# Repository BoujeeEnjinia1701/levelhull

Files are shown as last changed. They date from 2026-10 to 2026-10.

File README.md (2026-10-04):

# LevelHull

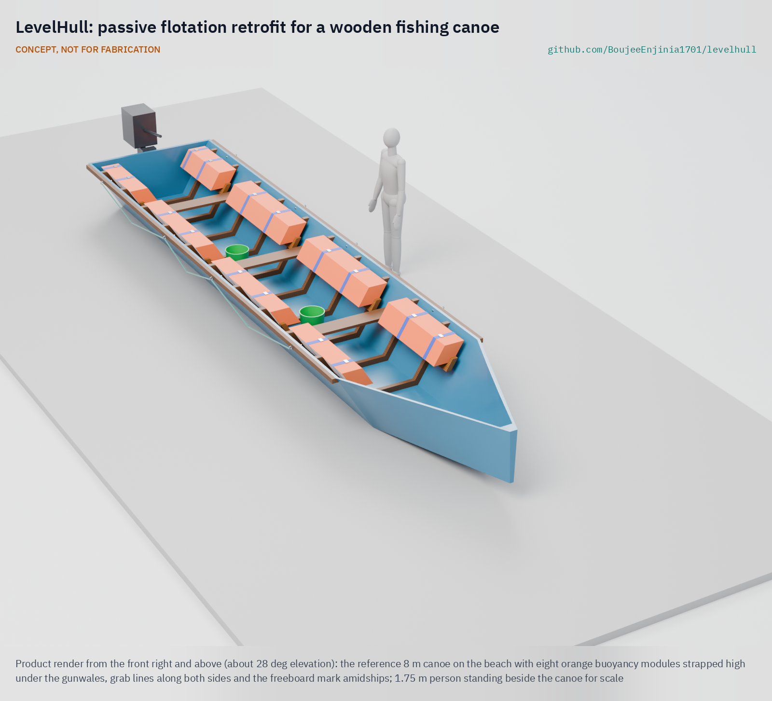
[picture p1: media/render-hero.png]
LevelHull: passive flotation retrofit for a wooden fishing canoe


     

**Area:** Food and water security · **TRL:** 3 of 9 (proof of concept on paper) · **Value-engineering target:** USD 1,000 for two prototype canoes (estimated cost of the constructable design USD 1,360) · **Difficulty:** 3 of 5

Adds passive buoyancy so a swamped wooden fishing canoe floats level and can be bailed.

> CONCEPT, NOT FOR FABRICATION. LevelHull is a TRL 3 design on paper: it has not been built or tested, it is not certified lifesaving equipment, and it is never a substitute for life jackets.

## Concept rationale

A swamped boat that stays afloat and upright is a platform the crew can hold, bail and paddle home. The US Coast Guard publishes a level flotation test that checks exactly this for small boats ([USCG](https://www.uscgboating.org/assets/PDF/downloads/FLOTATION.pdf)). Wooden fishing canoes in lakes and coastal waters elsewhere have no such built-in flotation. LevelHull is a retrofit kit: closed-cell foam modules fitted high along both sides of the hull, just under the gunwale, sized so that when a wave fills the canoe it floats level with freeboard, and the crew bails it out and carries on.

The kit is passive. Nothing moves, nothing inflates and nothing needs power, so it keeps working after years in the sun and in a wet hull. It is designed to be sized with a simple volume sheet and fitted by a local boatbuilder with hand tools. It is never a substitute for life jackets; it is a second layer for when a boat swamps.

## Burning platform

About 1,500 fishers drown on Lake Victoria every year, roughly 1,000 of them in bad weather; 69 % of those who drowned in storms wore no life jacket, and about half of incidents happen at night ([The Conversation](https://theconversation.com/lake-victoria-why-so-many-fishers-are-dying-and-what-can-be-done-about-it-232006)). Worldwide, more than 100,000 people die in fishing each year ([Pew, 2022](https://www.pew.org/en/research-and-analysis/issue-briefs/2022/11/more-than-100000-fishing-related-deaths-occur-each-year-study-finds)).

Progress is slowest where these boats are most common: the WHO African Region has cut its drowning rate by only 3 % since 2000 ([WHO, 2024](https://www.who.int/news/item/13-12-2024-drowning-deaths-decline-globally-but-the-most-vulnerable-remain-at-risk)). Certified lifesaving equipment is often not affordable or available there, which is why the RNLI supports locally built, sustainable lifesaving equipment in its international work ([RNLI](https://rnli.org/what-we-do/international/lifesaving-interventions/sustainable-lifesaving-equipment)).

## Where it could be used

### By industry

| Industry | Use |
| --- | --- |
| Small-scale capture fisheries | Retrofit flotation for wooden canoes on lakes, rivers and coasts |
| Boatbuilding (artisanal yards) | A documented add-on that local builders can size and fit |
| Fisheries management and safety at sea programmes | A low-cost measure alongside life jackets, weather warnings and training |
| Water transport and ferries on inland waters | Flotation for small wooden passenger and cargo canoes |
| Disaster response | Buoyancy modules reused in flood boats (for example the sibling LaneSkiff concept) |

### By country or region

| Country or region | Why it matters there |
| --- | --- |
| Lake Victoria (Kenya, Uganda, Tanzania) | About 1,500 fishers drown on the lake each year, about 1,000 in bad weather ([The Conversation](https://theconversation.com/lake-victoria-why-so-many-fishers-are-dying-and-what-can-be-done-about-it-232006)). |
| WHO African Region | The drowning rate has fallen by only 3 % since 2000 ([WHO, 2024](https://www.who.int/news/item/13-12-2024-drowning-deaths-decline-globally-but-the-most-vulnerable-remain-at-risk)). |
| Worldwide small-scale fisheries | More than 100,000 people die in fishing each year ([Pew, 2022](https://www.pew.org/en/research-and-analysis/issue-briefs/2022/11/more-than-100000-fishing-related-deaths-occur-each-year-study-finds)). |
| United States | The US Coast Guard publishes a level flotation test for small boats, the benchmark this kit will be tested against ([USCG](https://www.uscgboating.org/assets/PDF/downloads/FLOTATION.pdf)). |

## What sparked the idea

The idea started with the numbers from Lake Victoria: about 1,500 fishers drowning each year, most of them in bad weather, and 69 % of storm victims wearing no life jacket ([The Conversation](https://theconversation.com/lake-victoria-why-so-many-fishers-are-dying-and-what-can-be-done-about-it-232006)). Many of those deaths begin with a canoe filling with water. If a swamped canoe stayed afloat and level, the crew would have something to hold and a boat they could bail, even without a life jacket.

## Problem

Wooden fishing canoes swamp in storms and waves, and once full of water they can roll or sink, leaving the crew in the water. Most small-scale fishers in these boats cannot swim to shore and many wear no life jacket.

Full problem statement: [docs/01-problem.md](docs/01-problem.md)

## Concept

A retrofit kit of eight closed-cell polyethylene foam modules, four a side, fitted high under the gunwale on hardwood battens screwed to the canoe's frames and held by webbing straps. When a wave swamps the canoe, the modules cut the waterline along both sides, so it floats upright and level with about 100 mm of freeboard; the crew hold the grab lines, climb back in and bail. On paper, the 8 m reference canoe with a 15 hp motor and four crew holding on keeps 92 mm of freeboard at its lowest point, with 2.45 times the needed lift in reserve; the same foam laid on the floor would barely reach the surface and would lose all roll stiffness with a few kilograms more load. Never a substitute for life jackets.

Full design precis: [docs/02-concept.md](docs/02-concept.md) · Requirements: [docs/03-requirements.md](docs/03-requirements.md) · Calculations and sizing calculator: [docs/04-calcs/01-sizing.md](docs/04-calcs/01-sizing.md) · Prototype build plan: [docs/05-build-plan.md](docs/05-build-plan.md) · Design decisions: [docs/06-design-decisions.md](docs/06-design-decisions.md)

## Key components

- Eight buoyancy modules: four 50 mm layers of closed-cell polyethylene foam, 220 mm wide by 200 mm high, in sewn PVC tarpaulin covers
- Hardwood shelf battens screwed into the frames with M8 coach screws that stop short of the planks, and end chocks
- Two 50 mm webbing hold-down straps per module with stainless D-ring buckles
- Grab lines along both sides on through-bolted eye bolts
- Two bailers on lanyards, painted freeboard marks and a swamp test
- A plywood setting gauge for fitting, and an open sizing calculator for other canoes

## Building the prototype

The [prototype build plan](docs/05-build-plan.md) (LVH-BLD-001, plan, not yet built) is also the fitting guide for a local boatbuilder. It covers the kit component by component, with making sketches for the six made parts, close-ups of six joints and a picture for each of ten fitting steps. The foam is cut with a knife, the covers are sewn by a tailor, the battens are ripped and planed from hardwood, and everything is fitted with hand tools in about a day. No fitted canoe goes fishing before its fixings are pull-tested and it passes a swamp test in sheltered, shallow water with a safety boat and everyone in life jackets, which is TRL 4 work.

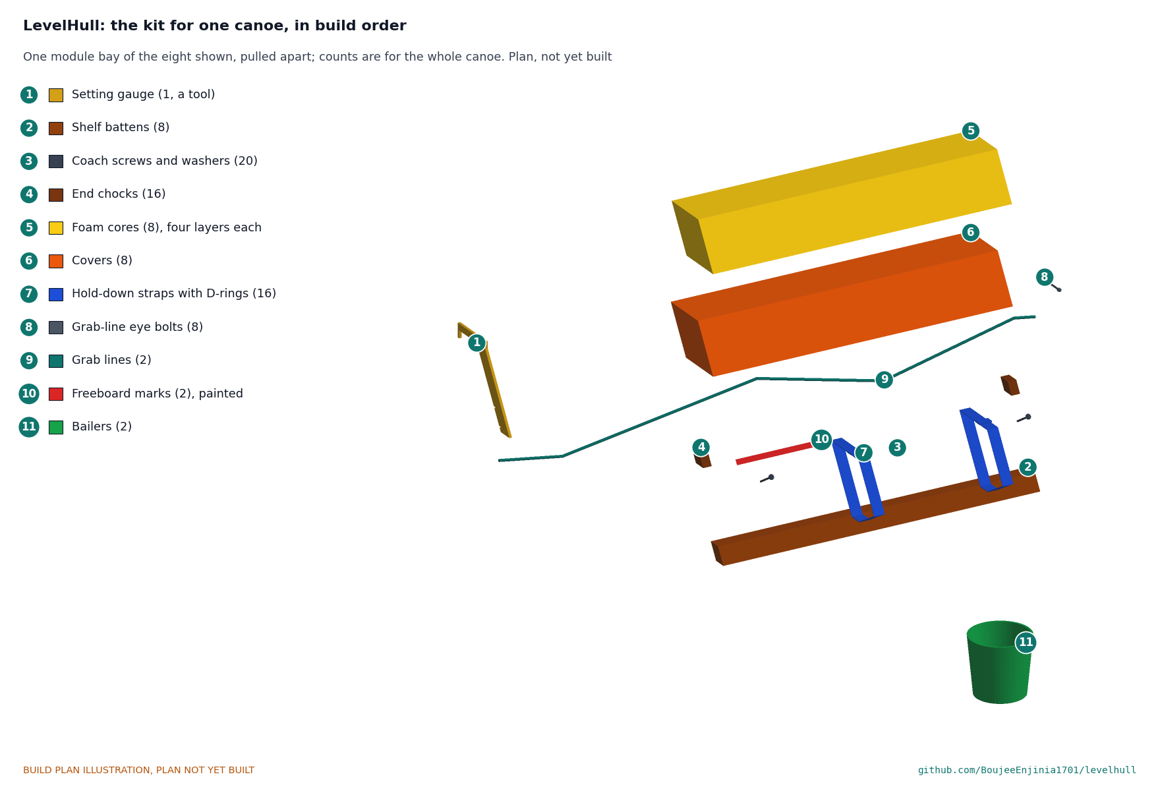
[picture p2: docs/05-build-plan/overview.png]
LevelHull build overview


## Safety

> Published as an open engineering reference, not certified lifesaving equipment.
>
> LevelHull is never a substitute for life jackets. Crews should wear life jackets whenever they are on the water.
>
> A swamped boat with flotation is still at risk in breaking waves and cold water; the kit buys time, it does not make a boat safe.
>
> Each fitted canoe must be swamp-tested in sheltered, shallow water with safety cover before use.
>
> Modules must be fixed so they cannot tear free when the boat is full of water; each fixing carries at least twice its share of the full lift.
>
> With all four crew holding one side, the low gunwale comes within about 30 mm of the water: spread out along both grab lines.
>
> This design is published as an open engineering reference. It is not certified equipment.

## Repository layout

| Folder | Contents |
| --- | --- |
| `docs/` | Problem, concept, requirements, calculations and design decisions |
| `cad/src/` | build123d Python source, the source of truth for all geometry |
| `cad/step/`, `cad/stl/` | Exported models for FreeCAD, other CAD tools and printing |
| `cad/drawings/` | 2D sketches and dimensioned drawings |
| `bom/` | Bill of materials |
| `electronics/` | KiCad schematics and PCB layouts |
| `firmware/` | Microcontroller code |
| `media/` | Renders, perspectives and photos |
| `build-log/` | Dated prototyping notes |

## Documentation

Controlled documents follow the portfolio [documentation standard](.kit/STANDARDS.md). Each carries a document ID (LVH-PRC-001 for the precis), a version and a revision history. Branded PDFs are built with `python .kit/render.py` and attached to GitHub Releases when a document is tagged, for example `LVH-PRC-001/v1.0`.

## Credits

Designed by Amish Chadha at Design Molecule Labs. See [CONTRIBUTORS.md](CONTRIBUTORS.md) for roles. To cite this design, use [CITATION.cff](CITATION.cff) (GitHub shows it as "Cite this repository").

AI assistance (Claude) was used to accelerate prototype documentation and first-pass research. Design direction and all decisions are Amish Chadha's, recorded in this repository's decision records (`docs/decisions/`).

## Licenses

- **Hardware** (CAD, drawings, BOM, electronics): [CERN-OHL-S v2](LICENSE)
- **Software** (firmware, scripts, notebooks): [MIT](LICENSE-SOFTWARE)

A project of the [Design Molecule](https://designmolecule.com) lab.

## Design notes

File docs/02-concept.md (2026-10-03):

---
doc_id: LVH-PRC-001
title: LevelHull design precis
project: LevelHull
doc_type: Precis
version: "0.3"
status: Draft
date: '2026-10-03'
author: Amish Chadha
license: CERN-OHL-S-2.0
revisions:
- version: "0.1"
  date: '2026-09-30'
  author: Amish Chadha
  change: Initial scaffold
- version: "0.2"
  date: '2026-10-03'
  author: Amish Chadha
  change: TRL 2 and 3 update; modules high under the gunwale, constructable kit (LVH-DDR-001, LVH-DDR-002), first-order numbers, safety
- version: "0.3"
  date: '2026-10-03'
  author: Amish Chadha
  change: Modules widened from 200 to 220 mm (LVH-DDR-003); first-order numbers updated
---

# LevelHull design precis

Adds passive buoyancy so a swamped wooden fishing canoe floats level and can be bailed.

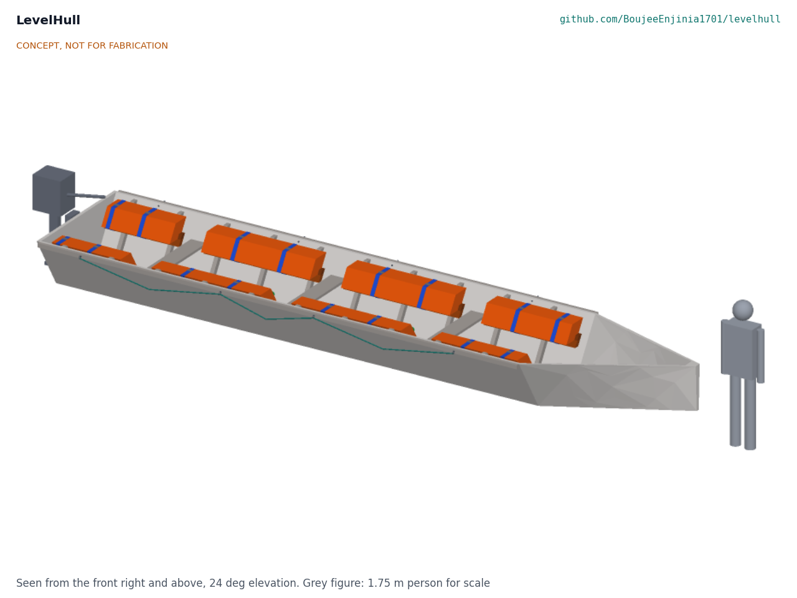
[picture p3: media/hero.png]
LevelHull fitted in the reference canoe


*Figure 1. The kit fitted in the 8 m reference canoe, with a 1.75 m person for scale (concept render).*

## How it works

Eight buoyancy modules of closed-cell polyethylene foam, four on each side, sit high along the inside of the canoe, just under the gunwale, between the thwarts. Each module rests on a hardwood shelf batten screwed to the canoe's frames and is held down by two webbing straps. When a wave fills the canoe, the water inside is simply part of the lake: it carries nothing, and the canoe now floats on its foam and timber alone. Because the modules are high, they cut the waterline along both sides, like the floats of a raft, so the swamped canoe floats upright and level with its gunwale about 100 mm out of the water. The crew hold the grab lines along both sides, then climb in and bail with the two bailers. A painted freeboard mark on each side and a swamp test in sheltered water let the owner check the fit.

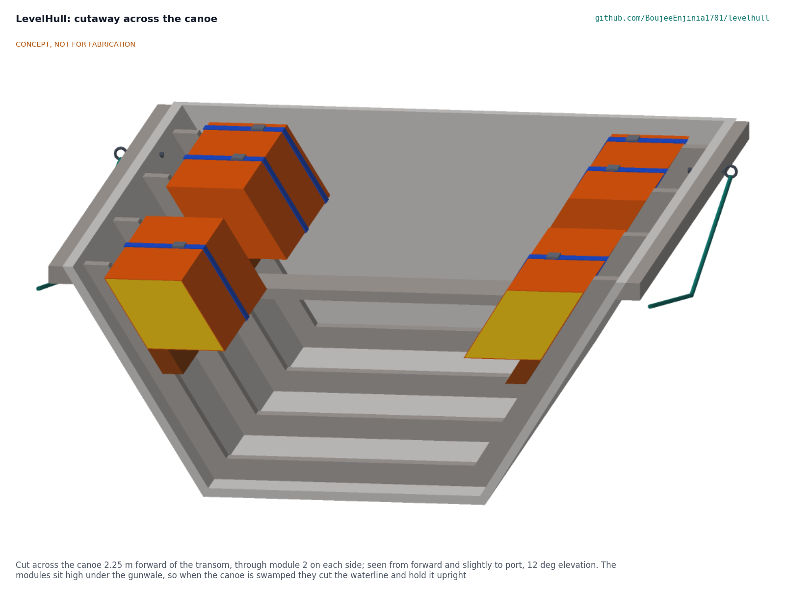
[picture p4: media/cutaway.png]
Cutaway across the canoe


*Figure 2. Cut across the canoe through module 2: the modules lie on the frame faces under the gunwale.*

## Components

*Table 1. Components (numbers are BOM lines in `bom/bom.csv`).*

| # | Component | Role |
| --- | --- | --- |
| 1 | Setting gauge | Plywood fitting tool that marks the batten height on every frame |
| 2 | Shelf battens | Hardwood rails screwed to the frames; each carries one module |
| 3 | Coach screws M8 x 100 | One into every frame a batten crosses; take the module's lift into the frames |
| 4 | End chocks | Stop the module sliding fore and aft |
| 5 | Foam cores | Four 50 mm layers of closed-cell polyethylene foam: the buoyancy |
| 6, 7 | Covers | Sewn PVC tarpaulin sleeves that shield the foam from sun, fuel and abrasion |
| 8, 9 | Hold-down straps and D-ring buckles | Two webbing loops per module round module and batten |
| 10, 11 | Grab-line eye bolts and grab lines | Something to hold for the crew in the water |
| 12 | Bailers | Two 10 L buckets on lanyards |
| 13 | Swamp test kit | Painted freeboard marks and an inclinometer for the swamp test |
| 14 | Sealer | Seals batten ends, chocks and every screw hole |
| (calc) | Sizing calculator | `docs/04-calcs/sizing.py` sizes the modules for any canoe (MIT) |
| (BLD) | Fitting guide | The build plan, LVH-BLD-001 |

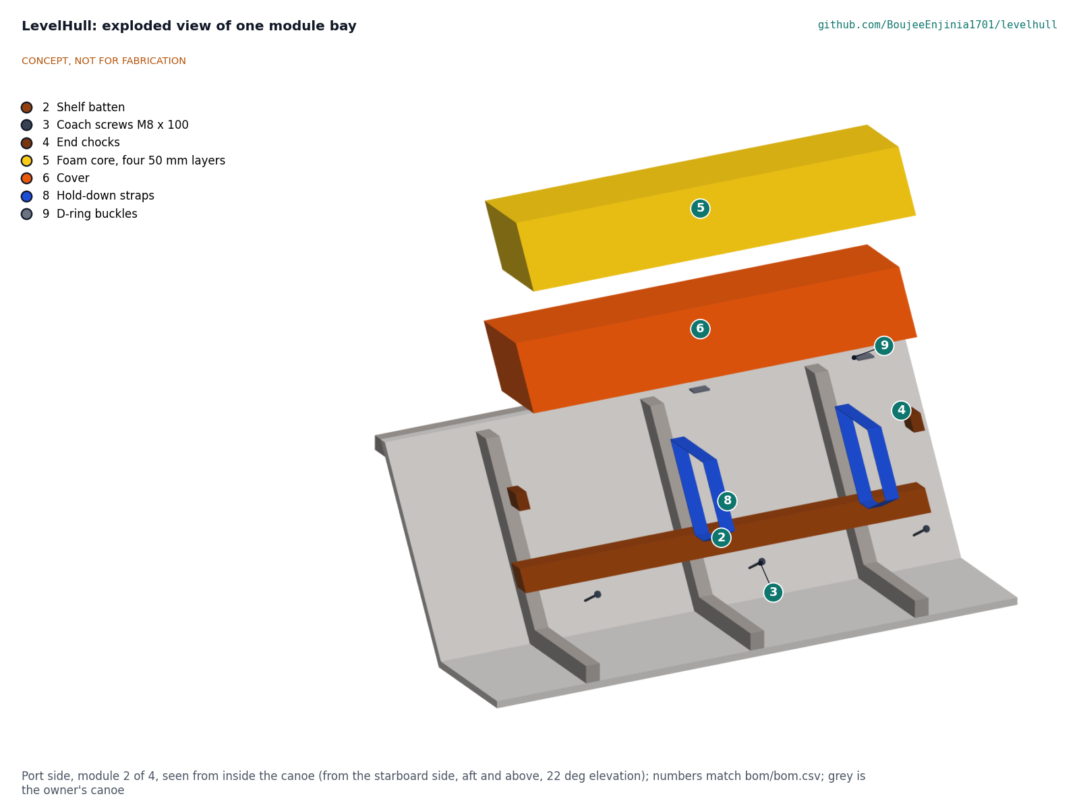
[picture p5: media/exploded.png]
Exploded view of one module bay


*Figure 3. One module bay pulled apart; numbers match the BOM.*

## Key design choices

All decided under Amish's pre-approval of 2026-10-03 (LVH-DDR-001 and LVH-DDR-002).

- **High, not low.** Modules under the gunwale give the swamped canoe roll stiffness; on the floor the same foam leaves it nearly neutral in roll (Table 2).
- **Foam, not chambers.** Closed-cell polyethylene foam keeps its lift when cut or punctured and resists fuel. Polystyrene is excluded (fuel dissolves it), as is open-cell foam (it soaks up water).
- **No credit for the wood.** Wet timber is counted as exactly as dense as water. Lighter timber is a margin, not part of the design.
- **Into the frames, not through the hull.** Battens are screwed into the frames with coach screws that stop 10 mm short of the planking; the only new hull holes are the eight eye bolts in the top plank, above every waterline.
- **Simple parts a beach yard can make.** Ripped hardwood battens, foam strips cut with a knife, sewn tarpaulin sleeves and webbing loops with D-rings; no glue, no moving parts.
- **One reference canoe, a calculator for the rest.** The design is checked on an 8 m, 1.6 m beam canoe with a 15 hp outboard and four crew; the calculator gives the module run for other hulls.

## First-order numbers

From LVH-CAL-001 (`docs/04-calcs/sizing.py`); fresh water, design load unless stated.

*Table 2. First-order numbers.*

| Quantity | Value | Assumption |
| --- | --- | --- |
| Modules | 8, each 220 mm wide x 200 mm high, 4.78 m a side, 0.42 m3 | Reference canoe, thwarts at 1.2, 3.0 and 4.8 m |
| Design net load | 118 kg | Four crew holding on (20 % of 75 kg each), 36 kg motor, anchor, nets, catch |
| Freeboard, swamped | 113 mm amidships, 92 mm lowest (transom) | Timber at 1,000 kg/m3; trim 0.39 deg stern down |
| Reserve | Carries 290 kg at 50 mm freeboard: 2.45 times the design load | |
| Roll stiffness | 761 kg m per radian (metacentric height 3.1 m) | Waterplane of modules and planks |
| Same foam on the floor | Foam top just at the water: heels 10.6 deg with four crew on one side, and no roll stiffness at all with 5 kg more load | For comparison only |
| Four crew on one side | 3.9 deg heel, 44 mm freeboard on the low side | |
| Largest module lost and 5 % water uptake | Still floats, 25 mm freeboard | |
| Bailing to 200 mm freeboard | 1.17 m3, about 6 minutes for two crew (estimate) | 100 L per minute each, calm water |
| Kit mass | 69 kg; dry canoe sits about 11 mm deeper | |
| Share of the inside volume | 8.4 % | |
| Parts cost | USD 682 per canoe; USD 1,360 for two | Value-engineering target USD 1,000 for two |

## Patent design-arounds

From the preliminary patent, trademark and prior-art screen (not legal advice):

- Passive foam only; no inflation and no inflation mechanism (avoids US9139267B2, active to about 2032). Sealed chambers are not used either.
- The hull-volume sizing method is published openly in `docs/04-calcs/sizing.py` under MIT.

## Shared blocks

- Foam module and fixing pattern offered to the sibling LaneSkiff concept (proposed there, not here).
- CalRig proof-load for strap and screw pull-out at TRL 4.

## Safety

> **Safety:** LevelHull is published as an open engineering reference, not certified lifesaving equipment. It is never a substitute for life jackets: crews should wear life jackets whenever they are on the water. A swamped canoe with flotation is still at risk in breaking waves, at night and in cold water; the kit buys time to bail and be seen, it does not make the boat safe. With all four crew holding one side the low gunwale comes within about 30 mm of the water, so crews spread out along both grab lines. Every fitted canoe has its fixings pull-tested and is swamp-tested in sheltered, shallow water with a safety boat and every person in a life jacket before use (LVH-BLD-001, sections 5 and 6). The modules must be fixed so they cannot tear free when the canoe is full of water; each fixing carries at least twice its share of the full lift.

This design is published as an open engineering reference. It is not certified equipment.

## Open questions

None for the design; decisions are in the register (`docs/06-design-decisions.md`), and facts that need real hulls and parts are listed there under "To confirm when parts are bought".

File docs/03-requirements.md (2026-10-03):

---
doc_id: LVH-REQ-001
title: LevelHull requirements
project: LevelHull
doc_type: Requirements
version: "0.3"
status: Draft
date: '2026-10-03'
author: Amish Chadha
license: CERN-OHL-S-2.0
revisions:
- version: "0.1"
  date: '2026-09-30'
  author: Amish Chadha
  change: Initial scaffold
- version: "0.2"
  date: '2026-10-03'
  author: Amish Chadha
  change: Targets fixed on the reference canoe; R11 to R13 added; TRL 3 status from LVH-CAL-001
- version: "0.3"
  date: '2026-10-03'
  author: Amish Chadha
  change: 'Modules widened 10 % for R12 and R13 on Amish''s decision of 2026-10-03 ("10A", LVH-DDR-003); targets unchanged; TRL 3 status updated from LVH-CAL-001 v0.2'
---

# LevelHull requirements

Requirements for the kit fitted to the reference canoe (8.0 m, 1.6 m beam, 0.65 m deep, 15 hp outboard, four crew). Other hulls are sized to the same requirements with the calculator. Status is the paper result at TRL 3 from LVH-CAL-001; every requirement is verified by test at TRL 4.

*Table 1. Requirements.*

| ID | Requirement | Target | Verification (TRL 4) | TRL 3 status |
| --- | --- | --- | --- | --- |
| R1 | Swamped canoe stays afloat with its design load | Design net load 118 kg (crew holding on, motor, gear, catch) carried for at least 1 h | Swamp test in sheltered water, based on the USCG level flotation method | Met on paper: carries 2.45 times the design load at 50 mm freeboard |
| R2 | Freeboard when swamped | At least 50 mm at the lowest point of the gunwale, design load, fresh water | Measured during swamp test | Met on paper: 92 mm (113 mm amidships) |
| R3 | Floats level when swamped | Heel and trim each within 10 deg, crew in the water not holding on, and with crew holding on both sides | Inclinometer reading during swamp test | Met on paper: 0.0 deg heel, 0.14 deg trim; 0.39 deg trim with crew holding on |
| R4 | Crew can bail the swamped canoe | Two crew bail to 200 mm freeboard in 15 min or less, calm water | Timed bail-out trial | Met on paper (estimate): about 6 min |
| R5 | Volume taken from the working space | 10 % or less of the inside volume | Measured on the fitted canoe | Met: 8.4 % |
| R6 | Material water uptake | Foam gains less than 5 % of its lift in mass after 30 days immersed | Immersion and weighing of samples | Met on supplier data (under 1 % by volume); to confirm by test |
| R7 | Fixing strength | Each fixing holds 2 times its share of the full lift without pull-out | CalRig proof-load of a batten, screws and strap in a test panel | Met on paper: screw factor 5.0, D-ring 13.3, webbing 66 |
| R8 | Fitting | A local builder fits the kit in one working day with hand tools, modules made beforehand | Timed fitting with the partner builder | Met on paper (estimate): about 6.3 h |
| R9 | Durability | No cracking or loss of lift after 12 months of normal use | Field inspection of pilot canoes | Cannot be shown on paper |
| R10 | Cost | Parts for kits on two canoes against the value-engineering target of USD 1,000 | Costed bill of materials | USD 1,360: over the value-engineering target by USD 360 |
| R11 | Reserve lift | At least 1.5 times the design net load carried at 50 mm freeboard | Swamp test with added weights | Met on paper: 2.45 |
| R12 | Damage tolerance | Still floats with the largest module lost and 5 % water uptake | Swamp test with one module removed | Met on paper: 25 mm freeboard, 1.5 deg heel (was 9 mm before the modules were widened) |
| R13 | Crew on one side | Heel within 10 deg with all four crew holding one grab line | Swamp test | Met on paper: 3.9 deg (low-side freeboard 44 mm, was 31 mm) |

## Assumptions

- Modules 220 mm wide by 200 mm high (widened from 200 mm on Amish's decision 10A of 2026-10-03: "1A 2A 3A 4A 5A 6A 7A 8A 9A 10A 11A").
- Reference canoe: planked, flat bottom 0.8 m wide, sides flared 31.6 deg, frames 50 x 60 mm at 600 mm, thwarts at 1.2, 3.0 and 4.8 m from the transom.
- Wet hull timber is counted as exactly as dense as water (no net lift from the hull).
- A crew member holding on with head and shoulders out puts 20 % of a 75 kg body on the canoe.
- Closed-cell polyethylene foam of about 30 kg/m3 with under 1 % water uptake by volume is available to the first partner.
- Owners accept 8.4 % of the inside volume, high along the sides, in exchange for flotation.
- The USCG level flotation method is adapted as a design benchmark only; the kit is not certified to it.

> **Safety:** These requirements describe flotation for the boat, not for people. Life jackets remain the first line of defence; the swamp tests behind R1 to R4 and R11 to R13 are run in sheltered, shallow water with a safety boat and every person in a life jacket.

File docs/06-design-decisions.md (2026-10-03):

---
doc_id: LVH-DEC-001
title: LevelHull design decisions register
project: LevelHull
doc_type: Design decisions register
version: "0.2"
status: Draft
date: '2026-10-03'
author: Amish Chadha
license: CERN-OHL-S-2.0
revisions:
- version: "0.1"
  date: '2026-10-03'
  author: Amish Chadha
  change: Register opened; all decisions made under Amish's 2026-10-03 pre-approval
- version: "0.2"
  date: '2026-10-03'
  author: Amish Chadha
  change: Decision 10A recorded (modules widened for R12 and R13, LVH-DDR-003); value engineering updated
---

# LevelHull design decisions register

Every design decision still to be made, and every decision made, in one place. Each decision is argued in full in its decision record under `docs/decisions/`; this register is the index Amish works from. The build plan (`docs/05-build-plan.md`) describes the design as it stands and does not list decisions.

> **Safety:** Several entries below set safety limits (where the modules sit, no credit for the wood, screws kept out of the planking, the pull test and the swamp test rules). Each takes the conservative option and names the evidence that would relax it. LevelHull is never a substitute for life jackets.

## Open decisions

None. All decisions were made under Amish's 2026-10-03 pre-approval and his requirement decisions of 2026-10-03.

## To confirm when parts are bought

These are facts that can only be settled with real parts, a real canoe or the first partner. None changes a decision; each may change a size or a limit.

*Table 1. Items to confirm.*

| # | What to confirm | Why it matters | Source |
| --- | --- | --- | --- |
| 1 | Foam: density about 30 kg/m3, water uptake under 1 % by volume, fuel resistance, on the supplier's data sheet; then 30 days immersion of samples | R6, and every freeboard figure | LVH-CAL-001, A6; LVH-DDR-002, A4 |
| 2 | First canoes: frame spacing (600 mm assumed) and depth (60 mm), side slope, thwart positions, timber, gunwale and strake sizes | Batten height, screw length, module lengths and the gauge | LVH-DDR-002, A1 |
| 3 | Hull mass and timber volume of the first canoes | Size of the unclaimed wood margin (D3) | LVH-DDR-001, D3 |
| 4 | Condition of the frame-to-plank fastenings | Each frame takes up to 0.19 kN of lift | LVH-DDR-002, A3 |
| 5 | Webbing breaking strength (10 kN assumed), D-ring pair (4 kN) and coach screw sideways strength in the canoe's timber (1.5 kN) | R7 factors | LVH-CAL-001, section 7 |
| 6 | Real motor mass and the gear, catch and crew of the partner's fishery | Design net load of 118 kg | LVH-CAL-001, A3 to A5 |
| 7 | Bailing rate with the local bailer (100 L per minute per person assumed) | R4 | LVH-CAL-001, A8 |
| 8 | Price of polyethylene foam sheet near the first fishery (USD 55 a sheet assumed) | Foam is 48 % of the kit cost | `bom/bom.csv`, line 5 |

## Value engineering

Value-engineering target: USD 1,000 (a hypothetical control target, not a limit) for the kits for two prototype canoes. Estimated cost of the constructable design: USD 1,360 (USD 360 over the target); one kit is USD 682. Main cost drivers and savings worth trying:

- The largest lines are the foam (USD 330 a kit, six sheets), the tarpaulin covers and their sewing parts (USD 100), the battens (USD 56) and the coach screws (USD 43).
- Savings worth trying: buy foam by the block from a fishing-float or packaging maker and cut it locally (perhaps USD 100 a kit); hot-galvanised screws and D-rings in place of stainless where the canoe is used in fresh water (about USD 30); covers from used truck tarpaulin in good condition (about USD 50); a three-layer module on hulls whose weighed timber gives a proven wood margin (D3), cutting foam by a quarter.
- The gauge is made once per hull shape and the calculator is free, so a builder fitting a fleet of the same canoe spreads those costs.

## Decisions made

*Table 2. Decisions made.*

| Date | Decision | Decided by | Record |
| --- | --- | --- | --- |
| 2026-10-03 | TRL 2 review items D1 to D10: modules high under the gunwale, not low; closed-cell polyethylene foam in covers, not chambers or polystyrene; no lift counted from the hull timber; one reference canoe (8.0 m, 15 hp, four crew) with an open calculator for others; crew in the water at 20 % of body weight; re-entry step stays parked; grab lines along both sides; life jacket message in every document and test; first co-design candidates (a beach management unit on the Kenyan shore of Lake Victoria with its canoe builders, a regional fisheries research institute, a sea-safety programme; none approached yet); R11 to R13 added; pitch, problem, design-arounds and budget unchanged | Amish, pre-approval of 2026-10-03: "start with the first 14 repos from the list of 29 projects. I pre-approve the batch runs along with any recommendations you come up with. I also accept any cost overruns or variations from the assumed scope cost." | LVH-DDR-001 |
| 2026-10-03 | Design for construction, changes C1 to C12: modules high on the frame faces; four modules a side between thwarts; parallelogram stacks of equal strips; shelf battens; coach screws into frames only, 10 mm short of the planks; end chocks; webbing loops with D-ring buckles in the bays; no glue; sewn tarpaulin covers; setting gauge; grab-line eye bolts above the waterline; freeboard marks and bailers | Amish, same pre-approval | LVH-DDR-002 |
| 2026-10-03 | Assumptions A1 to A5: frames at most 600 mm apart and 60 mm deep, else shorter screws and a third frame, never through the planks; timber as dense as water; sound frame fastenings checked before fitting; foam data to confirm; fixing strengths to confirm | Amish, same pre-approval | LVH-DDR-002 |
| 2026-10-03 | No fishing use before the batten pull test, a one-bay proof load to twice the full lift, and a swamp test in sheltered shallow water with a safety boat and every person in a life jacket (conservative; a gate, not relaxed) | Amish, same pre-approval | LVH-BLD-001, sections 5 and 6 |
| 2026-10-03 | Crews spread along both grab lines: with all four on one side the low gunwale comes within 31 mm of the water (44 mm with the wider modules of LVH-DDR-003) (conservative; relaxed only if a swamp test shows more) | Amish, same pre-approval | LVH-CAL-001, section 4 |
| 2026-10-03 | Appearance model departures: a sand beach slab and a 1.75 m mannequin beside the canoe, and a repeated cut-back module bay for the detail view, drawn for the renders only; canoe topsides shown painted | Amish, same pre-approval | docs/REVIEW.md, TRL 3 section |
| 2026-10-03 | Decision 10A for R12 and R13: foam modules enlarged about 10 % by widening them from 200 to 220 mm (height, lengths, positions and fixings unchanged). R12: 25 mm lowest freeboard with the largest module lost (was 9 mm); R13: 3.9 deg heel, 44 mm on the low side (was 4.0 deg, 31 mm); kit 68.9 kg; USD 1,360 for two canoes | Amish, 2026-10-03: "1A 2A 3A 4A 5A 6A 7A 8A 9A 10A 11A" | LVH-DDR-003 |

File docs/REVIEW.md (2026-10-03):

# Review note: LevelHull

## Session 2026-09-30: scaffolded

### What was done

- Repository created from kit 1.6.0 at TRL 1, target TRL 2.
- `docs/01-problem.md` (LVH-PRB-001 v0.1): problem with cited evidence, users, environment, constraints, prior work, open questions.
- `docs/02-concept.md` (LVH-PRC-001 v0.1): how it works, components, patent design-arounds, shared blocks, safety.
- `docs/03-requirements.md` (LVH-REQ-001 v0.1): 10 proposed requirements.
- `README.md` with concept rationale, burning platform, where it could be used, and what sparked the idea.

### Next

- Run `/populate` to bring the repo to a strong TRL 2 with concept media.

## Session 2026-10-03: TRL 2 (populate)

Run as the first half of `/to-trl3` under Amish's pre-approval of 2026-10-03: "start with the first 14 repos from the list of 29 projects. I pre-approve the batch runs along with any recommendations you come up with. I also accept any cost overruns or variations from the assumed scope cost." Kit 1.7.0 installed.

### What was done

- `docs/01-problem.md` (LVH-PRB-001 v0.2): constraints restated (value-engineering target, no new holes below the waterline), open questions settled, first co-design candidates, safety section.
- `docs/02-concept.md` (LVH-PRC-001 v0.2): how it works, components with BOM numbers, key design choices, first-order numbers, design-arounds kept, safety.
- `docs/03-requirements.md` (LVH-REQ-001 v0.2): 13 measurable requirements (R11 to R13 added) with TRL 3 status.
- Concept media from `cad/src/concept_media.py`: `media/hero.png` (1.75 m person for scale), `media/cutaway.png` (a cut across the canoe), `media/exploded.png` (one module bay with BOM callouts), `media/concept-blueprint.png`, `.pdf` and `.svg` (LVH-DWG-010), `media/model.glb` (3.4 MB, coarse tessellation) and `media/viewer.html`. No flow diagram: the kit moves no energy or material.
- `bom/bom.csv`: 14 priced lines.

### Results

- The TRL 1 arrangement (foam low along the sides) does not work: with the same foam on the floor the swamped canoe has almost no roll stiffness and rolls over with the crew on one side. Modules high under the gunwale fix this.

### Requirements not met

- R10: over the value-engineering target (see TRL 3).
- R9 cannot be shown on paper.

### Decisions made under the pre-approval

LVH-DDR-001, items D1 to D10: modules high under the gunwale; closed-cell polyethylene foam in covers; no lift counted from the hull timber; one reference canoe with an open calculator; crew in the water at 20 % of body weight; re-entry step stays parked; grab lines; life jacket message everywhere; first co-design candidates (not approached); R11 to R13 added.

### Safety concerns

- A swamped canoe that floats is still dangerous in breaking waves, at night and in cold water; the kit is never a substitute for life jackets, and it must not be promoted as one.

## Session 2026-10-03: TRL 3 (advance and build plan)

Run as the second half of `/to-trl3` under the same pre-approval, which counts as the TRL 2 approval. Not committed or pushed (batch run).

### What was done

- `cad/src/model.py`: parametric build123d model of the kit in the reference canoe (8.0 m, 1.6 m beam, 0.65 m deep, flared 31.6 deg, 15 hp outboard); 126 of 126 constructability checks pass (overlaps with planks, frames and thwarts; module, batten and chock contact; screw depth in the frames and clear of the planks; straps in the bays; eye bolts through the strake; gauge fit; clear width). Exports `cad/step/levelhull-assembly.step`, `levelhull-kit.step`, `reference-canoe-context.step`, the four foam cores, chock and gauge, and STL of the battens, chock and gauge.
- `docs/04-calcs/01-sizing.md` (LVH-CAL-001 v0.1) with `docs/04-calcs/sizing.py` (also the MIT sizing calculator) and `results.csv`: swamped equilibrium, heel and trim, off-design cases, high against low placement, space and bailing, fixings, fitting time, cost and a sizing sheet for other hulls.
- `cad/src/sheets.py`: general arrangement `cad/drawings/LVH-DWG-001` (SVG, PDF, PNG) at Rev P2, with section A-A at 1:20.
- `cad/src/build_plan_media.py`: `docs/05-build-plan/overview.png`, 6 making sketches `cad/drawings/LVH-DWG-101` to `106`, 6 joint close-ups and 10 step pictures.
- `docs/05-build-plan.md` (LVH-BLD-001 v0.1), `docs/06-design-decisions.md` (LVH-DEC-001 v0.1), `docs/decisions/0001-trl2-review-decisions.md` (LVH-DDR-001) and `docs/decisions/0002-design-for-construction.md` (LVH-DDR-002).
- `cad/src/product_model.py` (appearance model) and render scenes exported with `.kit/export_views.py` to `/home/claude/renders/levelhull` for hero, exploded and detail views; photoreal renders and cards are made on Amish's Mac.
- `project.yaml`: trl 3, trl_target 3, `design_state: constructable`, evidence listed; `budget_usd` unchanged. README leads with `media/render-hero.png` and has a "Building the prototype" section.

### Results

- Eight modules, 200 x 200 mm, 4.78 m a side, 0.38 m3 of foam; kit 67 kg; 7.6 % of the inside volume.
- Swamped at the design load (118 kg net: four crew holding on, 36 kg motor, gear, catch), fresh water, no lift counted from the timber: 105 mm freeboard amidships, 80 mm at the lowest point, trim 0.45 deg; roll stiffness 742 kg m per radian; 2.2 times the design load carried at 50 mm freeboard.
- Same foam on the floor: 17 kg m per radian; rolls over with four crew on one side.
- Four crew on one side: 4.0 deg heel, 31 mm low-side freeboard. Largest module lost and 5 % uptake: still afloat with 9 mm. Typical 750 kg/m3 timber would add about 58 mm.
- Bailing to 200 mm freeboard: about 6 minutes for two crew (estimate). Fixing factors: coach screw 5.5, D-ring 14.6, webbing 73. Fitting about 6.3 hours.
- Value-engineering target: USD 1,000. Estimated cost of the constructable design: USD 1,350 for two canoes (USD 350 over the target); USD 677 for one kit.

### Requirements not met

- R10: over the value-engineering target by USD 350. Foam is 49 % of a kit; the overrun is accepted under the pre-approval and `budget_usd` is unchanged.
- R9 (12 months without loss of lift) and the test half of R6 cannot be shown on paper.
- R12 is met with a small margin (9 mm), and R13 leaves only 31 mm on the low side; both are recorded as operating rules, not redesigned.

### Decisions made under the pre-approval

- LVH-DDR-002: design for construction, changes C1 to C12 and assumptions A1 to A5.
- No fishing use before the pull test, a one-bay proof load and a swamp test with a safety boat and life jackets.
- Crews spread along both grab lines.
- Appearance model departures (renders only): a sand beach slab under the canoe, a 1.75 m mannequin standing beside it, a repeated cut-back module bay for the detail view, and the canoe topsides shown painted blue.

### Build plan findings

- Design changes for construction (2026-10-03), all in LVH-DDR-002: modules high on the frame faces; four modules a side between the thwarts; parallelogram stacks of equal foam strips, no glue; shelf battens; coach screws into the frames only, tips 10 mm short of the planks; end chocks; webbing loops with D-ring buckles in the bays between frames; sewn tarpaulin covers with laced ends; a plywood setting gauge; grab-line eye bolts above the waterline; freeboard marks and bailers on lanyards.
- The only new holes in the hull are the eight eye bolt holes in the top plank, above every waterline.
- Items to confirm with real parts and hulls (foam data, frame sizes, hull mass, frame fastenings, fixing strengths, real loads, bailing rate, foam price) are in LVH-DEC-001.

### Safety concerns

- Flotation for the boat, not for people: never a substitute for life jackets, not certified. Safety stops S1 to S5 in LVH-BLD-001 gate drilling, the first swamp test, entering the water, filling the canoe and fishing use.
- A floating swamped canoe can still roll in breaking waves; the kit buys time to bail and be seen.
- With all crew on one side the low gunwale is 31 mm from the water; crews must spread out.
- The fixings must not tear free: each carries at least twice its share of the full lift on paper, and the pull test and proof load confirm it before any swamp test.

### Recommended next step

The design looks ready for TRL 4 once Amish chooses to start it: fit one kit to a partner's canoe, pull-test and proof-load the fixings with CalRig, and run the first checks in LVH-BLD-001 section 5 in sheltered water with the first co-design candidate.

## 2026-10-03: photoreal renders

Rendered with Blender Cycles on Amish's Mac from `cad/src/product_model.py`; captioned with `.kit/photo_caption.py`; `media/card.png` and `media/social-preview.png` made with `.kit/cards.py`. Views: hero, exploded, detail. image_qc passes and `render.py --check` has no FAIL.

2026-10-03: hero render reframed so the product fills the frame (levelhull).

## 2026-10-03: Amish's requirement decisions carried out

Amish chose option A on every requirement decision put to him: "1A 2A 3A 4A 5A 6A 7A 8A 9A 10A 11A". For LevelHull this is decision 10A (R12 and R13): enlarge the foam modules about 10 %. Not committed or pushed (batch run).

### Changes

- Modules widened from 200 to 220 mm (level width), 200 mm high as before; lengths, positions, battens, chocks, screws and eye bolts unchanged (`cad/src/model.py`). 0.42 m3 of module in all (was 0.38 m3). New model check: four strips of the module width come from a 1,000 mm foam sheet. 127 of 127 constructability checks pass. STEP and STL regenerated.
- `docs/04-calcs/sizing.py` takes the module width from the model everywhere (fixing loads, sizing sheet) and now computes the strap webbing (K3) and the floor comparison with 5 kg more load (F20). `docs/04-calcs/01-sizing.md` v0.2 and `results.csv` re-run.
- `bom/bom.csv`: foam strips 216 mm wide, four to a sheet, still six sheets (no spare strip); tarpaulin 14 to 15 m2 at the same USD 5.00 per m2; straps cut 1.25 m (20 m of the 25 m bought).
- `docs/03-requirements.md` v0.3 (targets unchanged, status updated), `docs/02-concept.md` v0.3, `docs/01-problem.md` v0.3, `docs/05-build-plan.md` v0.2 (foam strips, cover panel 1,040 mm wide, straps 1.25 m), README figures, `docs/decisions/0002-design-for-construction.md` v0.2 (cross-reference), new `docs/decisions/0003-wider-modules-r12-r13.md` (LVH-DDR-003), `docs/06-design-decisions.md` v0.2.
- Pictures: general arrangement `cad/drawings/LVH-DWG-001` at Rev P3; making sketches LVH-DWG-101 to 106, overview, joints and steps regenerated (foam core, cover and strap sketches carry the new sizes); concept media (hero, cutaway, exploded, blueprint, `model.glb`). Appearance model scenes re-exported to `/home/claude/renders/levelhull` (hero, exploded, detail).

### New results

- R12 (still floats with the largest module lost and 5 % uptake): 25 mm lowest freeboard, 1.5 deg heel (was 9 mm). Met on paper with a usable margin.
- R13 (heel within 10 deg with all four crew on one grab line): 3.9 deg, low-side freeboard 44 mm (was 4.0 deg and 31 mm). Met on paper; the low side is still under 50 mm, so the rule that crews spread along both grab lines stays.
- Also changed: R2 92 mm lowest freeboard (was 80); R1 and R11 reserve 2.45 (was 2.17); R3 trim 0.39 deg; R5 8.4 % of the inside volume (was 7.6 %); R7 lowest factor 5.0 (coach screw, was 5.5); R4 about 6 minutes; clear width between module tops 923 mm (check 900 mm).
- Kit mass 68.9 kg (was 67.4 kg).
- Value-engineering target: USD 1,000. Estimated cost of the constructable design: USD 1,360 (USD 360 over the target); USD 682 for one kit. `budget_usd` unchanged.
- Floor comparison: with 0.42 m3 the same foam on the floor just reaches the surface (283 kg m per radian, 10.6 deg with the crew on one side, over the 10 deg limit) and has no roll stiffness with 5 kg more load. The case for the high modules (LVH-DDR-001, D1) stands; the "rolls over" wording is replaced in the documents.

### For Amish

- No new decisions. The photoreal renders (`media/render-*.png`), card and social preview still show the 200 mm modules (a 20 mm change, hardly visible at this scale); re-render on the Mac from the re-exported scenes when convenient.

### Safety

- Unchanged: LevelHull is never a substitute for life jackets; swamp tests only in sheltered, shallow water with a safety boat and everyone in life jackets.

## 2026-10-03: photoreal renders redone after Amish's requirement decisions

Rendered with Blender Cycles on Amish's Mac from `cad/src/product_model.py`; captioned with `.kit/photo_caption.py`; `media/card.png` and `media/social-preview.png` made with `.kit/cards.py`. Views: hero, exploded, detail. image_qc passes and `render.py --check` has no FAIL.

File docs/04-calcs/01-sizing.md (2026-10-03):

---
doc_id: LVH-CAL-001
title: LevelHull sizing calculations
project: LevelHull
doc_type: Calculation note
version: "0.2"
status: Draft
date: '2026-10-03'
author: Amish Chadha
license: CERN-OHL-S-2.0
revisions:
- version: "0.1"
  date: '2026-10-03'
  author: Amish Chadha
  change: First issue at TRL 3, on the constructable design of LVH-DDR-002
- version: "0.2"
  date: '2026-10-03'
  author: Amish Chadha
  change: Modules widened from 200 to 220 mm (LVH-DDR-003, Amish's decision 10A); every result re-run; F20 and K3 added
---

# LevelHull sizing calculations

On paper, eight foam modules of 0.42 m3 in all, fitted high under the gunwales of the 8 m reference canoe, keep the swamped canoe afloat with its motor, gear, catch and four crew holding on, with 92 mm of freeboard at the lowest point of the gunwale, level within half a degree and with 2.45 times the needed lift in reserve at 50 mm freeboard. The same foam laid low on the floor would only just reach the water surface, would heel past the 10 degree limit with the crew on one side, and would lose all roll stiffness with 5 kg more load: that comparison is why the modules sit under the gunwale. The modules were widened from 200 to 220 mm on Amish's decision of 2026-10-03 (LVH-DDR-003) to give more margin in the two weakest cases: the low-side freeboard with all four crew on one side is now 44 mm (was 31 mm) and the damaged case with the largest module lost is now 25 mm (was 9 mm). The cost is USD 360 over the value-engineering target for two canoes.

Every figure comes from `docs/04-calcs/sizing.py`, which imports the parametric model (`cad/src/model.py`), so the sizes here are those of the STEP files, the drawings and the build plan. Tags in square brackets match the script output and `docs/04-calcs/results.csv`. The script is also the open sizing calculator for other hulls (section 8). These are screening estimates for a paper proof of concept; they do not replace the swamp test, which is TRL 4 work.

> **Safety:** LevelHull is flotation for a boat, not lifesaving equipment, and is never a substitute for life jackets. These numbers are for a design review. No fitted canoe is used for fishing before its fixings are pull-tested and it has passed a swamp test in sheltered, shallow water with a safety boat and every person in a life jacket.

## 1. Method and assumptions

The swamped canoe is treated as a set of solid bodies floating in the lake. The water inside the hull is part of the lake and carries nothing. Each body gives lift equal to the water its submerged part displaces and weighs its own mass; the canoe floats where total lift equals total weight. Small heel and trim follow from the second moments of the waterplane (the strips where the modules and planks cut the water surface) and the heights of the lift and the weights: roll stiffness = water density x waterplane moment + lift x height of the centre of lift - weight x height of the centre of weight.

*Table 1. Assumptions.*

| # | Assumption | Value | Basis |
| --- | --- | --- | --- |
| A1 | Water density | 1,000 kg/m3 (lakes); 1,025 kg/m3 checked | Design case is fresh water |
| A2 | Wet hull timber density | 1,000 kg/m3: no net lift from the hull | Conservative (LVH-DDR-001, D3); 750 kg/m3 reported as a margin |
| A3 | Crew holding on | 20 % of 75 kg each (15 kg), at the gunwale | Head and shoulders out of the water; four crew |
| A4 | Outboard motor | 36 kg at full weight, 0.25 m aft of the transom | 15 hp two-stroke; mostly above water when swamped |
| A5 | Gear and catch | 12 kg steel anchor, 40 kg nylon nets, 150 kg fish, full fuel tank | Net in water 10.5, 4.9, 7.1 and 0 kg (a full tank floats) |
| A6 | Foam | Closed-cell polyethylene, 30 kg/m3, under 1 % water uptake by volume | Supplier data to confirm |
| A7 | Kit hardware in water | Covers 9.3 kg PVC, steel 2.8 kg, straps 3.4 kg; battens neutral | Densities 1,300, 7,850 and 1,380 kg/m3 |
| A8 | Bailing | 100 L per minute per person with a 10 L bucket, two bailers, calm water | Estimate |
| A9 | Fixing strengths | Webbing 10 kN, D-ring pair 4 kN, M8 coach screw 1.5 kN sideways in hardwood | To confirm with real parts |

## 2. Geometry of the kit

*Table 2. Kit geometry (reference canoe).*

| Tag | Quantity | Value |
| --- | --- | --- |
| [G1] | Side flare of the canoe | 31.6 deg |
| [G2], [G3] | Modules | 8; 4.78 m a side (880, 1,400, 1,400 and 1,100 mm) |
| [G4] | Module section | 220 mm wide (level) x 200 mm high, a parallelogram matching the flare (was 200 x 200 mm; LVH-DDR-003) |
| [G5], [G6] | Module volume; foam inside the covers | 0.421 m3; 0.402 m3 (was 0.382 and 0.365 m3) |
| [G7] | Module bottom and top above the outside of the bottom | 420 and 620 mm (top 30 mm below the gunwale) |
| [G8], [G9] | Hull timber; dry hull mass at 750 kg/m3 | 0.586 m3; 439 kg |
| [K1] | Kit mass | 68.9 kg (battens and chocks 39.4 kg, foam 12.1 kg, covers 9.3 kg); was 67.4 kg |
| [K2], [K3] | Cover tarpaulin; strap webbing | 14.3 m2; 19.5 m |

## 3. Swamped, design load

*Table 3. Swamped canoe at the design load, fresh water.*

| Tag | Result | Value |
| --- | --- | --- |
| [L1] | Design net load | 118 kg |
| [F4] | Timber above the water, counted as load | 109 kg |
| [F1] | Freeboard amidships, level | 113 mm |
| [F3] | Trim | 0.39 deg stern down |
| [F2] | Lowest freeboard on the gunwale (transom) | 92 mm |
| [F5], [F6] | Metacentric height; roll stiffness | 3.1 m; 761 kg m per radian |
| [F7], [F8] | Net load carried at 50 mm freeboard; reserve | 290 kg; 2.45 times the design load |
| [F9] | No crew holding on | 128 mm lowest freeboard, 0 deg heel, 0.14 deg trim |

## 4. Off-design cases

*Table 4. Off-design cases.*

| Tag | Case | Result |
| --- | --- | --- |
| [F10], [F11] | All four crew holding the port grab line | 3.9 deg heel; low-side freeboard 44 mm (was 4.0 deg and 31 mm) |
| [F12] | Salt water | 98 mm lowest freeboard |
| [F13] | Foam lift down 5 % (the R6 limit) | 86 mm lowest freeboard |
| [F14], [F15] | Largest module (port 2) lost, and 5 % uptake | 25 mm lowest freeboard; 1.5 deg heel (was 9 mm) |
| [F16] | Typical 750 kg/m3 timber (lift not counted in the design) | 167 mm freeboard amidships |

With all four crew on one grab line the low-side gunwale is still under the 50 mm of R2, so the operating rule stays: crews spread along both grab lines. R13 itself asks only for heel within 10 deg and is met with a wide margin.

## 5. Why the modules are high: low placement compared

The TRL 1 concept placed the modules low along the sides. With the same 0.42 m3 of foam on the floor (85 to 285 mm up), the canoe floats with the top of the foam 1 mm under the water. The foam then cuts the waterline only by that knife edge: with four crew on one side it heels past the 10 degree limit, and 5 kg more load (one wet net, one more person's hand) puts the foam fully under water, where only the thin planks give any waterplane and the canoe has no roll stiffness left. (With the earlier 0.38 m3 of foam the floor arrangement was already in that state at the design load.)

*Table 5. Same foam, high or low.*

| Tag | Quantity | High under the gunwale | Low on the floor |
| --- | --- | --- | --- |
| [F6], [F17] | Roll stiffness, kg m per radian | 761 | 283, only while the foam top is at the water |
| [F5], [F18] | Metacentric height | 3.1 m | 0.68 m |
| [F10], [F19] | Four crew on one side | 3.9 deg heel | 10.6 deg heel, over the 10 deg limit |
| [F20] | Roll stiffness with 5 kg more load | 761 or more | None (foam fully under water) |

This is the result behind decision D1 in LVH-DDR-001. It matches the practice in the USCG level flotation method, where flotation that keeps a swamped boat upright sits high in the hull.

## 6. Space, bailing and the dry canoe

*Table 6. Space and bailing.*

| Tag | Quantity | Value |
| --- | --- | --- |
| [V1], [V2] | Inside volume below the gunwale; share taken by the modules | 5.01 m3; 8.4 % (was 7.6 %) |
| [B1] | Water inside the swamped canoe | 3.48 m3 |
| [B2] | Water that can stay aboard at 200 mm freeboard, all crew and gear aboard | 2.31 m3 |
| [B3], [B4] | Water to bail; time for two crew | 1.17 m3; about 5.9 minutes (estimate) |
| | Time to bail the canoe dry at the same rate | about 17 minutes (estimate) |
| [B5] | Dry canoe: added draft from the 69 kg kit | about 11 mm |

The clear width between the module tops is 923 mm (was 963 mm; the model checks at least 900 mm), and the modules take the upper side of the canoe, where little catch is stowed.

## 7. Fixings

The worst case for a fixing is a module pushed fully under water (a breaking wave or a canoe on its side), in salt water.

*Table 7. Fixing loads.*

| Tag | Quantity | Value | Factor (R7 needs 2) |
| --- | --- | --- | --- |
| [S1] | Largest module (1,400 mm), full lift | 0.601 kN | |
| [S2], [S3] | Per strap (two straps); each leg half of that | 0.301 kN | Webbing 66 |
| [S4] | D-ring pair, 4 kN to confirm | 0.301 kN | 13.3 |
| [S5], [S6] | Per coach screw, sideways (largest share, two screws) | 0.301 kN | 5.0 |
| [S7], [S8] | All modules fully under water; per frame | 4.11 kN; 0.205 kN | |

The frames take 0.205 kN each into their existing fastenings to the planks. The condition of those fastenings is checked on every hull before fitting (build plan, first checks).

## 8. Fitting time, cost and the sizing sheet

- [T1] Fitting on the canoe takes about 6.3 hours for a builder and a helper, with the foam cores and covers made beforehand (estimate): marking 40 minutes, battens 120, screws 60, chocks 40, straps and modules 50, eye bolts and grab lines 50, marks and bailers 20.
- [C1], [C2] Parts cost USD 682 for one kit and USD 1,360 for two canoes (one gauge). Value-engineering target: USD 1,000. Estimated cost of the constructable design: USD 1,360 (USD 360 over the target). [C3] Foam is 48 % of a kit. The wider modules still come four strips to a 1,000 mm sheet, so the six foam sheets are unchanged; the only added cost is 1 m2 more tarpaulin (USD 5 a kit).

The sizing sheet uses a simple prismatic estimate: modules 220 x 200 mm, top 30 mm below the gunwale, and enough run per side to carry 1.5 times the design net load plus the timber above the water at 50 mm freeboard.

*Table 8. Sizing sheet for other hulls (estimates; measure each hull).*

| Hull | Module run needed per side | Run free of thwarts |
| --- | --- | --- |
| 6.5 m paddle canoe, no motor, 3 crew | 2.5 m | 3.8 m |
| 8.0 m canoe, 15 hp, 4 crew (reference) | 3.8 m | 4.8 m fitted |
| 10 m canoe, 25 hp, 6 crew | 5.1 m | 6.4 m |

## 9. Results against the requirements

*Table 9. Results against LVH-REQ-001.*

| ID | Target | Result | Status |
| --- | --- | --- | --- |
| R1 | Afloat with design load | 2.45 times the design load carried at 50 mm freeboard | Met on paper |
| R2 | At least 50 mm freeboard | 92 mm lowest | Met on paper |
| R3 | Heel and trim within 10 deg | 0 deg heel, 0.39 deg trim | Met on paper |
| R4 | Bail in 15 min or less | About 6 minutes to 200 mm freeboard | Met on paper (estimate) |
| R5 | 10 % or less of inside volume | 8.4 % | Met |
| R6 | Under 5 % uptake | Under 1 % on supplier data | To confirm by test |
| R7 | Fixings 2 times their share | Lowest factor 5.0 (coach screw) | Met on paper |
| R8 | Fitted in a day | About 6.3 hours | Met on paper (estimate) |
| R9 | 12 months without loss | Not shown on paper | Needs field trial (TRL 4 and later) |
| R10 | Value-engineering target USD 1,000 for two canoes | USD 1,360 | Over the value-engineering target by USD 360 |
| R11 | Reserve 1.5 | 2.45 | Met on paper |
| R12 | Afloat with largest module lost | 25 mm freeboard (was 9 mm) | Met on paper |
| R13 | Heel within 10 deg, crew on one side | 3.9 deg; low side 44 mm (was 4.0 deg, 31 mm) | Met on paper |

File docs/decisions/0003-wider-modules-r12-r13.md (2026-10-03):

---
doc_id: LVH-DDR-003
title: LevelHull wider foam modules for R12 and R13
project: LevelHull
doc_type: Design decision record
version: "0.1"
status: Draft
date: '2026-10-03'
author: Amish Chadha
license: CERN-OHL-S-2.0
revisions:
- version: "0.1"
  date: '2026-10-03'
  author: Amish Chadha
  change: Decision 10A recorded and carried into the model, calculations, bill of materials, drawings and build plan
---

# 0003: Wider foam modules for R12 and R13

- **Date:** 2026-10-03
- **Status:** decided. Decided by Amish on 2026-10-03, choosing option A on every requirement decision put to him: "1A 2A 3A 4A 5A 6A 7A 8A 9A 10A 11A". This record carries decision 10A.

## Context

At TRL 3 (LVH-CAL-001 v0.1) R12 and R13 were met on paper, but with little margin. With the largest module lost and 5 % water uptake the lowest point of the gunwale was only 9 mm above the water (R12). With all four crew holding one grab line the heel was 4.0 deg, inside the 10 deg of R13, but the low-side gunwale was only 31 mm above the water. Both had been handled as operating rules rather than by the design.

## Options considered

- **A. Enlarge the foam modules about 10 % (chosen).** More lift and more waterplane along both sides for a small rise in foam, cover and mass.
- **B.** Keep the modules and keep the operating rules (crews spread out, no fishing with a module missing).

## Decision

Option A. The modules are widened from 200 to 220 mm (level width), keeping the 200 mm height of four 50 mm layers, the lengths, the positions high under the gunwale and every fixing. That is 10 % more foam: 0.42 m3 of module in all, against 0.38 m3.

Width rather than height or length was chosen because:

- A fifth layer would add 25 %, not 10 %, and would bring the module bottom down towards the floor, where it adds less roll stiffness.
- The lengths are already set by the thwarts and frames.
- Four 220 mm strips still come from the 1,000 mm width of one foam sheet, so the six sheets per kit stay the same. A new model check confirms it.
- The battens, chocks and screws are unchanged. Each strap goes 40 mm further round the module, so straps are cut 1.25 m long instead of 1.2 m (20 m of the 25 m bought), and each cover panel is cut 1,040 mm wide instead of 1,000 mm.

## Results (LVH-CAL-001 v0.2)

| Requirement | Target | Before | After |
| --- | --- | --- | --- |
| R12 | Still floats with the largest module lost and 5 % uptake | 9 mm lowest freeboard, 1.5 deg heel | 25 mm lowest freeboard, 1.5 deg heel |
| R13 | Heel within 10 deg, all four crew on one grab line | 4.0 deg; low side 31 mm | 3.9 deg; low side 44 mm |
| R1, R11 | Afloat with design load; reserve at least 1.5 | 2.17 | 2.45 |
| R2 | At least 50 mm freeboard | 80 mm | 92 mm |
| R5 | 10 % or less of the inside volume | 7.6 % | 8.4 % |
| R7 | Fixings at least 2 times their share | Lowest 5.5 | Lowest 5.0 |
| R10 | Value-engineering target USD 1,000 for two canoes | USD 1,350 | USD 1,360 |

Kit mass rises from 67.4 to 68.9 kg (foam 12.1 kg, covers 9.3 kg). The clear width between the module tops falls from 963 to 923 mm, still above the 900 mm the model checks. The model passes 127 of 127 constructability checks.

## Consequences

- Value-engineering target: USD 1,000. Estimated cost of the constructable design: USD 1,360 (USD 360 over the target). The only added cost is 1 m2 more tarpaulin a kit (USD 5); the foam strips come from the same six sheets, so no spare strip is left.
- With all four crew on one side the low gunwale is still under 50 mm from the water, so the operating rule that crews spread along both grab lines stays.
- The comparison with the same foam on the floor changes: the larger volume now just reaches the surface on the floor, but it heels 10.6 deg with the crew on one side and has no roll stiffness left with 5 kg more load. The case for fitting the modules high (LVH-DDR-001, D1) stands.
- The cores, covers, general arrangement (Rev P3), making sketches of the cores and covers, the module joint pictures, the step pictures and the concept media are redrawn from the model.

> **Safety:** Wider modules give more margin when the canoe is swamped; they do not make it safe. LevelHull is never a substitute for life jackets, and the swamp test rules in the build plan are unchanged.

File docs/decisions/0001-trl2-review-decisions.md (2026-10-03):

---
doc_id: LVH-DDR-001
title: LevelHull TRL 2 review decisions
project: LevelHull
doc_type: Design decision record
version: "0.1"
status: Draft
date: '2026-10-03'
author: Amish Chadha
license: CERN-OHL-S-2.0
revisions:
- version: "0.1"
  date: '2026-10-03'
  author: Amish Chadha
  change: TRL 2 review items decided under Amish's 2026-10-03 pre-approval
---

# 0001: TRL 2 review decisions

- **Date:** 2026-10-03
- **Status:** decided. Decided by Amish under his pre-approval of 2026-10-03: "start with the first 14 repos from the list of 29 projects. I pre-approve the batch runs along with any recommendations you come up with. I also accept any cost overruns or variations from the assumed scope cost."

## Context

The scaffold (LVH-PRB-001, LVH-PRC-001 and LVH-REQ-001, all v0.1) described foam blocks or sealed chambers "strapped and fixed low along both inside faces" of a wooden canoe, sized by a sheet from the hull and motor. It left five open questions: whether low placement gives enough roll stability when swamped, foam or chambers, how much lift the wood gives and what the motor changes, a re-entry step, and promotion without implying that life jackets are optional. Populating the concept to TRL 2 meant settling these. Amish pre-approved every recommendation in this batch, so each item below is decided, not proposed. Items that touch safety take the conservative option and say what evidence would relax it. Partners are the first candidates to approach, not agreements.

## Options considered

*Table 1. Options.*

| # | Item | Options |
| --- | --- | --- |
| D1 | Where the modules go | (a) low along the sides or on the floor; (b) high under the gunwale, cutting the swamped waterline; (c) split between the two |
| D2 | Buoyancy material | (a) closed-cell polyethylene foam in covers; (b) sealed rigid chambers (drums, jerrycans, welded HDPE); (c) polystyrene or polyurethane foam |
| D3 | Lift from the wooden hull | (a) count a typical timber density; (b) count none (wet timber as dense as water) |
| D4 | Design case | (a) a generic sheet only; (b) one reference canoe checked in full, with a calculator for other hulls |
| D5 | Crew load | (a) crew aboard the swamped canoe; (b) crew in the water holding on, 20 % of body weight each |
| D6 | Re-entry step | (a) add one; (b) keep it parked |
| D7 | Something for the crew to hold | (a) the gunwale only; (b) grab lines along both sides |
| D8 | Life jacket message | (a) in the documents only; (b) in every document, the fitting guide and the swamp test rules |
| D9 | Co-design partner | Beach management units, fisheries research institutes, sea-safety programmes, canoe builders' groups |
| D10 | Requirements | Keep R1 to R10 and add reserve, damage tolerance and crew-on-one-side requirements |

## Decision

- **D1 (b).** Modules high under the gunwale. In LVH-CAL-001 the same foam on the floor gives 17 kg m per radian of roll stiffness against 742, and the canoe rolls over with the crew on one side. This is the conservative choice; it would be reconsidered only if a swamp test showed a low arrangement stable with the motor and crew on one side.
- **D2 (a).** Closed-cell polyethylene foam, about 30 kg/m3, in sewn PVC tarpaulin covers. A puncture loses no lift and nothing needs sealing. Polystyrene is excluded because fuel dissolves it, and open-cell or poured polyurethane because it soaks up water. Sealed chambers would be reconsidered only after pressure, drop and 12-month ageing tests show they hold air when knocked and sun-baked; they stay with the sibling LaneSkiff concept.
- **D3 (b).** No lift counted from the hull: wet timber is taken as exactly as dense as water. Conservative; it would be relaxed for a given canoe only by weighing the hull and measuring its timber volume, or by a float test of the bare hull.
- **D4 (b).** The reference canoe is 8.0 m long, 1.6 m in beam and 0.65 m deep, flared 31.6 deg, with a 15 hp outboard and four crew. `docs/04-calcs/sizing.py` is the open calculator for other hulls.
- **D5 (b).** Crew in the water holding on, 15 kg each at the gunwale. Bailing is checked with all crew back aboard.
- **D6 (b).** The re-entry step stays parked (scope unchanged since 2026-09-30).
- **D7 (b).** Grab lines of 12 mm polyester rope along both sides, on four through-bolted eye bolts a side above every waterline.
- **D8 (b).** "Never a substitute for life jackets" in every document and the fitting guide; the swamp test is run with every person in a life jacket and a safety boat standing by.
- **D9.** First candidates to approach, in order (none approached yet): a beach management unit on the Kenyan shore of Lake Victoria with the canoe builders at its landing site; a national fisheries research institute in the region for hull and load surveys; a sea-safety programme that trains fishers in life jacket use.
- **D10.** R1 to R10 kept with fixed targets on the reference canoe; R11 (reserve 1.5 times at 50 mm freeboard), R12 (afloat with the largest module lost and 5 % uptake) and R13 (heel within 10 deg with all crew on one side) added.
- **Unchanged:** the pitch, the problem, the passive no-inflation design-around, the open sizing method, and `budget_usd` (USD 1,000), now read as a value-engineering target.

## Consequences

- The modules take the upper sides of the canoe rather than the floor; they cover 7.6 % of the inside volume and leave 963 mm clear between their tops.
- The modules need a fixing that carries their lift into the frames: shelf battens, coach screws and straps (LVH-DDR-002).
- Kits for two canoes are estimated at USD 1,350, USD 350 over the value-engineering target; Amish's pre-approval accepts the overrun.
- The hull's own lift is an unclaimed margin (about 58 mm more freeboard with typical 750 kg/m3 timber).

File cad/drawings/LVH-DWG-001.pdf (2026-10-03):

CONCEPT, NOT FOR FABRICATION | LevelHull · github.com/BoujeeEnjinia1701/levelhull

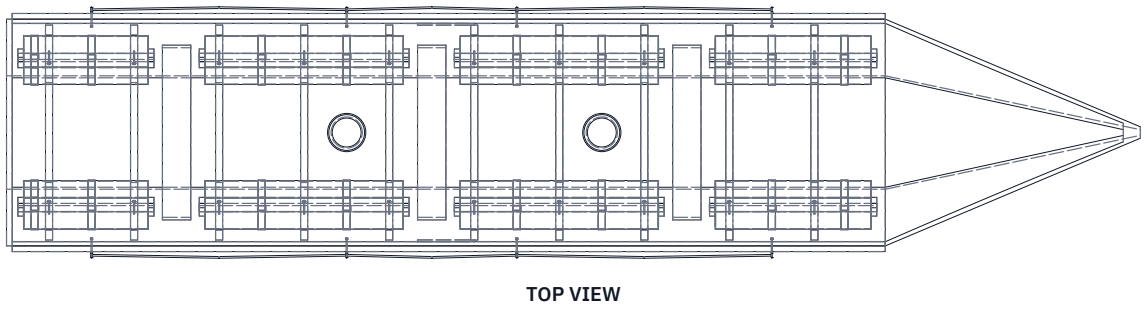
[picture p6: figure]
TOP VIEW

FRONT VIEW
Scale 1:50; looking at the front (along +Y)

Scale 1:50; looking down (along -Z)

RIGHT VIEW
Scale 1:50; looking at the right side (along -X)

8000

1774 760

200

SECTION A-A
Scale 1:20; looking aft (along -X), 2.4 m from the transom (frame at 2.1 m behind)

FOAM CORE (5) IN COVER (6)

SHELF BATTEN (2), M8 SCREW (3)

STRAP (8), D-RINGS (9)

EYE BOLT (10), GRAB LINE (11)

FRAME (OWNER'S CANOE)

MAIN SIZES AND FIGURES (MM UNLESS STATED)
Reference canoe 8,000 long, beam 1,600, depth 650, flare 31.6 deg 8 modules, 4 a side: 880, 1,400, 1,400, 1,100 long
Module 220 wide x 200 high, top 30 below gunwale
Module = four 50 PE foam layers in a tarpaulin sleeve (5, 6)
Battens 50 thick, 70 high, 40 past each module end
20 coach screws M8 x 100, one into every frame crossed 16 straps, 50 webbing, in the bays between frames
Chocks 40 long, 50 high, at both ends of every module
Eye bolts at 600, 2,400, 3,600, 5,400 from transom Freeboard mark: top edge 50 below the gunwale, amidships Swamped, design load: 113 freeboard amidships, 92 lowest Third-angle; X from transom, Y to port; (n) = BOM line
REV | DESCRIPTION | DATE | BY
P1 | Preliminary GA for TRL 3 (from cad/src/model.py) | 2026-10-03 | AC
P2 | LVH-DDR-002: design for construction | 2026-10-03 | AC
P3 | LVH-DDR-003: modules widened to 220 | 2026-10-03 | AC
LEVELHULL | github.com/BoujeeEnjinia1701/levelhull

## Flotation retrofit in the reference canoe: general arrangement

DRAWING NO.
LVH-DWG-001

REV
P3

SHEET
1 of 1

SIZE

## ANSI B

SCALE
1:50

UNITS
mm
PROJECTION | DATE
2026-10-03

DRAWN
Amish Chadha

MATERIAL / NOTES
Kit per bom/bom.csv; canoe is the owner's boat (reference shown). PRELIMINARY, NOT FOR FABRICATION
Licensed CERN-OHL-S-2.0 · Design Molecule Lab · designmolecule.com | Generated from cad/src; do not edit by hand

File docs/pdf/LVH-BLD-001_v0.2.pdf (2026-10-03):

L E V E L H U L L · B U I L D P L A N

# LevelHull prototype build plan

Design Molecule Lab · designmolecule.com

D O C U M E N T CO N T RO L

Document ID | LVH-BLD-001 | Version | 0.2
Status | Draft | Date | 2026-10-03
Author | Amish Chadha | License | CERN-OHL-S-2.0
Project TRL | TRL 3 | Proof of concept
Repository | github.com/BoujeeEnjinia1701/levelhull
Source | docs/05-build-plan.md @ uncommitted

R EV I S I O N H I STO RY

Version | Date | Author | Change
0.2 | 2026-10-03 | Amish Chadha | Modules widened from 200 to 220 mm (LVH-DDR-003); foam strips, covers, straps and pictures updated
0.1 | 2026-10-03 | Amish Chadha | First build plan; design made constructable (LVH-DDR-002)

D R A F T · N O T F O R F A B R I C A T I O N

## LevelHull prototype build plan

Plan, not yet built. How to make the flotation kit and fit it to the first canoe, component by component. Building and testing to it is TRL 4 work. Decisions are kept in the design decisions register ( docs/06-design-decisions.md ), not here.

Safety: LevelHull is flotation for the boat. It is never a substitute for life jackets, and it is not certified lifesaving equipment. The fitted canoe is not used for fishing until it has passed the fixing pull test and a swamp test in sheltered, shallow water with a safety boat and every person in a life jacket (sections 5 and 6). Work with power tools and solvents needs eye protection and air.

### 1. What you are building

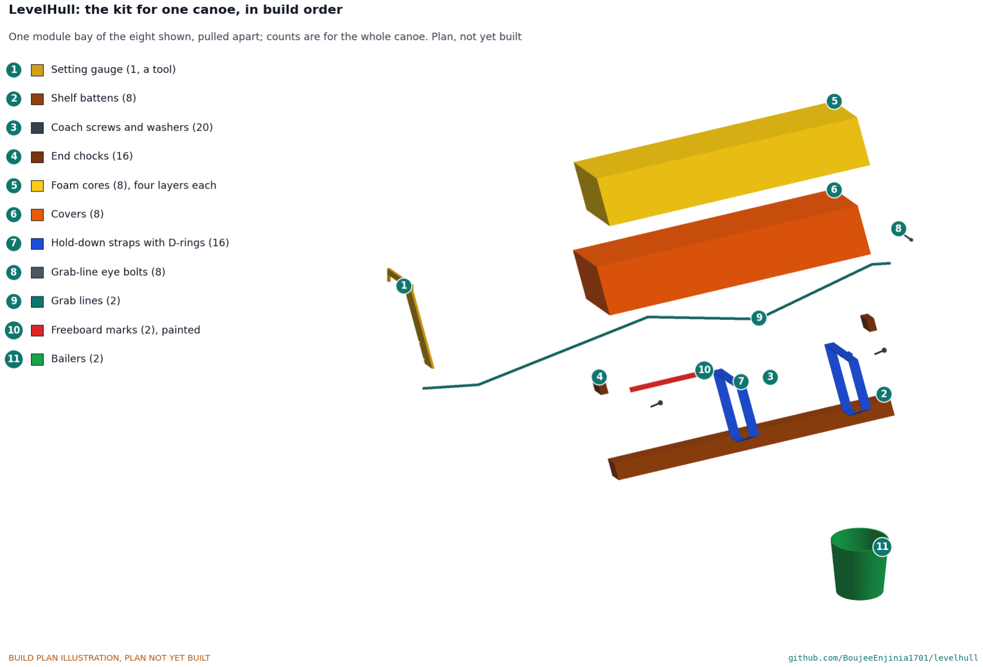
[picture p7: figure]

Figure 1. The kit for one canoe, in build order. One of the eight module bays is shown; the counts are for the whole canoe.
The kit turns an ordinary planked fishing canoe into one that floats upright when it fills with water. It has eight buoyancy modules, four along each side, high under the gunwale between the thwarts. Each module is four layers of closed-cell foam in a sewn tarpaulin sleeve, sitting on a hardwood shelf batten that is screwed into the canoe's frames, held down by two webbing straps and kept from sliding by a wooden chock at each end. Grab lines along both sides, two bailers and a painted freeboard mark on each side complete it. Five parts are made (a plywood setting gauge, the battens, the chocks, the foam cores and the covers); the rest are bought. Parts cost about USD 682 per canoe. The sizes are for the reference canoe, 8.0 m long, 1.6 m in beam and 0.65 m deep with a 15 hp outboard; measure each canoe and size it with the calculator first.

### 2. What changed to make it buildable

Table 1. Changes from the concept.

Component | The concept had | The buildable design has | Why
Modules | Blocks low along the sides | High under the gunwale, top 30 mm below it, lying on the frame faces | Upright when swamped
Module shape | Rectangular blocks, one per side | Four per side between the thwarts, each a stack of four equal foam strips cut to the side slope, 220 mm wide and 200 mm high | Sits flat on the sloping frames; light to handle
Seat | "Cleats" | A hardwood shelf batten under each module | Gives the straps an anchor and spreads the lift over the frames
Fixings | Not specified | One coach screw into every frame a batten crosses, stopping short of the planks | No new holes in the planks below the waterline
End stops | None | A chock at each end of each module | Stops the module creeping fore and aft
Straps | "Fixing straps" | Closed webbing loops round module and batten, in the bays between frames, with D-ring buckles | No separate anchor; nothing to corrode or jam
Covers | "Protective covers" | Sewn tarpaulin sleeves with laced ends | Made and replaced by a tailor; foam can be checked
Fitting | Measured by hand | A plywood setting gauge for the batten height | Same height on every frame
Hand holds | None | Grab lines on four eye bolts a side | Something for the crew to hold in the water


Figure 2. Cut across the canoe through module 2: the modules lie high on the frame faces.

### 3. Making the components

Make the foam cores and covers in the workshop before the canoe comes in, so the fitting takes one day.

### 3.1 Setting gauge

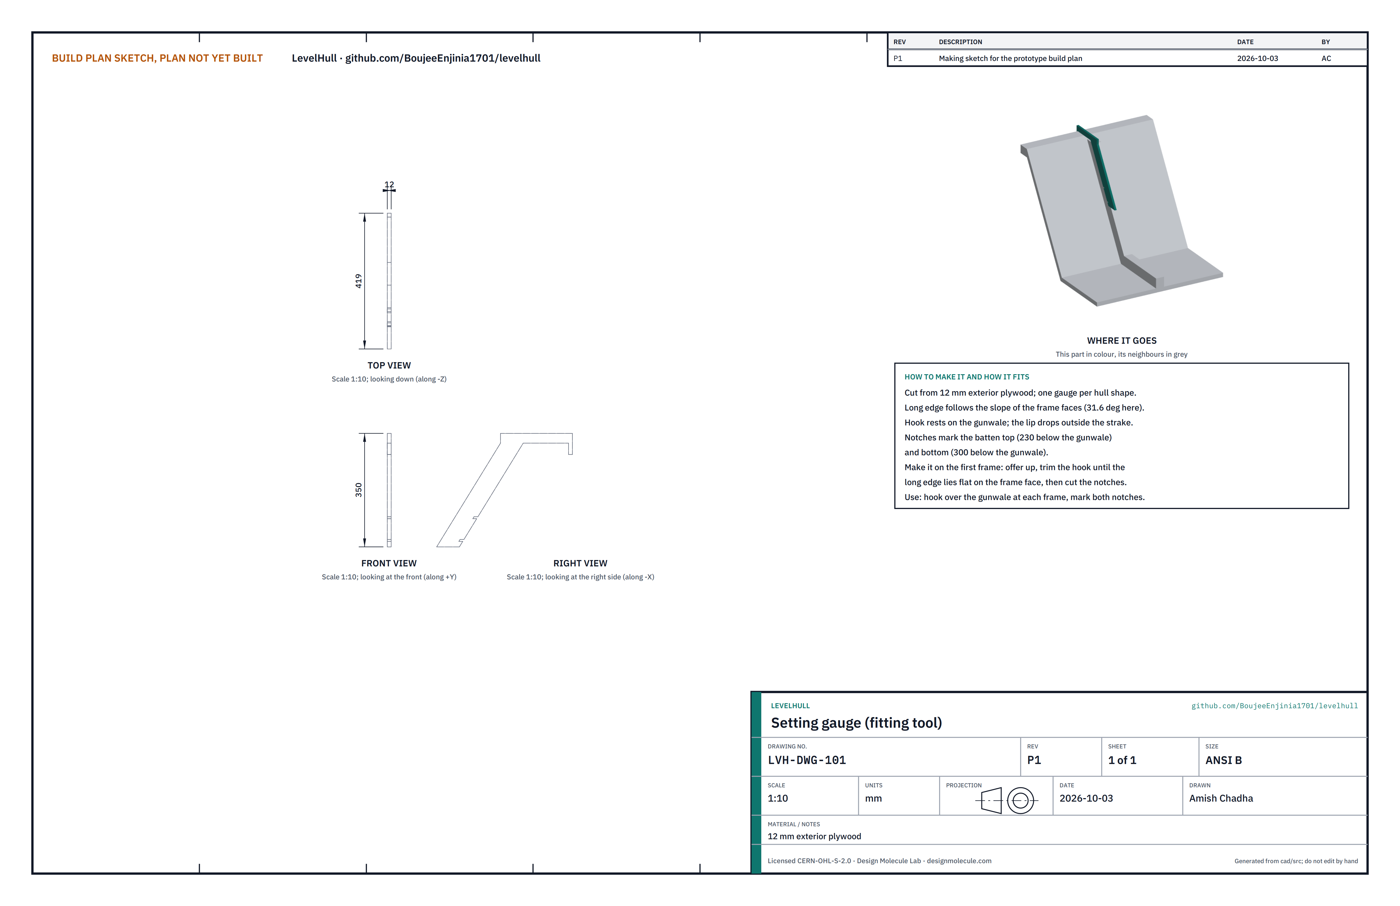
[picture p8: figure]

What it is and what it is made from. A fitting tool: a strip of 12 mm exterior plywood about 450 mm long and 70 mm wide with a hook at the top. Hooked over the gunwale at a frame, it lies flat on the frame's inner face and its two notches show where the top and bottom of the shelf batten go. One gauge serves every canoe of the same shape. How to make it.
Cut a plywood blank about 360 x 450 mm.
Mark the long edge at the slope of the canoe's side, measured on the first frame with a bevel gauge (31.6 deg from upright on the reference canoe).
Cut the strip 70 mm wide along that edge, with the hook at the top: a 30 mm thick bar across the gunwale and a 35 mm lip that drops outside the rubbing strake.
Offer it up at the first frame. Trim the underside of the hook until the long edge lies flat on the frame face from the gunwale down.
Cut two saw notches, 12 mm deep, on the long edge: the top of the batten 230 mm below the top of the gunwale, and the bottom 300 mm below it, measured straight down.

How it fits the parts next to it.

1.
2.

3.

4.

5.

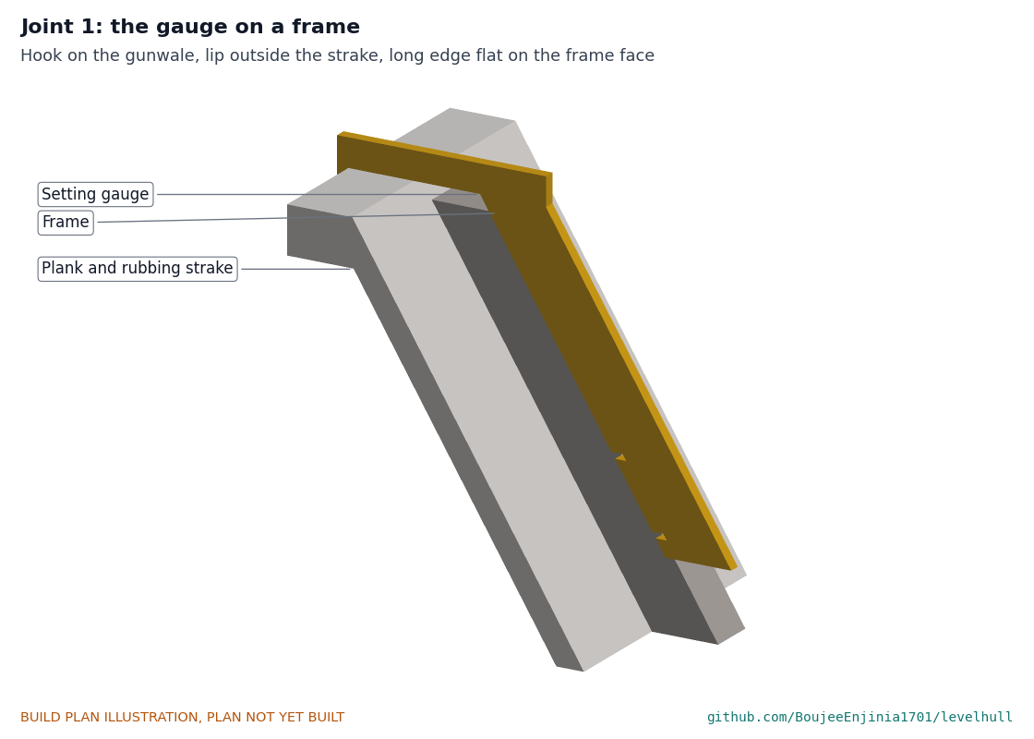
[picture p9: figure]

Figure 3. The gauge hooked over the gunwale, its long edge on the frame face.
The hook rests on the top of the planking and rubbing strake; the lip touches the outside of the strake; the long edge lies on the frame face.
Check before moving on. On three frames along the canoe, the gauge sits flat with no rocking and the hook seats fully.

### 3.2 Shelf battens

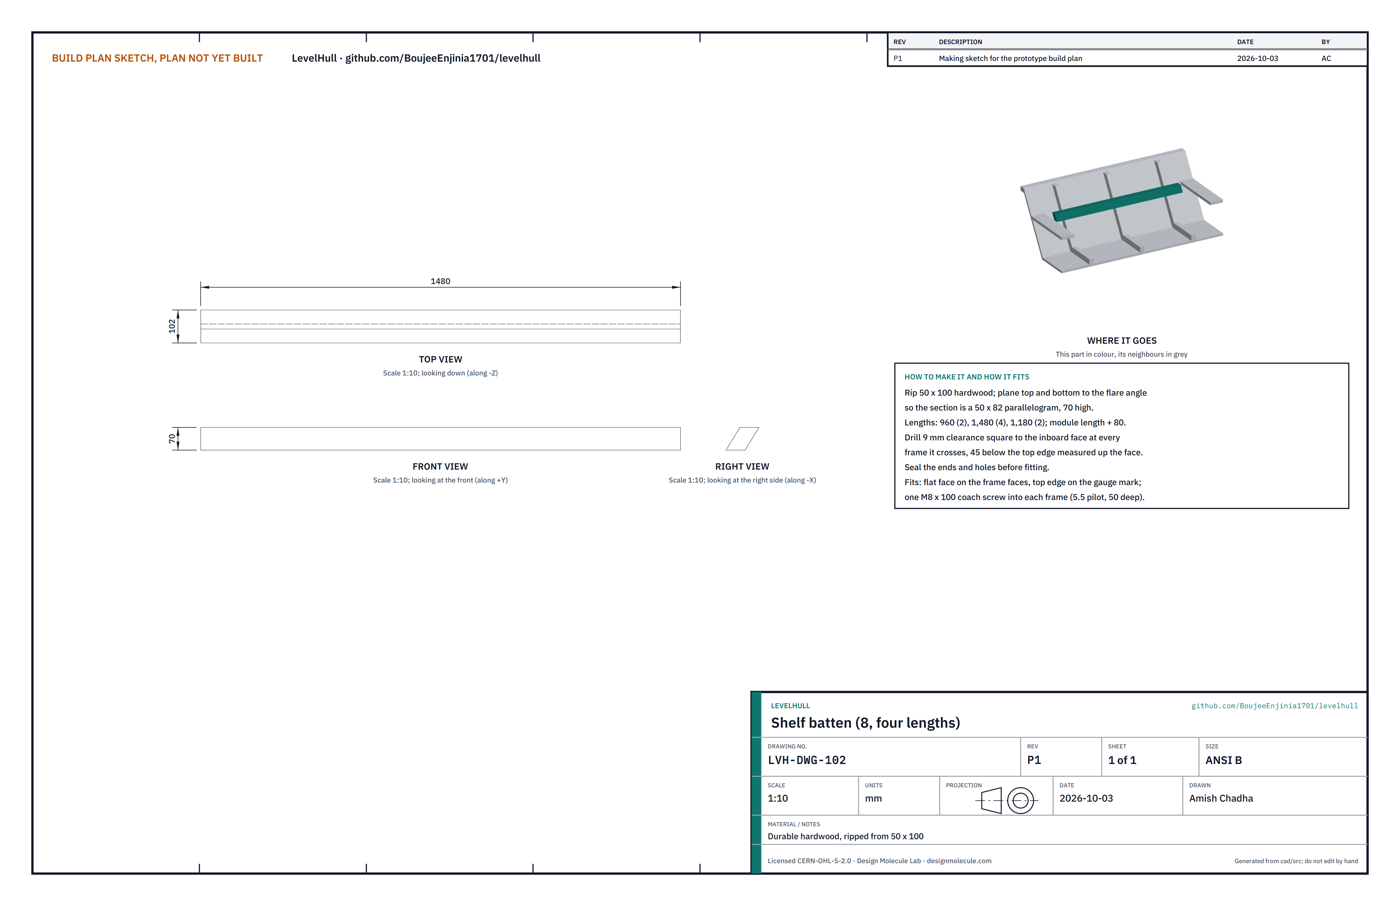
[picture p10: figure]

What it is and what it is made from. Eight hardwood rails, one under each module, from 50 x 100 mm durable hardwood. Each is 50 mm thick square to the frame faces and 70 mm high, with the top and bottom cut level, so its section is a 50 x 82 mm parallelogram. Lengths: two of 960 mm, four of 1,480 mm and two of 1,180 mm (each module length plus 80 mm).
How to make it.
Rip the stock to about 85 mm.
Plane the top and bottom edges to the side slope (31.6 deg from square on the reference canoe) so both are level when the wide face lies on the frames; finished height 70 mm.
Cut to length.
Lay the batten against the canoe at its marks and mark the centre of every frame it crosses on its inboard face, 45 mm below the top edge measured up the face.
Drill 9 mm clearance holes there, square to the face.
Seal the ends and holes; cut the chocks for the same module from the offcut (section 3.3).

How it fits the parts next to it.

1.
2.

3.
4.

5.
6.

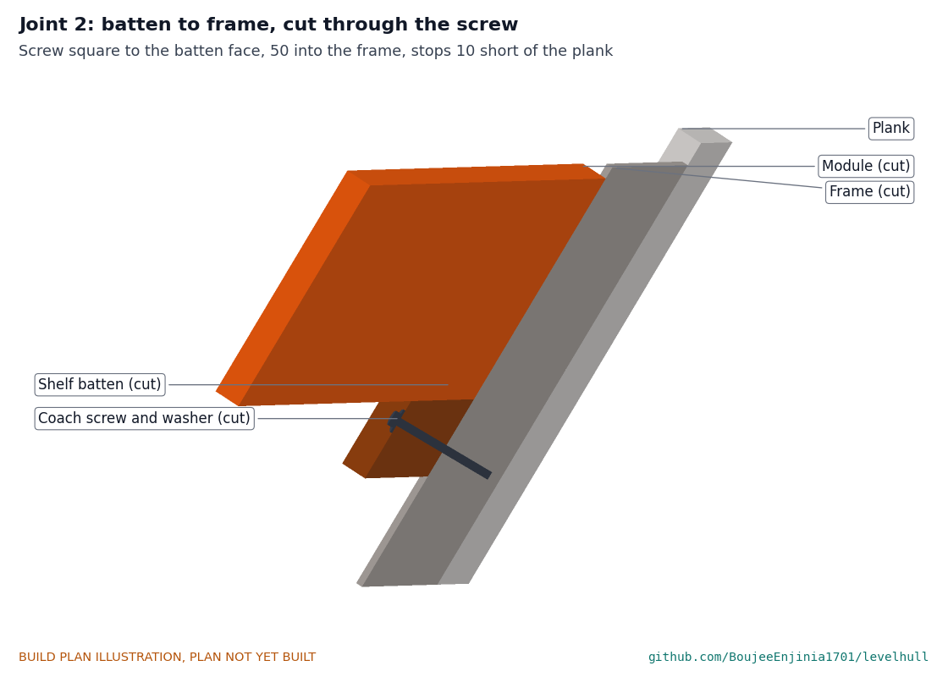
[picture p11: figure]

Figure 4. Batten on a frame, cut through the coach screw. The screw goes 50 mm into the frame and stops 10 mm short of the plank.
The wide face lies on the frame faces; the top edge is on the upper gauge mark. One M8 x 100 coach screw with a 24 mm washer goes through each hole into the frame, in a 5.5 mm pilot hole 50 mm deep. The module sits on the top edge.
Check before moving on. Each batten touches every frame it crosses; a straightedge laid on the tops of the two battens of one module bay shows them level with each other across the canoe.

### 3.3 End chocks

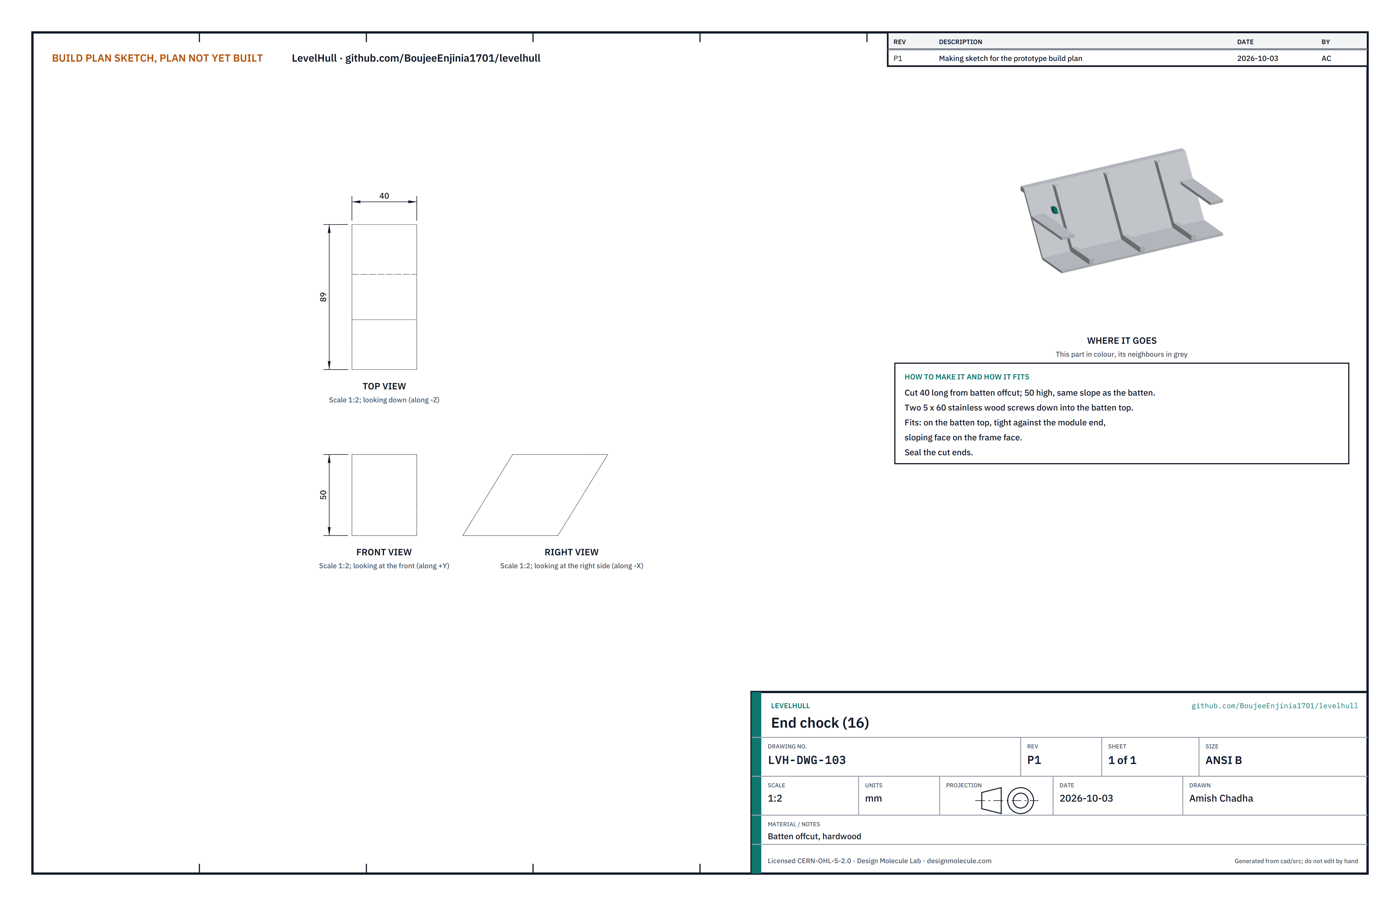
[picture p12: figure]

What it is and what it is made from. Sixteen hardwood blocks from batten offcut, 40 mm long, 50 mm high and the batten's width, with the same sloping outboard face.
How to make it.
Cut the offcut to 40 mm lengths.
Trim each to 50 mm high, keeping the sloping face.
Drill two 4 mm pilot holes down through each and seal the cut ends.

How it fits the parts next to it.

1.
2.
3.

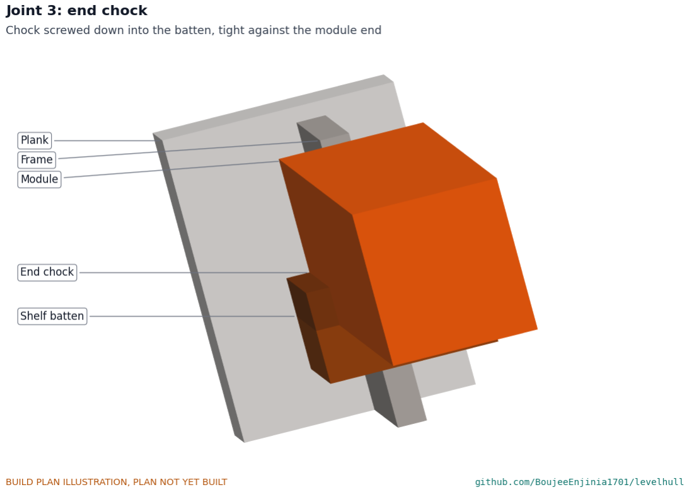
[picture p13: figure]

Figure 5. An end chock on the batten, against the end of the module.
The chock sits on the batten top at the end of the module, sloping face against the frame line, screwed down with two 5 x 60 mm stainless screws. The gap between the two chocks of a batten is the module length plus 5 mm. Check before moving on. The chock does not move when pushed by hand.

### 3.4 Foam cores

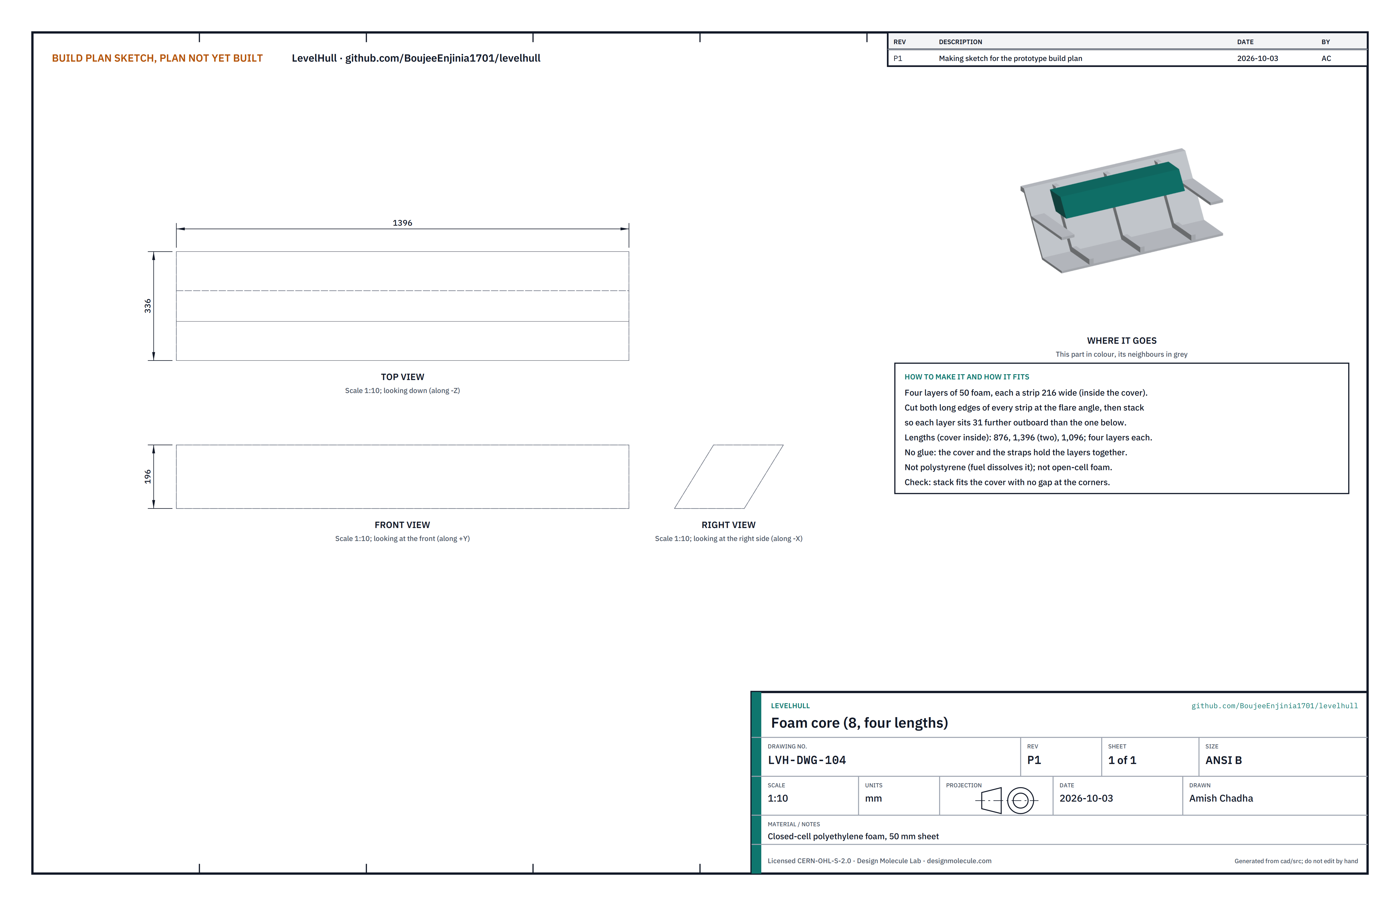
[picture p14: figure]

What it is and what it is made from. Eight stacks of four layers of 50 mm closed-cell polyethylene foam (about 30 kg/m3), cut from 2,000 x 1,000 mm sheets. Not polystyrene, which fuel dissolves, and not open-cell foam, which soaks up water.
How to make it.
Cut the sheets into strips 216 mm wide (measured level), with both long edges cut at the side slope, using a long knife or hot wire against a straightedge; four strips come from each sheet, which uses all 24 strips from the six sheets. Keep the narrow strip left at the edge of each sheet for the water uptake samples.
Cut the strips to length: 876 mm (8 strips), 1,396 mm (16) and 1,096 mm (8).
Stack four strips of the same length, each set 31 mm further outboard than the one below, so the stack's faces are flat parallelograms. No glue.

How it fits the parts next to it. The stack slides into its cover (section 3.5), sloping side to the frames.
Check before moving on. A stack fits its cover with no gap at the corners, and each strip has no cracks or tears.

1.

2.
3.

### 3.5 Covers

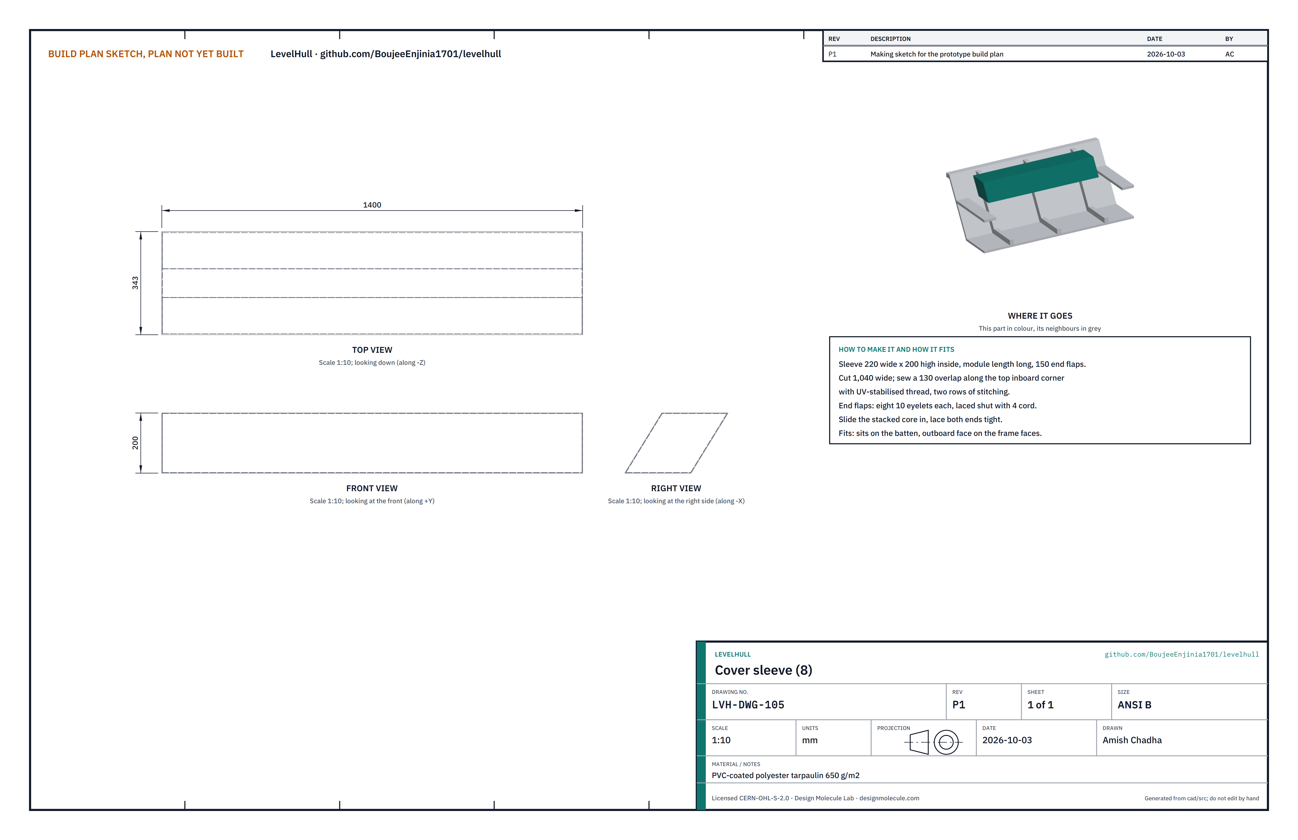
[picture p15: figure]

What it is and what it is made from. Eight sleeves of PVC-coated polyester tarpaulin, 650 g/m2, UV stabilised, sewn with UV-stabilised polyester thread. Inside size 220 mm wide by 200 mm high by the module length (880, 1,400 or 1,100 mm), with 150 mm flaps at each end.
How to make it.
Cut a panel 1,040 mm wide by the module length plus 300 mm.
Fold it round a stacked core and sew a 130 mm overlap along the top inboard corner with two rows of stitching. Set eight 10 mm eyelets in each end flap.
Slide the core in, fold the flaps and lace them shut with 4 mm cord.

How it fits the parts next to it. The covered module sits on its batten between the chocks, its sloping face on the frame faces; the straps go round it (section 3.6).
Check before moving on. The laced ends are tight and the stitching has no gaps.

1.
2.
3.
4.

### 3.6 Hold-down straps with D-rings

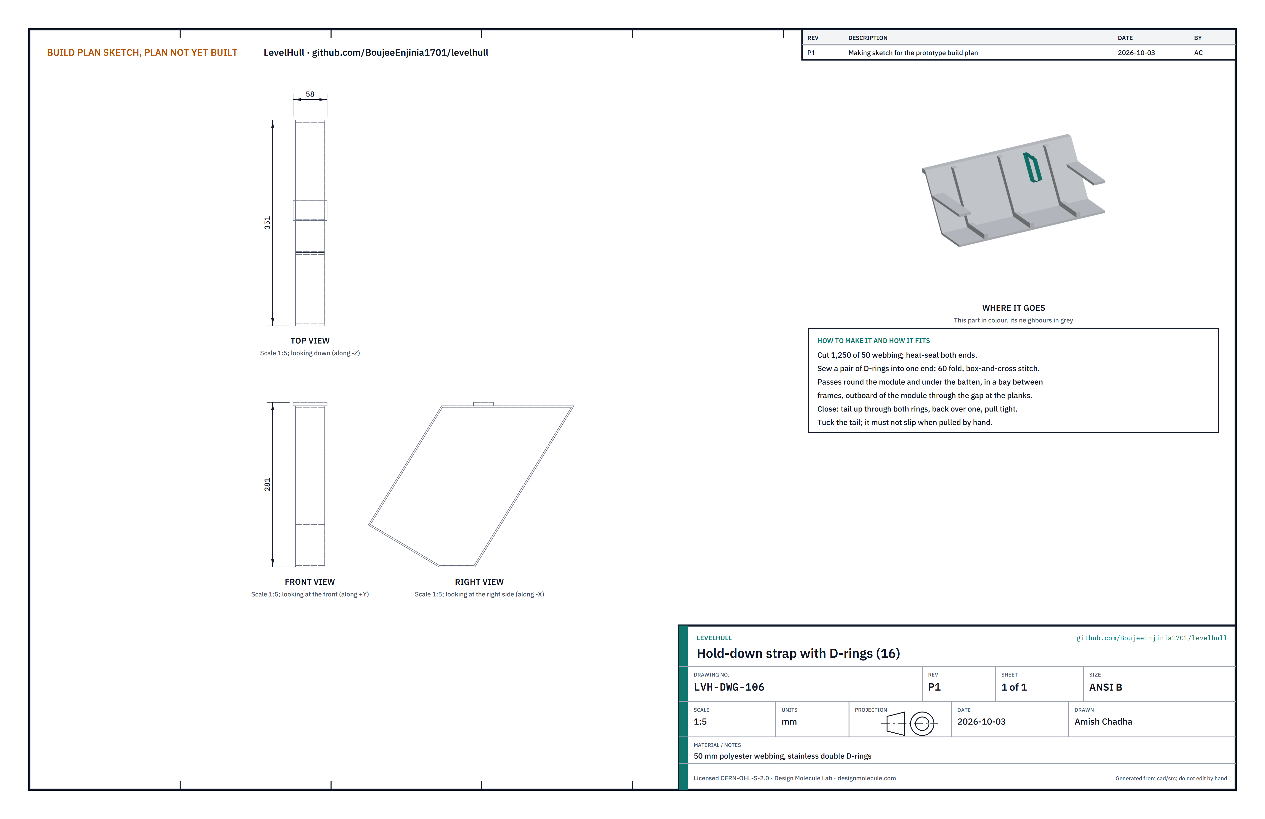
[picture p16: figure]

What it is and what it is made from. Sixteen loops of 50 mm UV-stabilised polyester webbing, about 1.25 m long, each with a pair of stainless double D-rings sewn into one end.
How to make it.
Cut 1.25 m of webbing; heat-seal both ends.
Fold 60 mm of one end round both D-rings and sew it with a box-and-cross stitch.

How it fits the parts next to it.

1.
2.

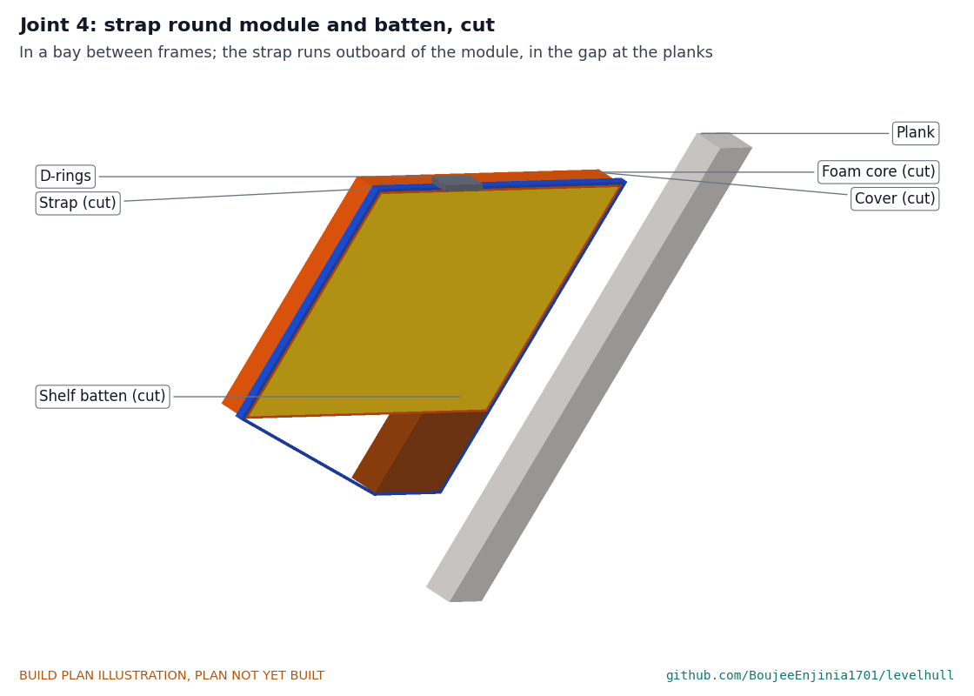
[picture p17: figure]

Figure 6. A strap round module and batten, cut through the strap. It runs outboard of the module in the gap between the frames.

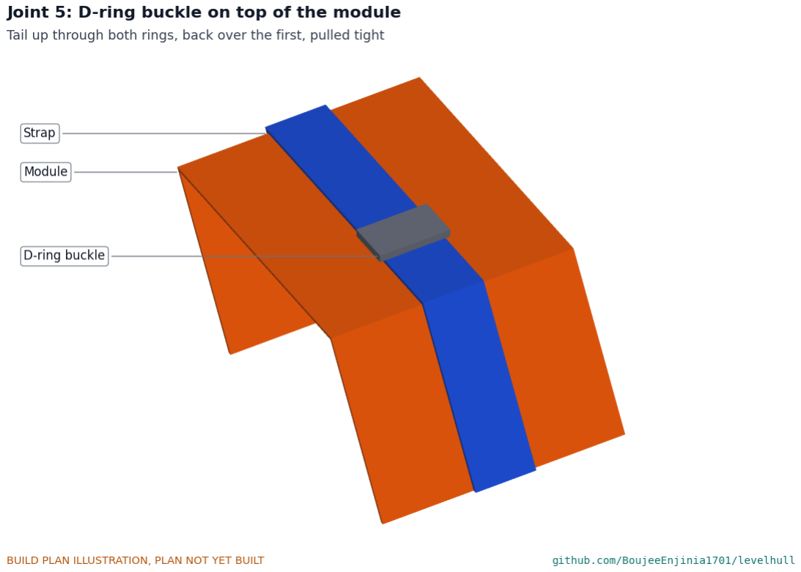
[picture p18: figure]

Figure 7. The D-ring buckle on top of the module.
Each strap goes in a bay between two frames, under the batten, up between the module and the planks, over the top of the module and down its inboard face. The tail goes up through both rings, back over the first and is pulled tight.
Check before moving on. Pulled hard by hand, the buckle does not slip.

### 3.7 Coach screws (bought)

Twenty-four M8 x 100 mm hex coach screws with 24 mm washers, stainless A4 or hot-dip galvanised (20 fitted, 4 spare). Bed each in sealer.

### 3.8 Grab-line eye bolts and grab lines (bought)

Eight M8 x 100 mm stainless eye bolts with 30 mm eyes, washers and nyloc nuts; 14 m of 12 mm polyester three-strand rope.

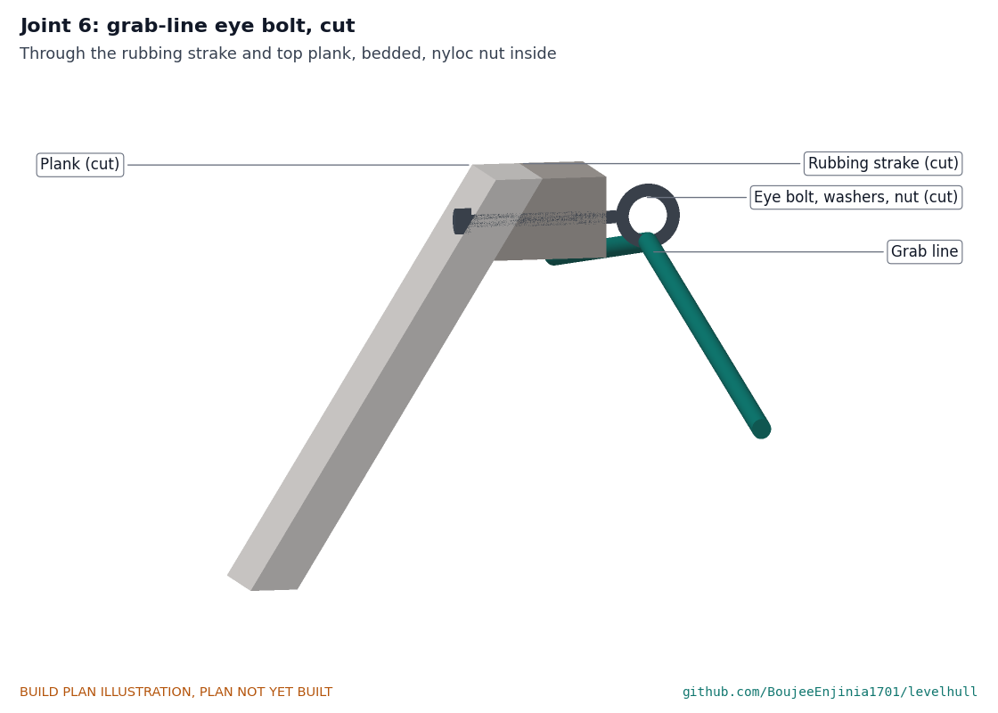
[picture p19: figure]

Figure 8. An eye bolt through the rubbing strake and top plank, nut inside.
Drill 8 mm through the rubbing strake and top plank, 25 mm below the gunwale top, between frames, at 0.6, 2.4, 3.6 and 5.4 m from the transom on each side. Bed the bolt in sealer and tighten the nut inside against a washer.

### 3.9 Bailers and swamp test kit (bought)

Two 10 L plastic buckets with 1.5 m lanyards of 6 mm rope; orange marine enamel, masking tape and a bubble inclinometer reading to 1 deg; sealer for the battens, chocks and holes.

### 4. Putting it together

Steps 1 to 7 show module 2 on the port side; repeat them for all eight bays. Start with the canoe dry, empty and level on the beach, supported under the keel line.

Step 1: mark the batten heights with the gauge

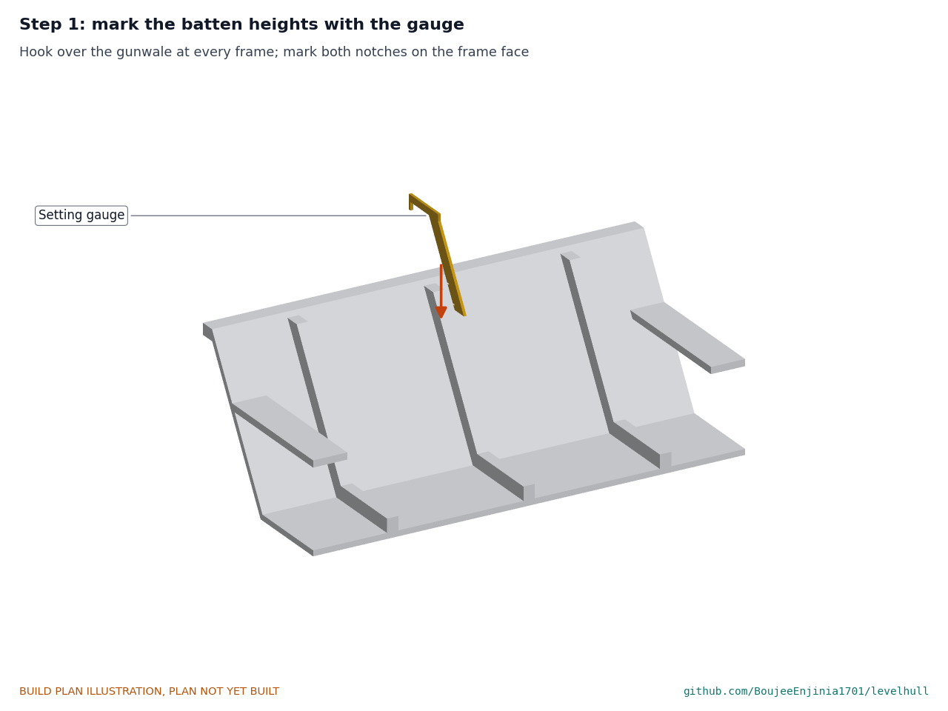
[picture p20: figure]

Hook the gauge over the gunwale at every frame the battens will cross and mark both notches on the frame face. Check that the thwarts and frames are sound before going on.

Step 2: hold each batten to its marks

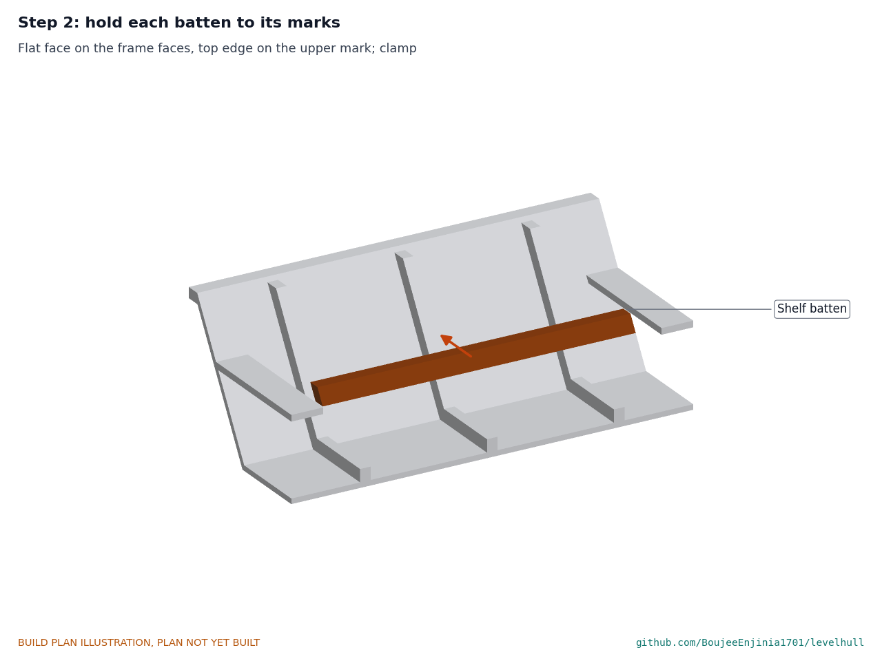
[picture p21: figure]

Lay the batten's wide face on the frame faces with its top edge on the upper marks, and clamp it.

Step 3: drill and drive the coach screws

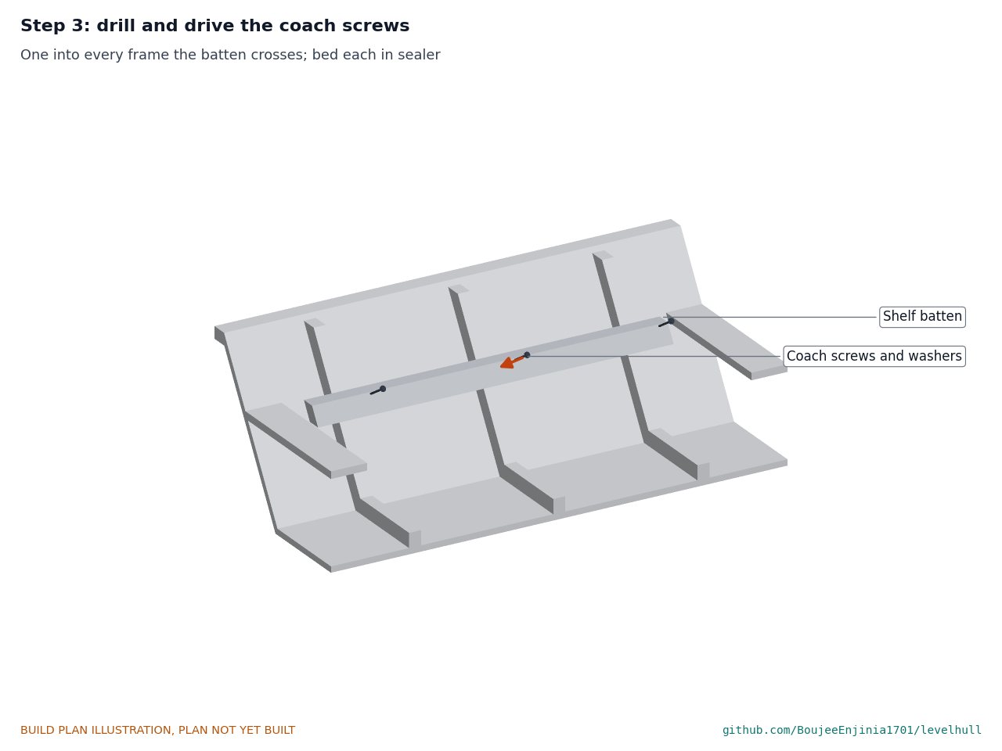
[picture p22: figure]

Through each clearance hole, drill a 5.5 mm pilot 50 mm deep into the frame, square to the batten face. Put a tape flag on the drill bit at the depth so it cannot reach the plank. Drive the screws with their washers, bedded in sealer, until snug.

Step 4: screw the end chocks to the batten

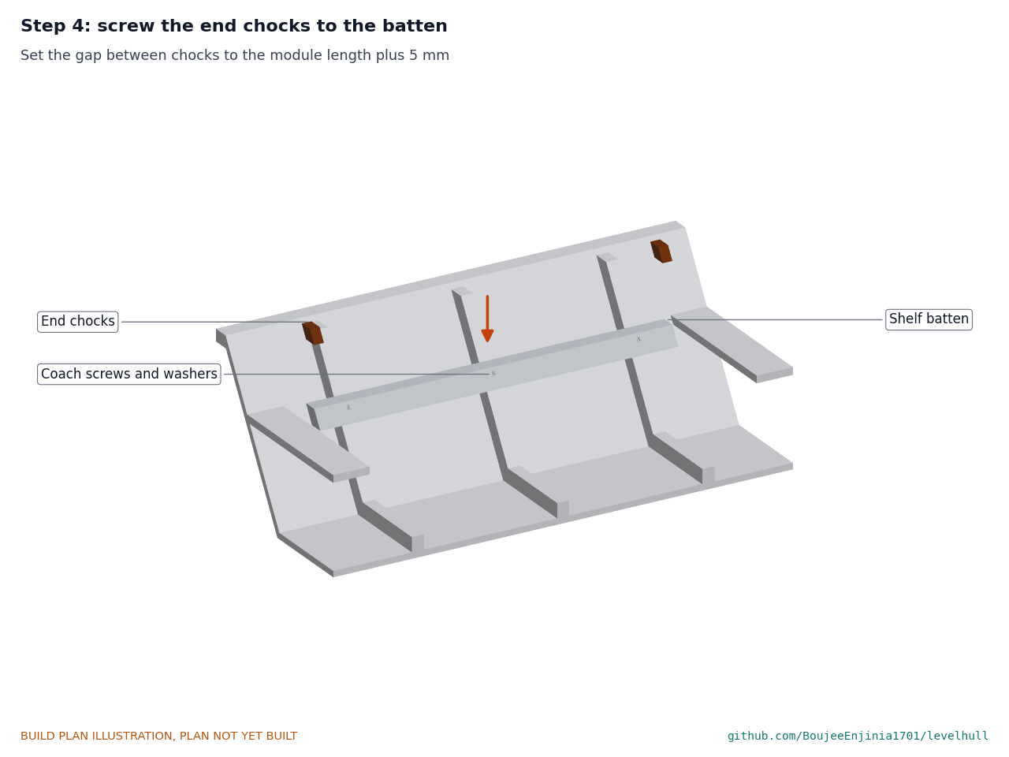
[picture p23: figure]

Set the aft chock at the batten's aft end mark, then the forward chock so the gap is the module length plus 5 mm. Two screws each.

Step 5: lay the straps

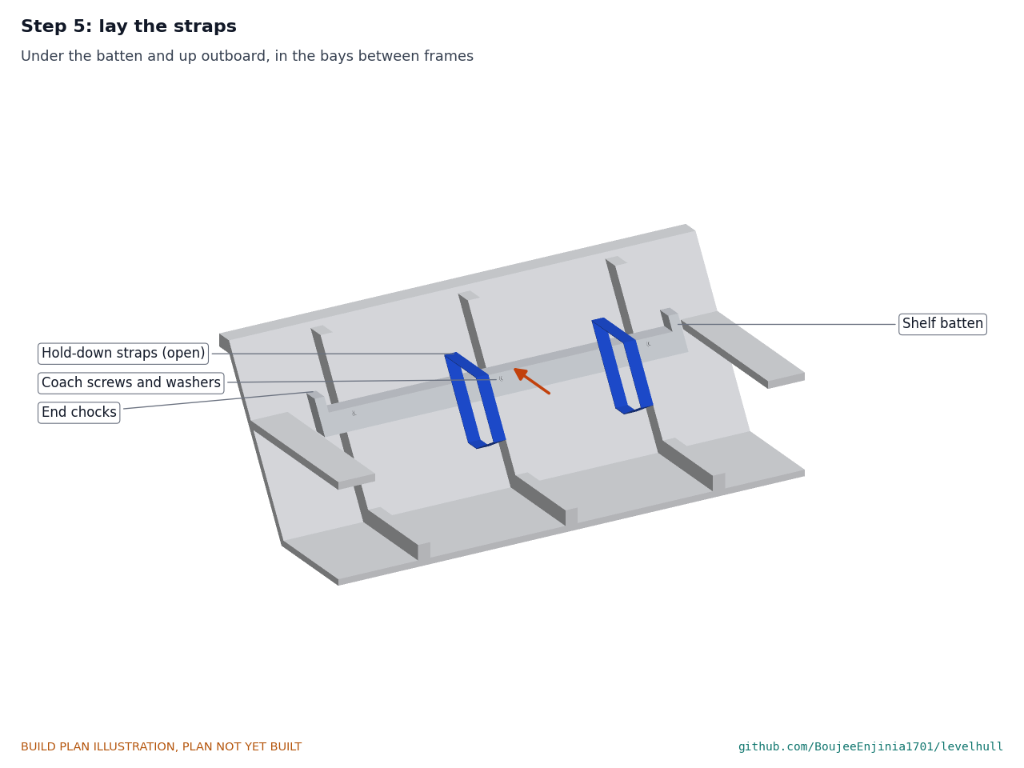
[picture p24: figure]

Pass two straps, open, under the batten and up the outboard side in the bays between frames, with the D-ring ends hanging inboard.

Step 6: set the module on the batten

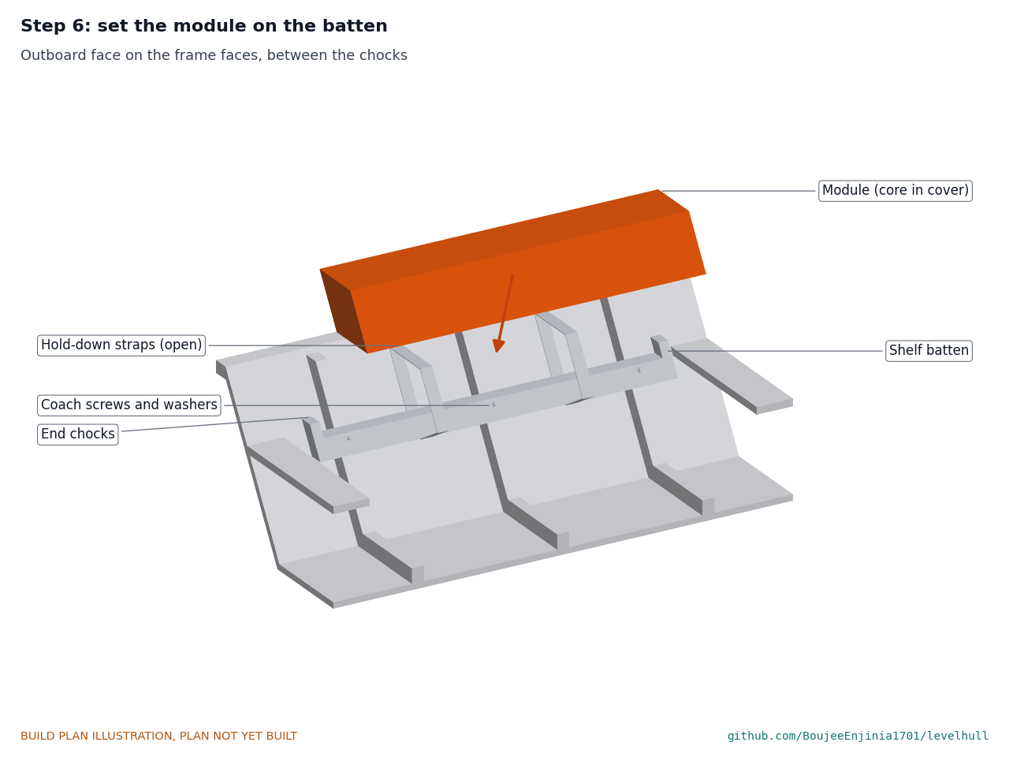
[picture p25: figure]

Lower the covered module onto the batten between the chocks, sloping face on the frames, laced ends at the chocks.

Step 7: close the straps

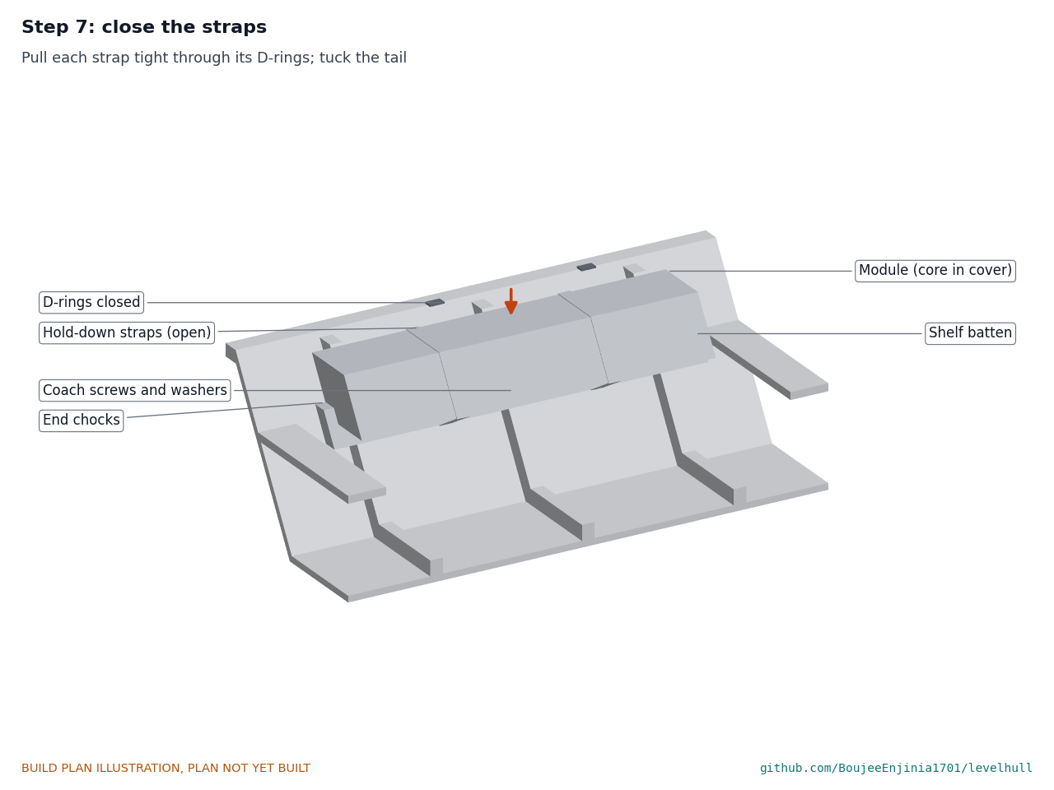
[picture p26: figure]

Bring each strap over the top and close it through its D-rings. Pull tight and tuck the tail under the strap.

Step 8: fit the grab-line eye bolts


Fit four eye bolts a side (section 3.8), between frames.

Step 9: reeve the grab lines


Tie one end to the aft eye, pass the line through each eye, leaving a bight about 150 mm deep between eyes, and tie off at the forward eye.

Step 10: paint the freeboard marks, stow the bailers


Mask and paint a 20 mm orange band on the outside of each side amidships (2.9 to 3.3 m from the transom), its top edge 50 mm below the top of the gunwale. Tie the bailers to a thwart and stow them on the floor between frames.

### 5. First checks

Table 2. First checks (the plan lists them; a TRL 4 test report records them).

Check | Requirement | How | Pass when
Fit | R5 | Measure the space between the module tops; walk the canoe | 900 mm or more clear; thwarts, nets and motor controls usable
Batten pull | R7 | Hand pull on every batten; one bay loaded upward through its straps to 1.1 kN (twice the full lift of a 1,400 mm module) | No movement, no cracking at the frames
Strap hold | R7 | Pull each strap tail hard by hand | No slip at the D-rings
Swamp test, design load | R1, R2, R3, R11 | In sheltered water under 1.2 m deep, fill the canoe with motor and gear aboard and four crew holding on in life jackets; read freeboard and inclinometer after 1 hour | Afloat; water below both freeboard marks; heel and trim within 10 deg
Crew on one side | R13 | All four crew hold one grab line | Heel within 10 deg
One module out | R12 | Remove the largest module and repeat | Still afloat
Bail-out | R4 | Two crew bail with the two bailers, timed | 200 mm freeboard within 15 minutes
Fitting time | R8 | Time the fitting on the second canoe | One working day

### 6. Safety stops

Work stops at each point below until what is listed is true.
S1, before drilling the frames: frames and their fastenings to the planks are sound; the drill depth flag is set at 50 mm.
S2, before the first swamp test: every batten passed the pull check, every strap passed the hold check, and the canoe's owner has agreed to the test.
S3, before anyone enters the water: a powered safety boat with a crew is standing by, the water is sheltered and under 1.2 m deep, there is no wind over force 3 and no rain or lightning, it is daylight, and every person wears a life jacket.
S4, before filling the canoe: the motor is off, its fuel tank closed and tied in, and nobody is near the propeller. S5, before fishing use: the swamp test at design load has passed and the owner has been shown the freeboard marks and told that the kit never replaces life jackets.

### 7. Tools, skills and workspace

Workshop: a table saw or ripping saw and a hand plane for the battens; a long knife or hot wire and a straightedge for the foam; a sewing machine for heavy canvas, or a tailor or sail maker; an eyelet punch. At the canoe: a bevel gauge, clamps, a drill with 4, 5.5, 8 and 9 mm bits and a depth flag, a 13 mm socket wrench, screwdrivers, masking tape and a brush.
Skills: a canoe builder or carpenter for the battens and screws; a tailor or sail maker for the covers.
Workspace: shade and a level place on the beach for the canoe; a sheltered shallow place with a safety boat for the swamp test.

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
### 8. Where the numbers come from

Model and checks: | cad/src/model.py | (126 constructability checks pass), STEP files in | cad/step/ .
General arrangement: | cad/drawings/LVH-DWG-001 | (Rev P2); making sketches | cad/drawings/LVH-DWG-101 | to
106 ; pictures from | cad/src/build_plan_media.py .
Calculations: | docs/04-calcs/01-sizing.md | (LVH-CAL-001) and | docs/04-calcs/sizing.py , with | docs/04-
calcs/results.csv .
Parts: | bom/bom.csv .
Changes for construction: | docs/decisions/0002-design-for-construction.md | (LVH-DDR-002).

•
•

•

•
•

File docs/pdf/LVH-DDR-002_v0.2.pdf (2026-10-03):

L E V E L H U L L · D E S I G N D E C I S I O N R E C O R D

# LevelHull design for construction

### Design Molecule Lab · designmolecule.com

D O C U M E N T CO N T RO L

Document ID | LVH-DDR-002 | Version | 0.2
Status | Draft | Date | 2026-10-03
Author | Amish Chadha | License | CERN-OHL-S-2.0
Project TRL | TRL 3 | Proof of concept
Repository | github.com/BoujeeEnjinia1701/levelhull
Source | docs/decisions/0002-design-for-construction.md @ uncommitted

R EV I S I O N H I STO RY

Version | Date | Author | Change
0.2 | 2026-10-03 | Amish Chadha | C3 cross-referenced to LVH-DDR-003 (modules widened to 220 mm)
0.1 | 2026-10-03 | Amish Chadha

Design made constructable; changes C1 to C12 and assumptions A1 to A5 decided under Amish's 2026-10-03 pre-approval

D R A F T · N O T F O R F A B R I C A T I O N

# 0002: Design for construction

Date: 2026-10-03
Status: decided. Decided by Amish under his pre-approval of 2026-10-03: "start with the first 14 repos from the list of 29 projects. I pre-approve the batch runs along with any recommendations you come up with. I also accept any cost overruns or variations from the assumed scope cost."

## Context

STANDARDS section 18 asks that every part can be made by a stated process and fits and fastens to its neighbours. The TRL 1 concept named "foam blocks in protective covers, strapped and fixed" with "fixing straps and cleats", but said nothing about what the straps pull against, how a block sits on a flared side, or where the lift goes into the hull. The constructability review of the model ( cad/src/model.py , 126 checks: overlaps with planks, frames and thwarts; contact between module, batten and frames; screw depth in the frames; straps clear of the frames; eye bolts through the strake; gauge fit) led to the changes below. None changes what the product does or its pitch. C1 follows D1 of LVH-DDR-001.

## Changes

Table 1. Changes made for construction.

•
•

# | The concept had | The constructable design has | Why

C1 | Blocks low along the inside faces | Modules high under the gunwale, top 30 mm below it, outboard face on the frames' inner faces | Roll stability when swamped (D1); the frame faces form a flat, regular bearing surface
C2 | One block per side, size open | Four modules a side between the thwarts: 880, 1,400, 1,400 and 1,100 mm | Thwarts stay in place; each module is light (under 4 kg) and handled by one person
C3 | Rectangular blocks | Parallelogram section 200 x 200 mm (widened to 220 mm by LVH-DDR-003): four equal 50 mm strips with both long edges cut at the flare angle, each layer set 31 mm further out | Sits flat on the sloping frame faces; every strip is the same cut
C4 | "Cleats" | A hardwood shelf batten under each module, 50 mm thick square to the frame faces, 70 mm high, 40 mm past each module end | Gives the module a seat and the straps an anchor, and spreads the lift over two or three frames
C5 | Fixings unspecified | One M8 x 100 coach screw into every frame a batten crosses, square to the batten face, 50 mm into the frame, tip 10 mm short of the planks | No new holes in the planking below the waterline; screw factor 5.5 on the full lift
C6 | Nothing stopping fore and aft movement | End chocks 40 mm long and 50 mm high screwed to the batten at both ends of each module | The straps alone could let a module creep along the batten
C7 | "Fixing straps" | Closed loops of 50 mm polyester webbing round module and batten, two per module, in the bays between frames, running outboard of the module in the 60 mm gap at the planks; stainless double D-ring friction buckles | A loop needs no anchor of its own; D-rings have no spring or cam to corrode
C8 | Foam blocks | Layers held by the cover and straps, no glue | Polyethylene foam does not glue reliably with common adhesives
C9 | Protective covers | Sewn PVC-coated polyester tarpaulin sleeves, 150 mm end flaps laced through eyelets | A tailor or sail maker can make and replace them; foam can be inspected

C10 Hull sizes taken by

| hand | A plywood setting gauge hooked over the gunwale marks the batten top and bottom on every frame | Every batten at the same height on a hull without drawings
C11 Nothing to hold | Four M8 eye bolts a side through the rubbing strake and top
| | plank, between frames, and a 12 mm grab line in bights | D7; above every waterline

C12 "Freeboard mark",

| "bailer" | A painted band whose top edge is 50 mm below the gunwale amidships, both sides; two 10 L buckets on lanyards stowed between frames | The R2 check is visible in the swamp test; bailers cannot float away

## Assumptions decided with the changes

A1. The canoe's frames are at most 600 mm apart and at least 60 mm deep from the planks, so each batten crosses two frames and each screw has 50 mm of wood. Conservative: on a hull with shallower frames the screw is shortened to keep 10 mm clear of the planks and a third frame is added to the batten; never through the planking.

•

A2. Wet hull timber is as dense as water (D3). Relaxed only by weighing and measuring the hull.
A3. Frame-to-plank fastenings are sound. Each frame takes at most 0.19 kN of lift; fastenings are inspected before fitting and any loose or rotten frame is repaired first.
A4. Foam density 30 kg/m3 and water uptake under 1 % by volume, to confirm from the supplier's data sheet and by immersion at TRL 4.
A5. Strengths of the webbing (10 kN), D-ring pair (4 kN) and coach screw (1.5 kN sideways) to confirm with the parts bought.

## Consequences

The kit has 13 kinds of part, five of them made (gauge, battens, chocks, cores, covers) with saws, a plane, a drill, a knife and a sewing machine.
Kit mass 67 kg; the battens are the heaviest part (39 kg with the chocks).
The general arrangement LVH-DWG-001 is at Rev P2; making sketches LVH-DWG-101 to 106; build plan LVH-BLD-001.
design_state: constructable | in | project.yaml .

Safety: The fixings carry the full lift of a module pushed under water. Every batten is pull-tested by hand and one bay per canoe is proof-loaded to twice its share before the swamp test (LVH-BLD-001, sections 5 and 6).

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
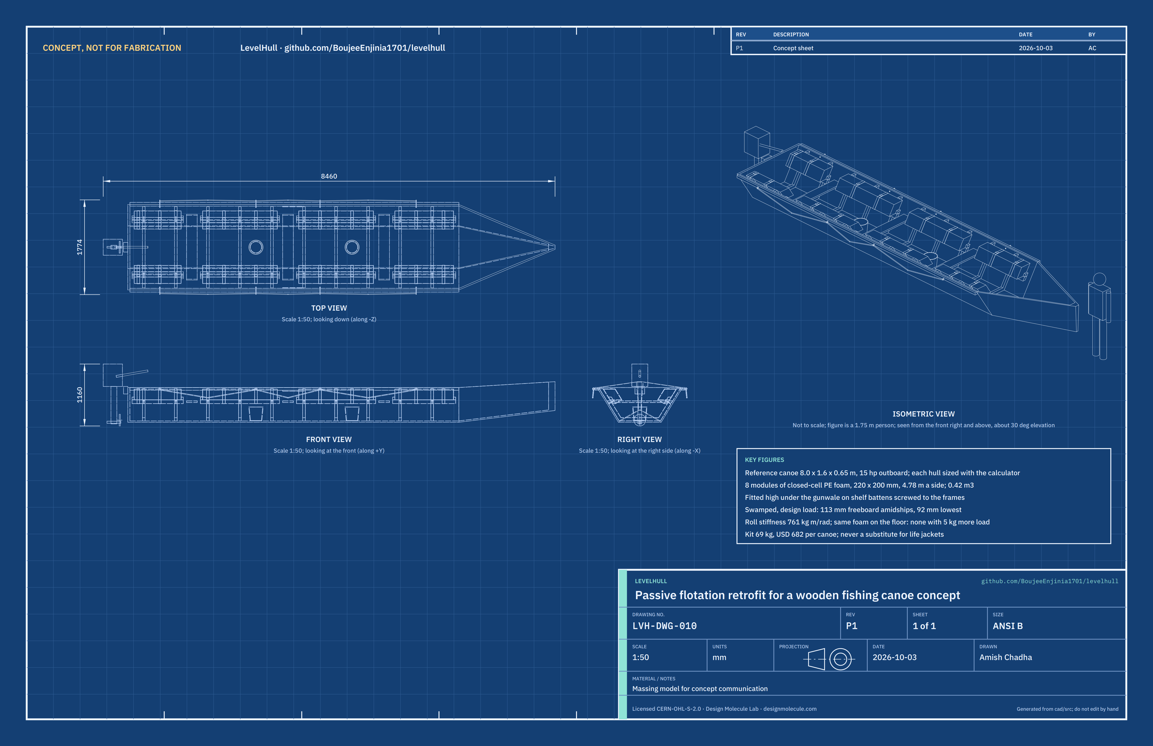
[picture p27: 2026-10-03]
media/concept-blueprint.png

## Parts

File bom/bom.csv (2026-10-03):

line | item | qty | spec | supplier | unit_cost_usd | make_buy | notes
1 | Setting gauge | 1 | 12 mm exterior plywood, about 360 x 450 mm offcut, cut to the gauge outline with two saw notches; one gauge per hull shape | Local timber yard | 4.00 | Make | A fitting tool; kept by the builder and reused on every canoe of the same section
2 | Shelf batten | 8 | Durable hardwood rail ripped from 50 x 100 mm stock, top and bottom planed to the side flare (31.6 deg on the reference canoe) to a 50 x 82 mm parallelogram; lengths 960 (2), 1480 (4) and 1180 (2) mm; ends and holes sealed | Local timber yard or boatyard | 7.00 | Make | 12 m bought at about USD 4.70 per metre; 10.2 m used. Mass about 3.7 kg per metre at 900 kg/m3
3 | Coach screw M8 x 100 with washer | 24 | M8 x 100 mm hex-head coach (lag) screw and 8.4 x 24 mm washer, stainless A4 or hot-dip galvanised; 20 fitted, 4 spare | Fastener or marine hardware supplier | 1.80 | Buy | One into every frame each batten crosses; pilot hole 5.5 mm in the frame
4 | End chock | 16 | Hardwood block 40 mm long, cut from batten offcuts to the batten section and 50 mm high; two 5 x 60 mm stainless wood screws each | Batten offcuts | 0.40 | Make | Unit cost is the two screws; the wood is batten offcut
5 | Foam sheet for the cores | 6 | Closed-cell polyethylene foam sheet 2,000 x 1,000 x 50 mm, about 30 kg/m3, water absorption under 1 % by volume (supplier data to confirm), not polystyrene and not open-cell polyurethane | Packaging foam or fishing float supplier | 55.00 | Buy | Cut into 24 strips 216 mm wide (220 mm modules less the cover; four across each sheet, LVH-DDR-003) with both long edges bevelled to the flare; 8 cores of four layers; 0.40 m3 net in the cores; no spare strip; the narrow edge offcuts give the immersion samples
6 | Cover tarpaulin | 15 | PVC-coated polyester tarpaulin, 650 g/m2, UV stabilised, per square metre | Truck cover or sail maker | 5.00 | Buy | Eight sleeves 220 x 200 mm inside with laced end flaps; 14.3 m2 used (LVH-CAL-001 | K2); quantity raised from 14 to 15 m2 for the wider modules at the same USD 5.00 per m2
7 | Cover thread eyelets and lacing | 1 | UV-stabilised polyester sewing thread, 64 brass or stainless 10 mm eyelets, 20 m of 4 mm polyester lacing cord | Sail maker or market | 25.00 | Buy | Sewn by a local tailor or sail maker
8 | Strap webbing | 25 | Polyester webbing 50 mm wide, UV stabilised, breaking strength at least 10 kN (to confirm), per metre | Rigging or cargo strap supplier | 1.20 | Buy | 16 straps cut 1.25 m long (was 1.2 m; LVH-DDR-003) | 20 m in all; ends heat-sealed
9 | Double D-ring pair | 16 | Stainless steel double D-ring pair for 50 mm webbing, 5 mm wire, sewn into one end of each strap | Marine hardware supplier | 2.00 | Buy | Friction buckle with no moving parts
10 | Grab-line eye bolt | 8 | M8 x 100 mm stainless eye bolt with 30 mm eye, two washers and a nyloc nut | Marine hardware supplier | 3.00 | Buy | Four per side through the rubbing strake and top plank
11 | Grab line | 14 | 12 mm polyester three-strand rope, per metre | Fishing supply or market | 0.80 | Buy | One line per side hanging in bights about 150 mm deep between the eyes
12 | Bailer | 2 | 10 L plastic bucket with a 1.5 m lanyard of 6 mm rope tied to a thwart | Market | 6.00 | Buy | Stowed on the floor between frames
13 | Swamp test kit | 1 | 250 ml orange marine enamel for the freeboard marks, masking tape, and a bubble inclinometer reading to 1 deg | Hardware store | 23.00 | Buy | Freeboard marks painted 50 mm below the gunwale amidships on both sides
14 | Sealer and bedding | 1 | Wood preservative or epoxy sealer for the batten ends, chocks and every screw hole; 250 ml | Hardware store | 10.00 | Buy | Keeps the frames from rotting at the new holes

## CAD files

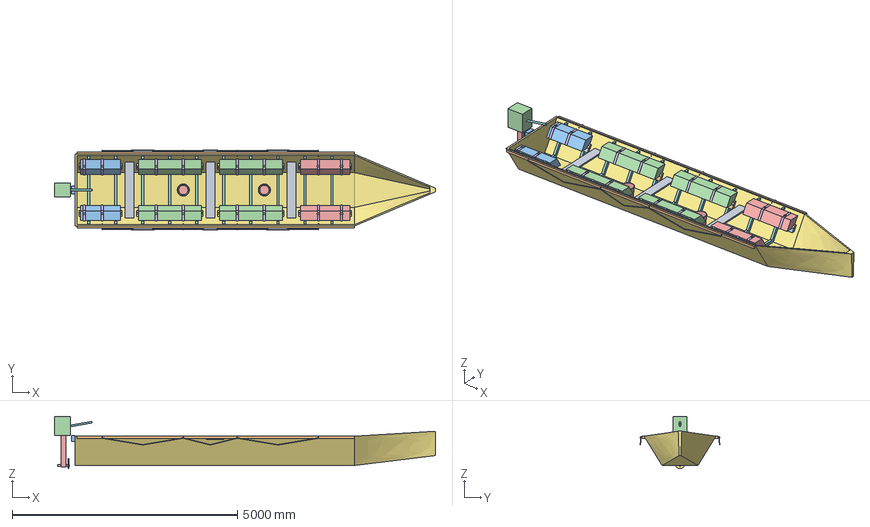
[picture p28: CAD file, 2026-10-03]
cad/step/levelhull-assembly.step
8460.0 x 1774.0 x 1160.0 mm

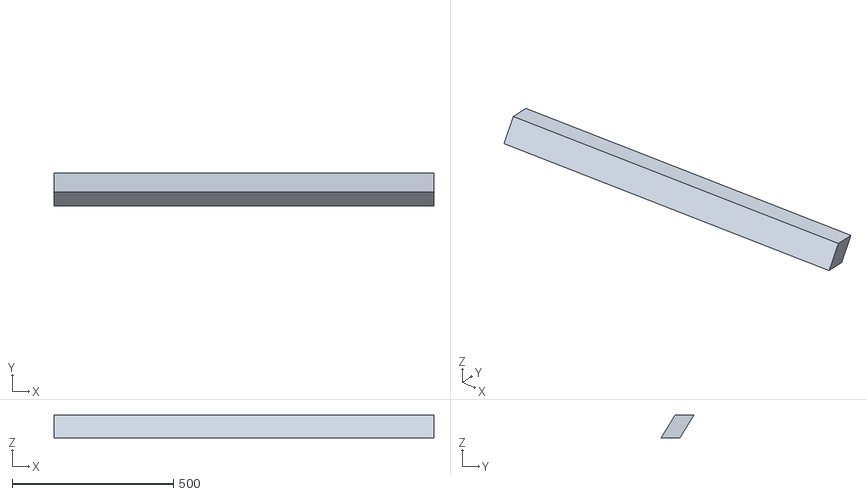
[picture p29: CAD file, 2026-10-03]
cad/stl/shelf-batten-4.stl
1180.0 x 101.8 x 70.0

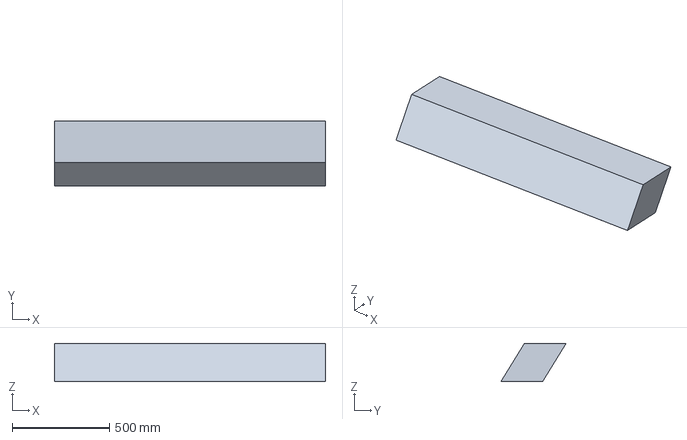
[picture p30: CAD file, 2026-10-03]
cad/step/foam-core-3-1400mm.step
1396.0 x 335.9 x 196.0 mm

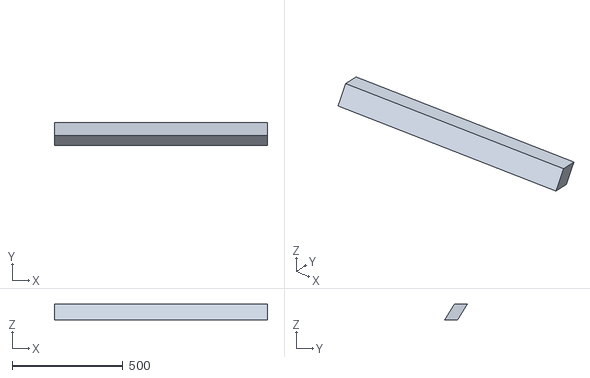
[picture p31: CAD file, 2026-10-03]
cad/stl/shelf-batten-1.stl
960.0 x 101.8 x 70.0

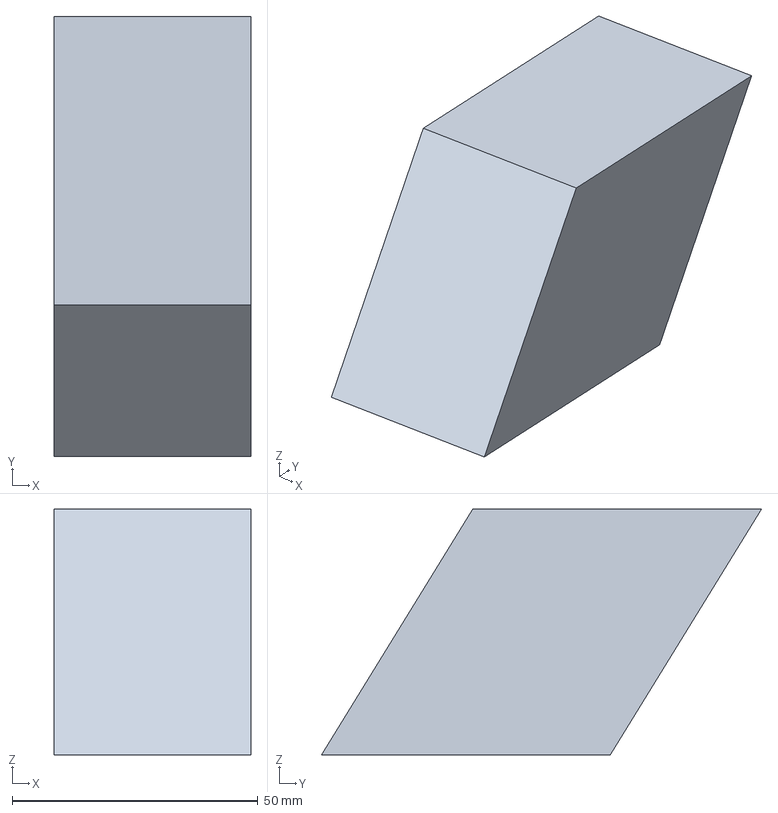
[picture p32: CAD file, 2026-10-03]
cad/step/end-chock.step
40.0 x 89.5 x 50.0 mm

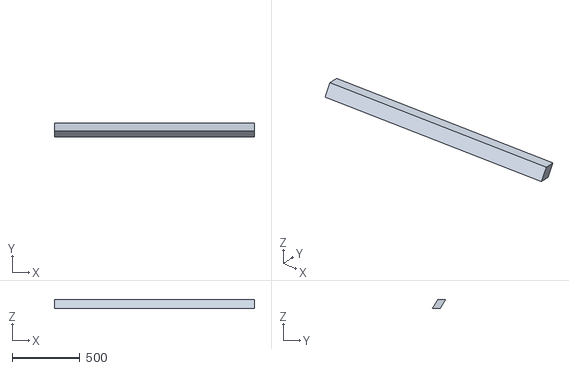
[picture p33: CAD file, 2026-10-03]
cad/stl/shelf-batten-2.stl
1480.0 x 101.8 x 70.0

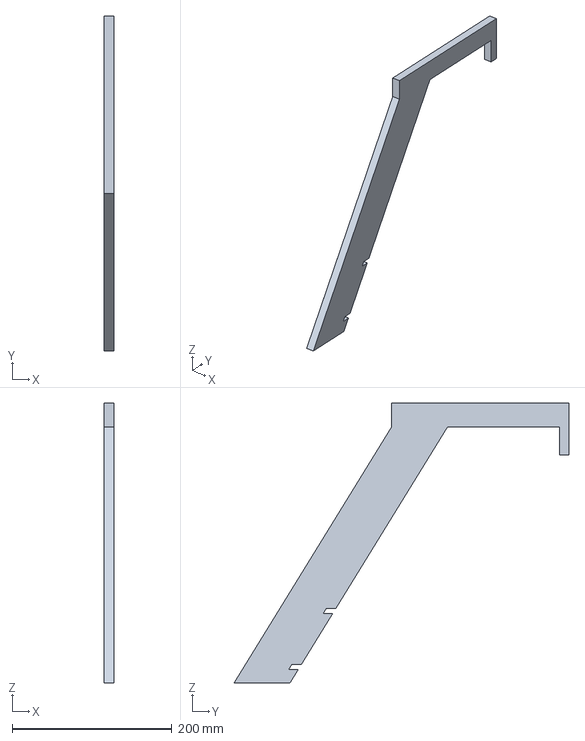
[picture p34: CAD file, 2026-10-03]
cad/step/setting-gauge.step
12.0 x 418.7 x 350.0 mm

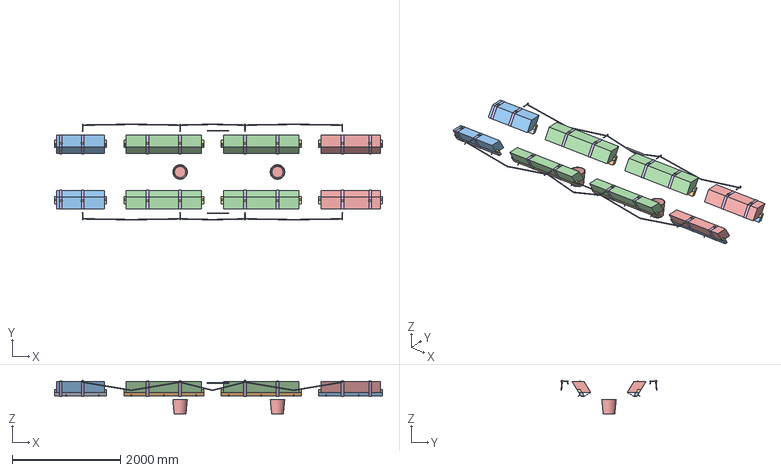
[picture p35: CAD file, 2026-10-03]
cad/step/levelhull-kit.step
6060.0 x 1774.0 x 620.0 mm

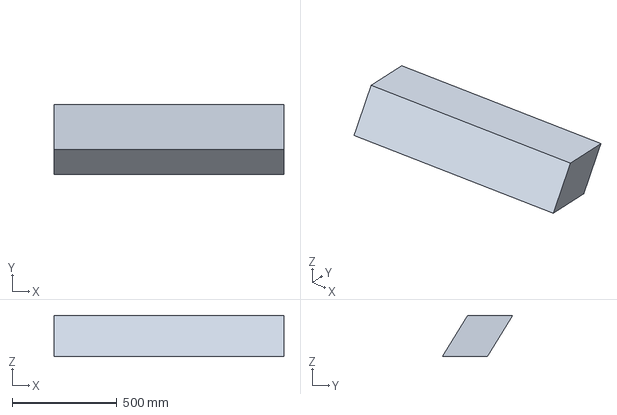
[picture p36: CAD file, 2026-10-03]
cad/step/foam-core-4-1100mm.step
1096.0 x 335.9 x 196.0 mm

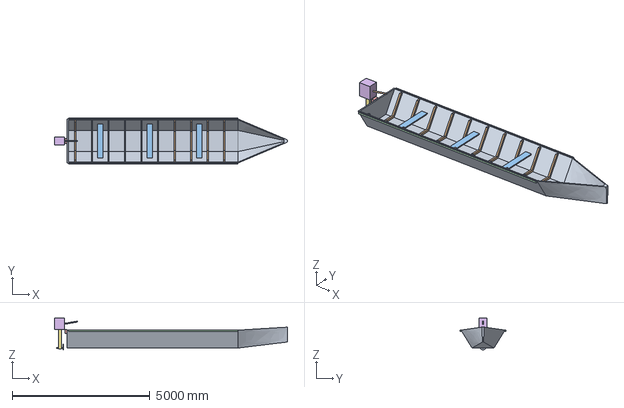
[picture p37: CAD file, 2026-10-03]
cad/step/reference-canoe-context.step
8460.0 x 1680.0 x 1160.0 mm

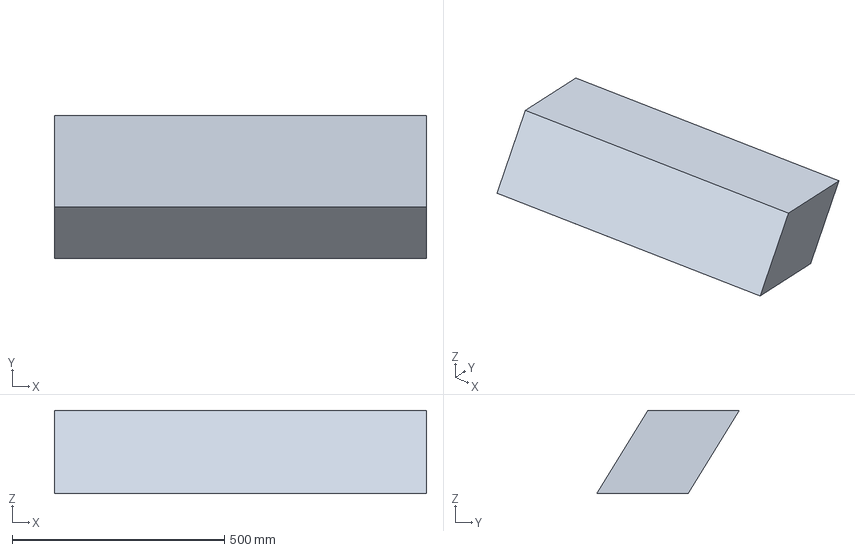
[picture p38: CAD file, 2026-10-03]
cad/step/foam-core-1-880mm.step
876.0 x 335.9 x 196.0 mm

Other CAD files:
cad/stl/shelf-batten-3.stl
cad/step/foam-core-2-1400mm.step
cad/stl/end-chock.stl
cad/stl/setting-gauge.stl

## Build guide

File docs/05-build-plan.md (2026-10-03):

---
doc_id: LVH-BLD-001
title: LevelHull prototype build plan
project: LevelHull
doc_type: Build plan
version: "0.2"
status: Draft
date: '2026-10-03'
author: Amish Chadha
license: CERN-OHL-S-2.0
revisions:
- version: "0.1"
  date: '2026-10-03'
  author: Amish Chadha
  change: First build plan; design made constructable (LVH-DDR-002)
- version: "0.2"
  date: '2026-10-03'
  author: Amish Chadha
  change: Modules widened from 200 to 220 mm (LVH-DDR-003); foam strips, covers, straps and pictures updated
---

# LevelHull prototype build plan

**Plan, not yet built.** How to make the flotation kit and fit it to the first canoe, component by component. Building and testing to it is TRL 4 work. Decisions are kept in the design decisions register (`docs/06-design-decisions.md`), not here.

> **Safety:** LevelHull is flotation for the boat. It is never a substitute for life jackets, and it is not certified lifesaving equipment. The fitted canoe is not used for fishing until it has passed the fixing pull test and a swamp test in sheltered, shallow water with a safety boat and every person in a life jacket (sections 5 and 6). Work with power tools and solvents needs eye protection and air.

## 1. What you are building

Every component, pulled apart and numbered in build order

*Figure 1. The kit for one canoe, in build order. One of the eight module bays is shown; the counts are for the whole canoe.*

The kit turns an ordinary planked fishing canoe into one that floats upright when it fills with water. It has eight buoyancy modules, four along each side, high under the gunwale between the thwarts. Each module is four layers of closed-cell foam in a sewn tarpaulin sleeve, sitting on a hardwood shelf batten that is screwed into the canoe's frames, held down by two webbing straps and kept from sliding by a wooden chock at each end. Grab lines along both sides, two bailers and a painted freeboard mark on each side complete it. Five parts are made (a plywood setting gauge, the battens, the chocks, the foam cores and the covers); the rest are bought. Parts cost about USD 682 per canoe. The sizes are for the reference canoe, 8.0 m long, 1.6 m in beam and 0.65 m deep with a 15 hp outboard; measure each canoe and size it with the calculator first.

## 2. What changed to make it buildable

*Table 1. Changes from the concept.*

| Component | The concept had | The buildable design has | Why |
| --- | --- | --- | --- |
| Modules | Blocks low along the sides | High under the gunwale, top 30 mm below it, lying on the frame faces | Upright when swamped |
| Module shape | Rectangular blocks, one per side | Four per side between the thwarts, each a stack of four equal foam strips cut to the side slope, 220 mm wide and 200 mm high | Sits flat on the sloping frames; light to handle |
| Seat | "Cleats" | A hardwood shelf batten under each module | Gives the straps an anchor and spreads the lift over the frames |
| Fixings | Not specified | One coach screw into every frame a batten crosses, stopping short of the planks | No new holes in the planks below the waterline |
| End stops | None | A chock at each end of each module | Stops the module creeping fore and aft |
| Straps | "Fixing straps" | Closed webbing loops round module and batten, in the bays between frames, with D-ring buckles | No separate anchor; nothing to corrode or jam |
| Covers | "Protective covers" | Sewn tarpaulin sleeves with laced ends | Made and replaced by a tailor; foam can be checked |
| Fitting | Measured by hand | A plywood setting gauge for the batten height | Same height on every frame |
| Hand holds | None | Grab lines on four eye bolts a side | Something for the crew to hold in the water |

Cut across the canoe

*Figure 2. Cut across the canoe through module 2: the modules lie high on the frame faces.*

## 3. Making the components

Make the foam cores and covers in the workshop before the canoe comes in, so the fitting takes one day.

### 3.1 Setting gauge

Making sketch: setting gauge

**What it is and what it is made from.** A fitting tool: a strip of 12 mm exterior plywood about 450 mm long and 70 mm wide with a hook at the top. Hooked over the gunwale at a frame, it lies flat on the frame's inner face and its two notches show where the top and bottom of the shelf batten go. One gauge serves every canoe of the same shape.

**How to make it.**

1. Cut a plywood blank about 360 x 450 mm.
2. Mark the long edge at the slope of the canoe's side, measured on the first frame with a bevel gauge (31.6 deg from upright on the reference canoe).
3. Cut the strip 70 mm wide along that edge, with the hook at the top: a 30 mm thick bar across the gunwale and a 35 mm lip that drops outside the rubbing strake.
4. Offer it up at the first frame. Trim the underside of the hook until the long edge lies flat on the frame face from the gunwale down.
5. Cut two saw notches, 12 mm deep, on the long edge: the top of the batten 230 mm below the top of the gunwale, and the bottom 300 mm below it, measured straight down.

**How it fits the parts next to it.**

Close-up: the gauge on a frame

*Figure 3. The gauge hooked over the gunwale, its long edge on the frame face.*

The hook rests on the top of the planking and rubbing strake; the lip touches the outside of the strake; the long edge lies on the frame face.

**Check before moving on.** On three frames along the canoe, the gauge sits flat with no rocking and the hook seats fully.

### 3.2 Shelf battens

Making sketch: shelf batten

**What it is and what it is made from.** Eight hardwood rails, one under each module, from 50 x 100 mm durable hardwood. Each is 50 mm thick square to the frame faces and 70 mm high, with the top and bottom cut level, so its section is a 50 x 82 mm parallelogram. Lengths: two of 960 mm, four of 1,480 mm and two of 1,180 mm (each module length plus 80 mm).

**How to make it.**

1. Rip the stock to about 85 mm.
2. Plane the top and bottom edges to the side slope (31.6 deg from square on the reference canoe) so both are level when the wide face lies on the frames; finished height 70 mm.
3. Cut to length.
4. Lay the batten against the canoe at its marks and mark the centre of every frame it crosses on its inboard face, 45 mm below the top edge measured up the face.
5. Drill 9 mm clearance holes there, square to the face.
6. Seal the ends and holes; cut the chocks for the same module from the offcut (section 3.3).

**How it fits the parts next to it.**

Close-up: batten to frame, cut through the screw

*Figure 4. Batten on a frame, cut through the coach screw. The screw goes 50 mm into the frame and stops 10 mm short of the plank.*

The wide face lies on the frame faces; the top edge is on the upper gauge mark. One M8 x 100 coach screw with a 24 mm washer goes through each hole into the frame, in a 5.5 mm pilot hole 50 mm deep. The module sits on the top edge.

**Check before moving on.** Each batten touches every frame it crosses; a straightedge laid on the tops of the two battens of one module bay shows them level with each other across the canoe.

### 3.3 End chocks

Making sketch: end chock

**What it is and what it is made from.** Sixteen hardwood blocks from batten offcut, 40 mm long, 50 mm high and the batten's width, with the same sloping outboard face.

**How to make it.**

1. Cut the offcut to 40 mm lengths.
2. Trim each to 50 mm high, keeping the sloping face.
3. Drill two 4 mm pilot holes down through each and seal the cut ends.

**How it fits the parts next to it.**

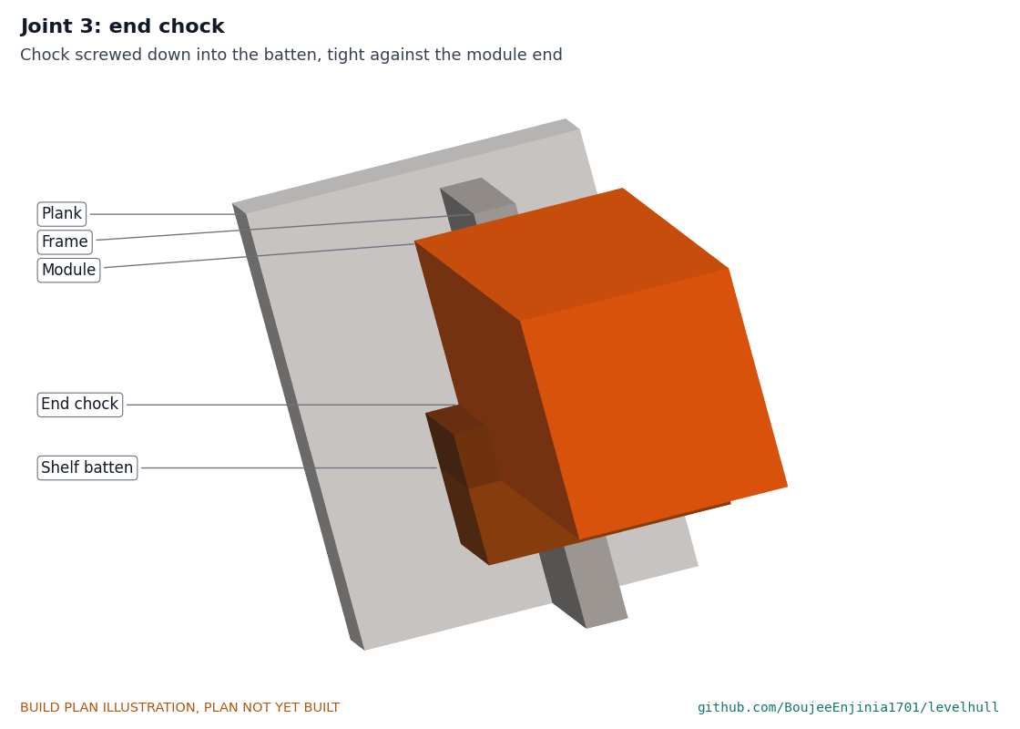
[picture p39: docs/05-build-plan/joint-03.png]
Close-up: end chock


*Figure 5. An end chock on the batten, against the end of the module.*

The chock sits on the batten top at the end of the module, sloping face against the frame line, screwed down with two 5 x 60 mm stainless screws. The gap between the two chocks of a batten is the module length plus 5 mm.

**Check before moving on.** The chock does not move when pushed by hand.

### 3.4 Foam cores

Making sketch: foam core

**What it is and what it is made from.** Eight stacks of four layers of 50 mm closed-cell polyethylene foam (about 30 kg/m3), cut from 2,000 x 1,000 mm sheets. Not polystyrene, which fuel dissolves, and not open-cell foam, which soaks up water.

**How to make it.**

1. Cut the sheets into strips 216 mm wide (measured level), with both long edges cut at the side slope, using a long knife or hot wire against a straightedge; four strips come from each sheet, which uses all 24 strips from the six sheets. Keep the narrow strip left at the edge of each sheet for the water uptake samples.
2. Cut the strips to length: 876 mm (8 strips), 1,396 mm (16) and 1,096 mm (8).
3. Stack four strips of the same length, each set 31 mm further outboard than the one below, so the stack's faces are flat parallelograms. No glue.

**How it fits the parts next to it.** The stack slides into its cover (section 3.5), sloping side to the frames.

**Check before moving on.** A stack fits its cover with no gap at the corners, and each strip has no cracks or tears.

### 3.5 Covers

Making sketch: cover

**What it is and what it is made from.** Eight sleeves of PVC-coated polyester tarpaulin, 650 g/m2, UV stabilised, sewn with UV-stabilised polyester thread. Inside size 220 mm wide by 200 mm high by the module length (880, 1,400 or 1,100 mm), with 150 mm flaps at each end.

**How to make it.**

1. Cut a panel 1,040 mm wide by the module length plus 300 mm.
2. Fold it round a stacked core and sew a 130 mm overlap along the top inboard corner with two rows of stitching.
3. Set eight 10 mm eyelets in each end flap.
4. Slide the core in, fold the flaps and lace them shut with 4 mm cord.

**How it fits the parts next to it.** The covered module sits on its batten between the chocks, its sloping face on the frame faces; the straps go round it (section 3.6).

**Check before moving on.** The laced ends are tight and the stitching has no gaps.

### 3.6 Hold-down straps with D-rings

Making sketch: strap with D-rings

**What it is and what it is made from.** Sixteen loops of 50 mm UV-stabilised polyester webbing, about 1.25 m long, each with a pair of stainless double D-rings sewn into one end.

**How to make it.**

1. Cut 1.25 m of webbing; heat-seal both ends.
2. Fold 60 mm of one end round both D-rings and sew it with a box-and-cross stitch.

**How it fits the parts next to it.**

Close-up: strap round module and batten, cut

*Figure 6. A strap round module and batten, cut through the strap. It runs outboard of the module in the gap between the frames.*

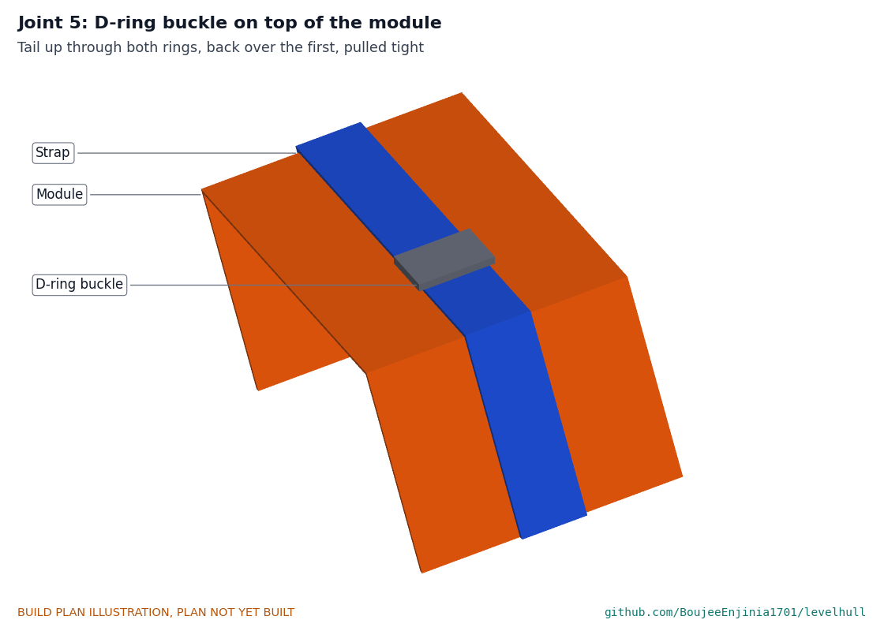
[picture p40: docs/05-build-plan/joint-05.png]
Close-up: D-ring buckle


*Figure 7. The D-ring buckle on top of the module.*

Each strap goes in a bay between two frames, under the batten, up between the module and the planks, over the top of the module and down its inboard face. The tail goes up through both rings, back over the first and is pulled tight.

**Check before moving on.** Pulled hard by hand, the buckle does not slip.

### 3.7 Coach screws (bought)

Twenty-four M8 x 100 mm hex coach screws with 24 mm washers, stainless A4 or hot-dip galvanised (20 fitted, 4 spare). Bed each in sealer.

### 3.8 Grab-line eye bolts and grab lines (bought)

Eight M8 x 100 mm stainless eye bolts with 30 mm eyes, washers and nyloc nuts; 14 m of 12 mm polyester three-strand rope.

Close-up: eye bolt through strake and plank, cut

*Figure 8. An eye bolt through the rubbing strake and top plank, nut inside.*

Drill 8 mm through the rubbing strake and top plank, 25 mm below the gunwale top, between frames, at 0.6, 2.4, 3.6 and 5.4 m from the transom on each side. Bed the bolt in sealer and tighten the nut inside against a washer.

### 3.9 Bailers and swamp test kit (bought)

Two 10 L plastic buckets with 1.5 m lanyards of 6 mm rope; orange marine enamel, masking tape and a bubble inclinometer reading to 1 deg; sealer for the battens, chocks and holes.

## 4. Putting it together

Steps 1 to 7 show module 2 on the port side; repeat them for all eight bays. Start with the canoe dry, empty and level on the beach, supported under the keel line.

### Step 1: mark the batten heights with the gauge

Step 1

Hook the gauge over the gunwale at every frame the battens will cross and mark both notches on the frame face. Check that the thwarts and frames are sound before going on.

### Step 2: hold each batten to its marks

Step 2

Lay the batten's wide face on the frame faces with its top edge on the upper marks, and clamp it.

### Step 3: drill and drive the coach screws

Step 3

Through each clearance hole, drill a 5.5 mm pilot 50 mm deep into the frame, square to the batten face. Put a tape flag on the drill bit at the depth so it cannot reach the plank. Drive the screws with their washers, bedded in sealer, until snug.

### Step 4: screw the end chocks to the batten

Step 4

Set the aft chock at the batten's aft end mark, then the forward chock so the gap is the module length plus 5 mm. Two screws each.

### Step 5: lay the straps

Step 5

Pass two straps, open, under the batten and up the outboard side in the bays between frames, with the D-ring ends hanging inboard.

### Step 6: set the module on the batten

Step 6

Lower the covered module onto the batten between the chocks, sloping face on the frames, laced ends at the chocks.

### Step 7: close the straps

Step 7

Bring each strap over the top and close it through its D-rings. Pull tight and tuck the tail under the strap.

### Step 8: fit the grab-line eye bolts

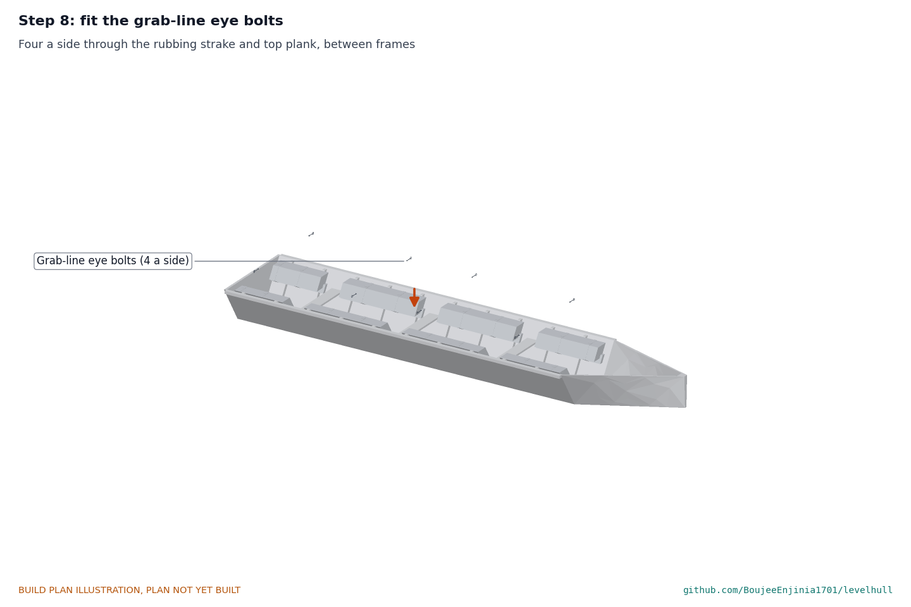
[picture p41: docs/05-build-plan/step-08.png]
Step 8


Fit four eye bolts a side (section 3.8), between frames.

### Step 9: reeve the grab lines

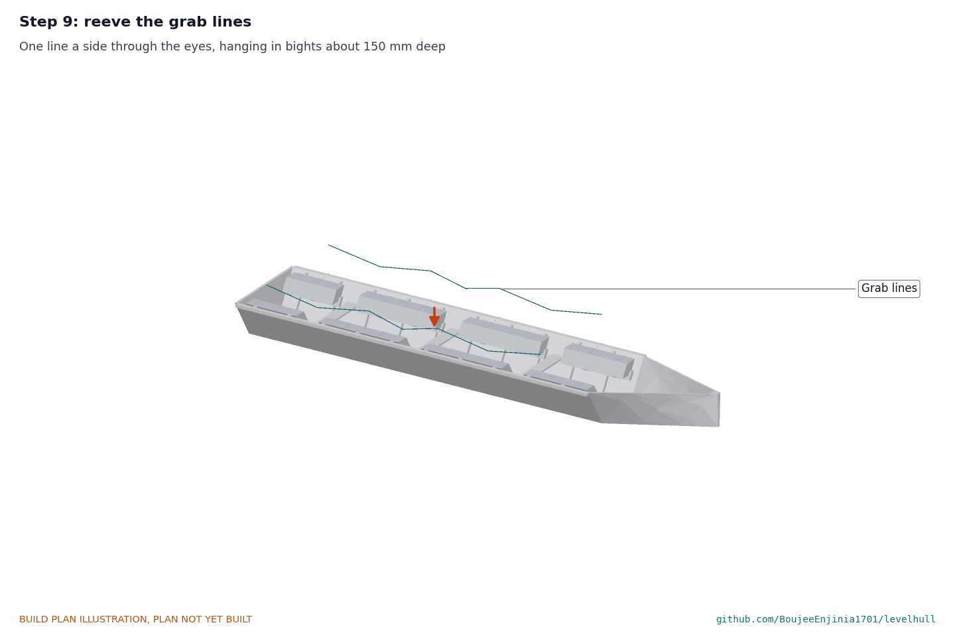
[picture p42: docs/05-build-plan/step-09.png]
Step 9


Tie one end to the aft eye, pass the line through each eye, leaving a bight about 150 mm deep between eyes, and tie off at the forward eye.

### Step 10: paint the freeboard marks, stow the bailers

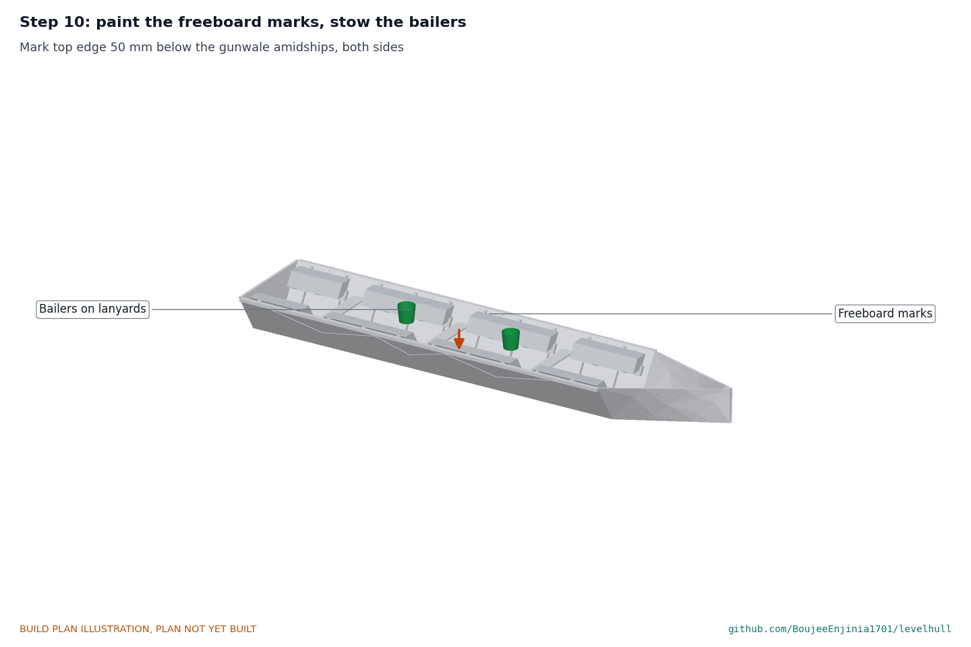
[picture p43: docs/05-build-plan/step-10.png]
Step 10


Mask and paint a 20 mm orange band on the outside of each side amidships (2.9 to 3.3 m from the transom), its top edge 50 mm below the top of the gunwale. Tie the bailers to a thwart and stow them on the floor between frames.

## 5. First checks

*Table 2. First checks (the plan lists them; a TRL 4 test report records them).*

| Check | Requirement | How | Pass when |
| --- | --- | --- | --- |
| Fit | R5 | Measure the space between the module tops; walk the canoe | 900 mm or more clear; thwarts, nets and motor controls usable |
| Batten pull | R7 | Hand pull on every batten; one bay loaded upward through its straps to 1.1 kN (twice the full lift of a 1,400 mm module) | No movement, no cracking at the frames |
| Strap hold | R7 | Pull each strap tail hard by hand | No slip at the D-rings |
| Swamp test, design load | R1, R2, R3, R11 | In sheltered water under 1.2 m deep, fill the canoe with motor and gear aboard and four crew holding on in life jackets; read freeboard and inclinometer after 1 hour | Afloat; water below both freeboard marks; heel and trim within 10 deg |
| Crew on one side | R13 | All four crew hold one grab line | Heel within 10 deg |
| One module out | R12 | Remove the largest module and repeat | Still afloat |
| Bail-out | R4 | Two crew bail with the two bailers, timed | 200 mm freeboard within 15 minutes |
| Fitting time | R8 | Time the fitting on the second canoe | One working day |

## 6. Safety stops

Work stops at each point below until what is listed is true.

- **S1, before drilling the frames:** frames and their fastenings to the planks are sound; the drill depth flag is set at 50 mm.
- **S2, before the first swamp test:** every batten passed the pull check, every strap passed the hold check, and the canoe's owner has agreed to the test.
- **S3, before anyone enters the water:** a powered safety boat with a crew is standing by, the water is sheltered and under 1.2 m deep, there is no wind over force 3 and no rain or lightning, it is daylight, and every person wears a life jacket.
- **S4, before filling the canoe:** the motor is off, its fuel tank closed and tied in, and nobody is near the propeller.
- **S5, before fishing use:** the swamp test at design load has passed and the owner has been shown the freeboard marks and told that the kit never replaces life jackets.

## 7. Tools, skills and workspace

- Workshop: a table saw or ripping saw and a hand plane for the battens; a long knife or hot wire and a straightedge for the foam; a sewing machine for heavy canvas, or a tailor or sail maker; an eyelet punch.
- At the canoe: a bevel gauge, clamps, a drill with 4, 5.5, 8 and 9 mm bits and a depth flag, a 13 mm socket wrench, screwdrivers, masking tape and a brush.
- Skills: a canoe builder or carpenter for the battens and screws; a tailor or sail maker for the covers.
- Workspace: shade and a level place on the beach for the canoe; a sheltered shallow place with a safety boat for the swamp test.

## 8. Where the numbers come from

- Model and checks: `cad/src/model.py` (126 constructability checks pass), STEP files in `cad/step/`.
- General arrangement: `cad/drawings/LVH-DWG-001` (Rev P2); making sketches `cad/drawings/LVH-DWG-101` to `106`; pictures from `cad/src/build_plan_media.py`.
- Calculations: `docs/04-calcs/01-sizing.md` (LVH-CAL-001) and `docs/04-calcs/sizing.py`, with `docs/04-calcs/results.csv`.
- Parts: `bom/bom.csv`.
- Changes for construction: `docs/decisions/0002-design-for-construction.md` (LVH-DDR-002).

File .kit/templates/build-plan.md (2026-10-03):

---
doc_id: PRJ-BLD-001
title: Project prototype build plan
project: Project name
doc_type: Build plan
version: "0.1"
status: Draft
date: YYYY-MM-DD
author: Amish Chadha
license: CERN-OHL-S-2.0
revisions:
  - version: "0.1"
    date: YYYY-MM-DD
    author: Amish Chadha
    change: First build plan; design made constructable
---

# Project prototype build plan

**Plan, not yet built.** How to build the first proof-of-concept prototype, component by component. Building and testing to it is TRL 4 work. Decisions still to be made are kept in the design decisions register (`docs/06-design-decisions.md`), not here.

## 1. What you are building

Every component, pulled apart and numbered in build order

One short paragraph: what the prototype is, how many components, which are made and which are bought, and the main ways they are made.

## 2. What changed to make it buildable

| Component | The concept had | The buildable design has | Why |
| --- | --- | --- | --- |

## 3. Making the components

### 3.1 Component name

Making sketch

**What it is and what it is made from.**

**How to make it.**

1. Mark out ...
2. Cut ...

**How it fits the parts next to it.**

Close-up of the joint

**Check before moving on.**

## 4. Putting it together

### Step 1: ...

Step 1

## 5. First checks

| Check | Requirement | How | Pass when |
| --- | --- | --- | --- |

## 6. Safety stops

## 7. Tools, skills and workspace

## 8. Where the numbers come from

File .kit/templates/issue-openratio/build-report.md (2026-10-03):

---
name: Build report
about: Tell us what happened when you built, printed or tested part of this design
title: "Build report: "
labels: build-report
---

This is a research and educational prototype, not a medical device. It is a TRL 3 concept and is not released for fabrication. If you build any part of it, you do so at your own risk. Reports help everyone.

**What you built** (part, sub-assembly or test)

**Materials, tools and settings**

**What worked**

**What did not work, with photos or measurements if you have them**

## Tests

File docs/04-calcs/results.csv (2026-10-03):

tag | item | value | unit | requirement | status
G1 | Side flare of the reference canoe | 31.6 | deg
G2 | Modules per canoe | 8
G3 | Module run per side (four lengths) | 4780.0 | mm
G4 | Module section, 220 mm wide x 200 mm high (four 50 mm layers) | 0.044 | m2
G5 | Module envelope volume, both sides | 0.421 | m3
G6 | Foam core volume (inside the covers) | 0.402 | m3
G7 | Module bottom and top above the outside of the bottom | 420 and 620 | mm
G8 | Hull timber volume (planks, frames, thwarts, strakes) | 0.586 | m3
G9 | Dry hull mass at 750 kg/m3 (typical) | 439 | kg
K | Kit mass, foam | 12.1 | kg
K | Kit mass, covers | 9.3 | kg
K | Kit mass, battens and chocks | 39.4 | kg
K | Kit mass, screws, eye bolts, D-rings | 2.8 | kg
K | Kit mass, straps | 3.4 | kg
K | Kit mass, grab lines | 1.0 | kg
K | Kit mass, bailers | 1.0 | kg
K1 | Kit mass in all | 68.9 | kg
K2 | Cover area, eight sleeves with end flaps | 14.3 | m2
K3 | Strap webbing, all straps | 19.5 | m
L | Design net weight, crew holding on | 15.0 | kg
L | Design net weight, crew holding on | 15.0 | kg
L | Design net weight, crew holding on | 15.0 | kg
L | Design net weight, crew holding on | 15.0 | kg
L | Design net weight, outboard motor | 36.0 | kg
L | Design net weight, anchor and chain | 10.5 | kg
L | Design net weight, nets | 4.9 | kg
L | Design net weight, catch | 7.1 | kg
L | Design net weight, fuel tank | 0.0 | kg
L1 | Design net load (crew holding on, motor, gear, catch) | 118.5 | kg
F1 | Swamped, design load, fresh water: freeboard amidships (level) | 113 | mm
F2 | Swamped, design load: lowest freeboard on the gunwale with trim | 92 | mm | R2 | met
F3 | Swamped, design load: trim (positive bow down) | -0.39 | deg | R3 | met
F4 | Swamped, design load: timber above water (counted as load) | 109.1 | kg
F5 | Swamped, design load: transverse metacentric height | 3.1 | m
F6 | Swamped, design load: roll stiffness | 761 | kg m per rad
F7 | Net load the swamped canoe carries at 50 mm freeboard | 290 | kg
F8 | Reserve: capacity at 50 mm freeboard over design net load | 2.45 |  | R1 | met
F9 | Swamped, no crew holding on: freeboard, heel, trim | 128 mm, 0.0 deg, -0.14 deg |  | R3 | met
F10 | Four crew holding the port grab line: heel | 3.9 | deg | R3 | met
F11 | Four crew on one side: lowest freeboard | 44 | mm
F12 | Salt water, design load: lowest freeboard | 98 | mm
F13 | Foam lift down 5 % (R6 limit): lowest freeboard | 86 | mm
F14 | Largest module lost (port 2) and 5 % uptake: lowest freeboard | 25 | mm
F15 | Largest module lost: heel | 1.5 | deg
F16 | With typical 750 kg/m3 timber (lift not counted in design): freeboard amidships | 167 | mm
F17 | Same foam fitted low on the floor: roll stiffness | 283 | kg m per rad
F18 | Same foam fitted low: metacentric height | 0.68 | m
F19 | Same foam fitted low: heel with four crew on one side | 10.6 | deg
F20 | Same foam fitted low, 5 kg more load: roll stiffness | -5 | kg m per rad
V1 | Hull inside volume below the gunwale | 5.01 | m3
V2 | Module volume as a share of the inside volume | 8.4 | % | R5 | met
B1 | Water inside the swamped canoe | 3.48 | m3
B2 | Water that may stay aboard at 200 mm freeboard, all crew aboard | 2.31 | m3
B3 | Water to bail out | 1.17 | m3
B4 | Bail-out time, two crew at 100 L/min each (estimate) | 5.9 | min | R4 | met (estimate)
B5 | Dry canoe: draft added by the kit (waterplane about 6.4 m2) | 11 | mm
S1 | Largest module, full lift in salt water | 0.601 | kN
S2 | Per strap (two straps, both legs) | 0.301 | kN
S3 | Webbing factor (10 kN webbing, one leg carries half) | 66.5 |  | R7 | met
S4 | D-ring buckle factor (4 kN, to confirm) | 13.3 |  | R7 | met
S5 | Largest share on one coach screw (sideways) | 0.301 | kN
S6 | Coach screw factor (1.5 kN sideways in hardwood) | 5.0 |  | R7 | met
S7 | Total lift of all modules fully submerged (into the frames) | 4.11 | kN
S8 | Per frame, 10 frames per side | 0.205 | kN
T1 | Fitting time on the canoe, foam cores and covers made beforehand (estimate) | 6.3 | h | R8 | met (estimate)
C1 | Parts cost of one kit | 681.8 | USD
C2 | Parts for two canoes (one gauge) | 1359.6 | USD | R10 | over the value-engineering target by USD 360
C3 | Foam share of one kit | 48 | %
Z | Sizing sheet, 6.5 m paddle canoe, no motor, 3 crew: module run needed per side (available 3.8 m) | 2.45 | m
Z | Sizing sheet, 8.0 m canoe, 15 hp, 4 crew (reference): module run needed per side (available 4.8 m) | 3.8 | m
Z | Sizing sheet, 10 m canoe, 25 hp, 6 crew: module run needed per side (available 6.4 m) | 5.12 | m

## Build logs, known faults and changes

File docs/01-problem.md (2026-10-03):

---
doc_id: LVH-PRB-001
title: LevelHull problem statement
project: LevelHull
doc_type: Problem statement
version: "0.3"
status: Draft
date: '2026-10-03'
author: Amish Chadha
license: CERN-OHL-S-2.0
revisions:
- version: "0.1"
  date: '2026-09-30'
  author: Amish Chadha
  change: Initial scaffold
- version: "0.2"
  date: '2026-10-03'
  author: Amish Chadha
  change: TRL 2 and 3 update; constraints restated, open questions settled (LVH-DDR-001), first co-design candidates, safety section
- version: "0.3"
  date: '2026-10-03'
  author: Amish Chadha
  change: Settled answers restated for the 220 mm modules (LVH-DDR-003)
---

# LevelHull problem statement

When a wooden fishing canoe swamps, the crew loses the boat as a refuge just when they need it most. A small amount of well-placed buoyancy could change that.

## The problem

Deaths cluster in bad weather and at night, when waves swamp boats and rescue is least likely ([The Conversation](https://theconversation.com/lake-victoria-why-so-many-fishers-are-dying-and-what-can-be-done-about-it-232006)). Life jackets are the first line of defence, but many fishers do not wear them. A boat with enough built-in buoyancy to float level when swamped gives a second chance, which is what the US level flotation test checks ([USCG](https://www.uscgboating.org/assets/PDF/downloads/FLOTATION.pdf)).

Existing answers do not fit these boats. The US test is a benchmark for boats, not a method for retrofitting wooden fishing canoes. Inflatable emergency floats exist but depend on an inflation mechanism, and at least one such design is under patent until about 2032 ([US9139267B2](https://patents.google.com/patent/US9139267B2/en)). What is missing is an open, passive retrofit kit, with a sizing method, that a local builder can fit to the boats fishers already own.

## Users and context

*Table 1. Users.*

| User | Need | Context |
| --- | --- | --- |
| Canoe fishers and crews | A boat that stays afloat and level when swamped, so they can hold on and bail | Lakes, rivers and coasts; storms and night fishing; often no life jacket |
| Canoe owners | A retrofit that is affordable, lasts, and takes little space from the catch | Wooden canoes of many sizes, often with outboard motors |
| Local boatbuilders | A sizing sheet and fitting guide for different hulls | Beach yards with hand tools |
| Fisheries departments, beach management units and NGOs | A measure to promote alongside life jackets and weather warnings | Safety at sea programmes |

## Operating environment

- Fresh and salt water; lakes, estuaries and near-shore coastal waters.
- Strong sun and heat; boats beached and left in the open.
- Wooden hulls that take on water and are often wet inside.
- Fuel, fish slime, nets and abrasion from gear.
- Loads of crew, catch, gear and sometimes an outboard motor.

## Constraints

- Value-engineering target: USD 1,000 for the kits for two prototype canoes (a hypothetical control target, not a spending limit; STANDARDS section 18).
- Passive only: closed-cell foam or sealed rigid chambers; no inflation.
- Must not take up so much volume that it blocks work or catch storage.
- Fitted with hand tools by a local boatbuilder, without changing the hull shape and without new holes below the waterline.
- Materials must resist UV, fuel and abrasion and must not soak up water.
- Open design: hardware under CERN-OHL-S-2.0, sizing calculator under MIT.

## Out of scope

- Life jackets and personal flotation.
- New hull designs.
- Engines, propulsion and navigation equipment.
- Certification as lifesaving equipment.

## Prior work

*Table 2. Prior work.*

| Prior work | What it does | Gap for these users | Source |
| --- | --- | --- | --- |
| US Coast Guard level flotation test | Test method checking that a swamped small boat floats approximately level | A test benchmark, not a retrofit method or kit for wooden fishing canoes | [link](https://www.uscgboating.org/assets/PDF/downloads/FLOTATION.pdf) |
| US9139267B2, inflatable float (active to about 2032) | Emergency float that inflates to keep a craft afloat | Active inflation mechanism and patent restrictions; LevelHull stays passive | [link](https://patents.google.com/patent/US9139267B2/en) |
| RNLI sustainable lifesaving equipment | Programme supporting locally made lifesaving equipment in lower-income countries | Not a boat flotation retrofit | [link](https://rnli.org/what-we-do/international/lifesaving-interventions/sustainable-lifesaving-equipment) |

## Co-design

The first candidates to approach, in order (none approached yet): a beach management unit on the Kenyan shore of Lake Victoria, working with the canoe builders at its landing site; a national fisheries research institute in the region, for hull and load surveys; and a sea-safety programme that already trains fishers in the use of life jackets, so the kit is promoted alongside them. With the partner, measure real hulls (frame spacing and depth, flare, timber, motor) and loads, and swamp-test fitted canoes in sheltered, shallow water.

## Questions settled at TRL 2

These were the open questions of v0.1. Each is decided in LVH-DDR-001 under Amish's pre-approval of 2026-10-03; the numbers are in LVH-CAL-001.

*Table 3. Questions settled.*

| Question | Answer |
| --- | --- |
| Low along the sides, or higher under the gunwales? | High, under the gunwales, so the modules cut the waterline when the canoe is swamped. The same foam fitted low on the floor only just reaches the water surface: with four crew on one side it heels past 10 deg, and a few kilograms more load leave it with no roll stiffness at all, against 761 kg m per radian with the modules high. |
| Foam or sealed chambers? | Closed-cell polyethylene foam in tarpaulin covers. A puncture loses no lift and nothing needs sealing; chambers are kept for the sibling LaneSkiff concept. |
| How much lift does the wood give, and what does the motor change? | The design takes no credit for the wood: wet hull timber is counted as exactly as dense as water. A typical 750 kg/m3 hardwood would add about 54 mm of freeboard. The motor is counted at its full 36 kg at the transom; other motors are sized with the calculator. |
| Re-entry step? | Still parked; scope unchanged. Grab lines along both sides give the crew something to hold while they are in the water. |
| Promotion without implying life jackets are optional | Every document, the fitting guide and the kit itself carry "never a substitute for life jackets"; the swamp test is run with every person in a life jacket. |

## Safety

> **Safety:** LevelHull is flotation for a boat, not lifesaving equipment for people. It is never a substitute for life jackets, and it is not certified. A swamped canoe that floats can still roll in breaking waves and cannot protect the crew from cold water, night or exhaustion; the kit buys time to bail and to be seen. Fitted canoes are swamp-tested in sheltered, shallow water with a safety boat and every person in a life jacket before they go fishing.

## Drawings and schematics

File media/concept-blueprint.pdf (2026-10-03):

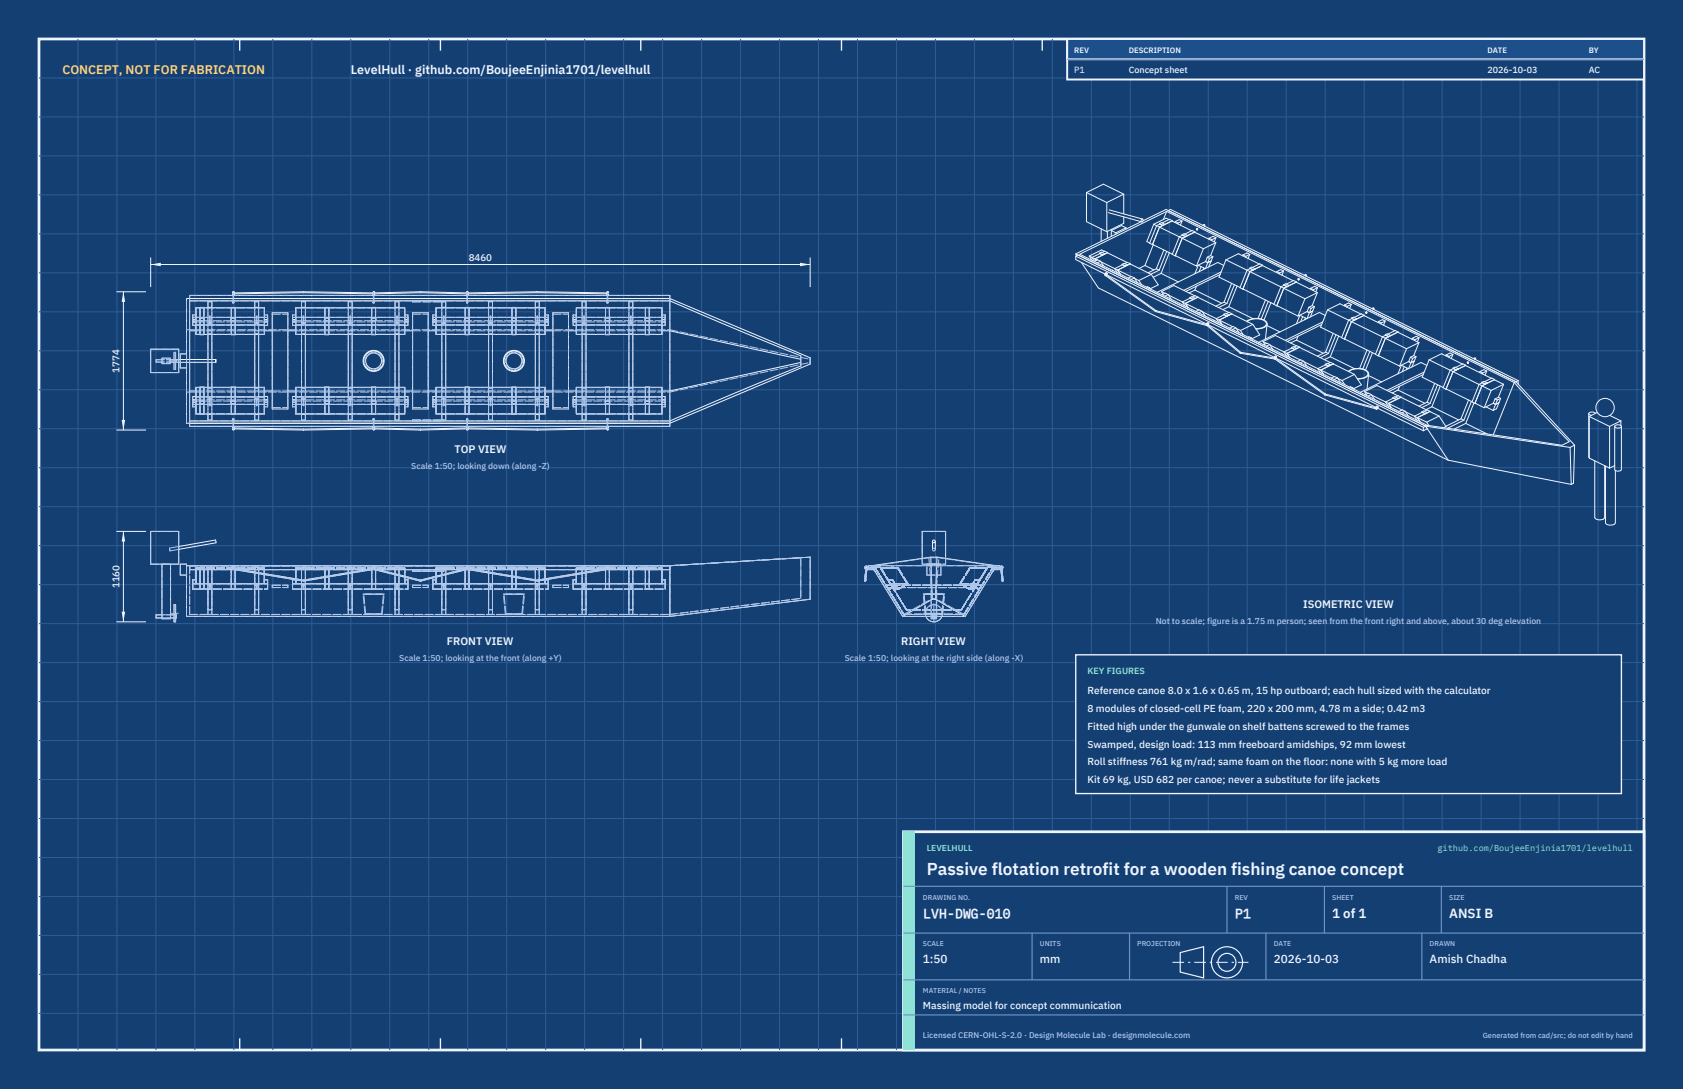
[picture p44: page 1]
CONCEPT, NOT FOR FABRICATION; LevelHull · github.com/BoujeeEnjinia1701/levelhull; FRONT VIEW; TOP VIEW; RIGHT VIEW; ISOMETRIC VIEW; REV; DESCRIPTION; DATE; Concept sheet; LEVELHULL; github.com/BoujeeEnjinia1701/levelhull; DRAWING NO. LVH-DWG-010; REV P1; SHEET 1 of 1; SIZE ANSI B; SCALE 1:50; UNITS mm; PROJECTION; DRAWN Amish Chadha; Licensed CERN-OHL-S-2.0 · Design Molecule Lab · designmolecule.com; Generated from cad/src; do not edit by hand

Scale 1:50; looking down (along -Z)

Not to scale; figure is a 1.75 m person; seen from the front right and above, about 30 deg elevation

Scale 1:50; looking at the front (along +Y)

Scale 1:50; looking at the right side (along -X)

KEY FIGURES
Reference canoe 8.0 x 1.6 x 0.65 m, 15 hp outboard; each hull sized with the calculator
8 modules of closed-cell PE foam, 220 x 200 mm, 4.78 m a side; 0.42 m3
Fitted high under the gunwale on shelf battens screwed to the frames
Swamped, design load: 113 mm freeboard amidships, 92 mm lowest
Roll stiffness 761 kg m/rad; same foam on the floor: none with 5 kg more load
Kit 69 kg, USD 682 per canoe; never a substitute for life jackets

Passive flotation retrofit for a wooden fishing canoe concept

MATERIAL / NOTES
Massing model for concept communication

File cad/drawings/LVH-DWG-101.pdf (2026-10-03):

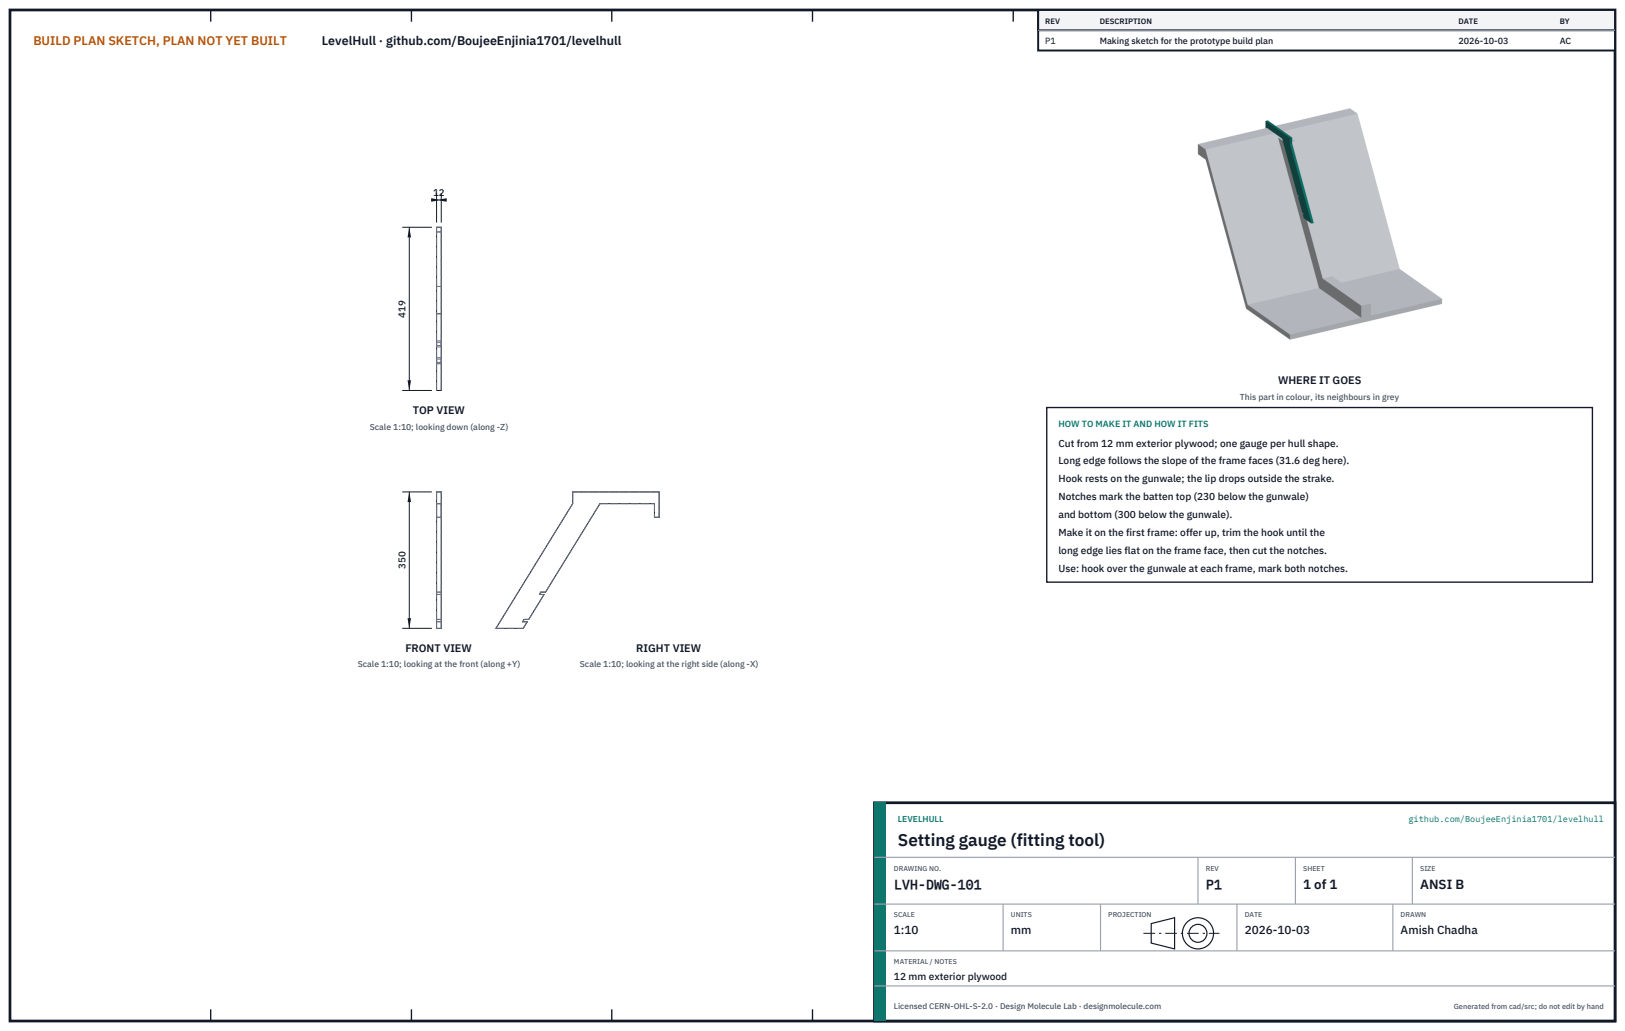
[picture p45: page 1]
BUILD PLAN SKETCH, PLAN NOT YET BUILT; LevelHull · github.com/BoujeeEnjinia1701/levelhull; FRONT VIEW; TOP VIEW; RIGHT VIEW; REV; DESCRIPTION; DATE; Making sketch for the prototype build plan; LEVELHULL; github.com/BoujeeEnjinia1701/levelhull; DRAWING NO. LVH-DWG-101; REV P1; SHEET 1 of 1; SIZE ANSI B; SCALE 1:10; UNITS mm; PROJECTION; DRAWN Amish Chadha; Licensed CERN-OHL-S-2.0 · Design Molecule Lab · designmolecule.com; Generated from cad/src; do not edit by hand

WHERE IT GOES

This part in colour, its neighbours in grey

Scale 1:10; looking down (along -Z)

HOW TO MAKE IT AND HOW IT FITS
Cut from 12 mm exterior plywood; one gauge per hull shape.
Long edge follows the slope of the frame faces (31.6 deg here).
Hook rests on the gunwale; the lip drops outside the strake.
Notches mark the batten top (230 below the gunwale)
and bottom (300 below the gunwale).
Make it on the first frame: offer up, trim the hook until the
long edge lies flat on the frame face, then cut the notches.
Use: hook over the gunwale at each frame, mark both notches.

Scale 1:10; looking at the front (along +Y)

Scale 1:10; looking at the right side (along -X)

Setting gauge (fitting tool)

MATERIAL / NOTES
12 mm exterior plywood

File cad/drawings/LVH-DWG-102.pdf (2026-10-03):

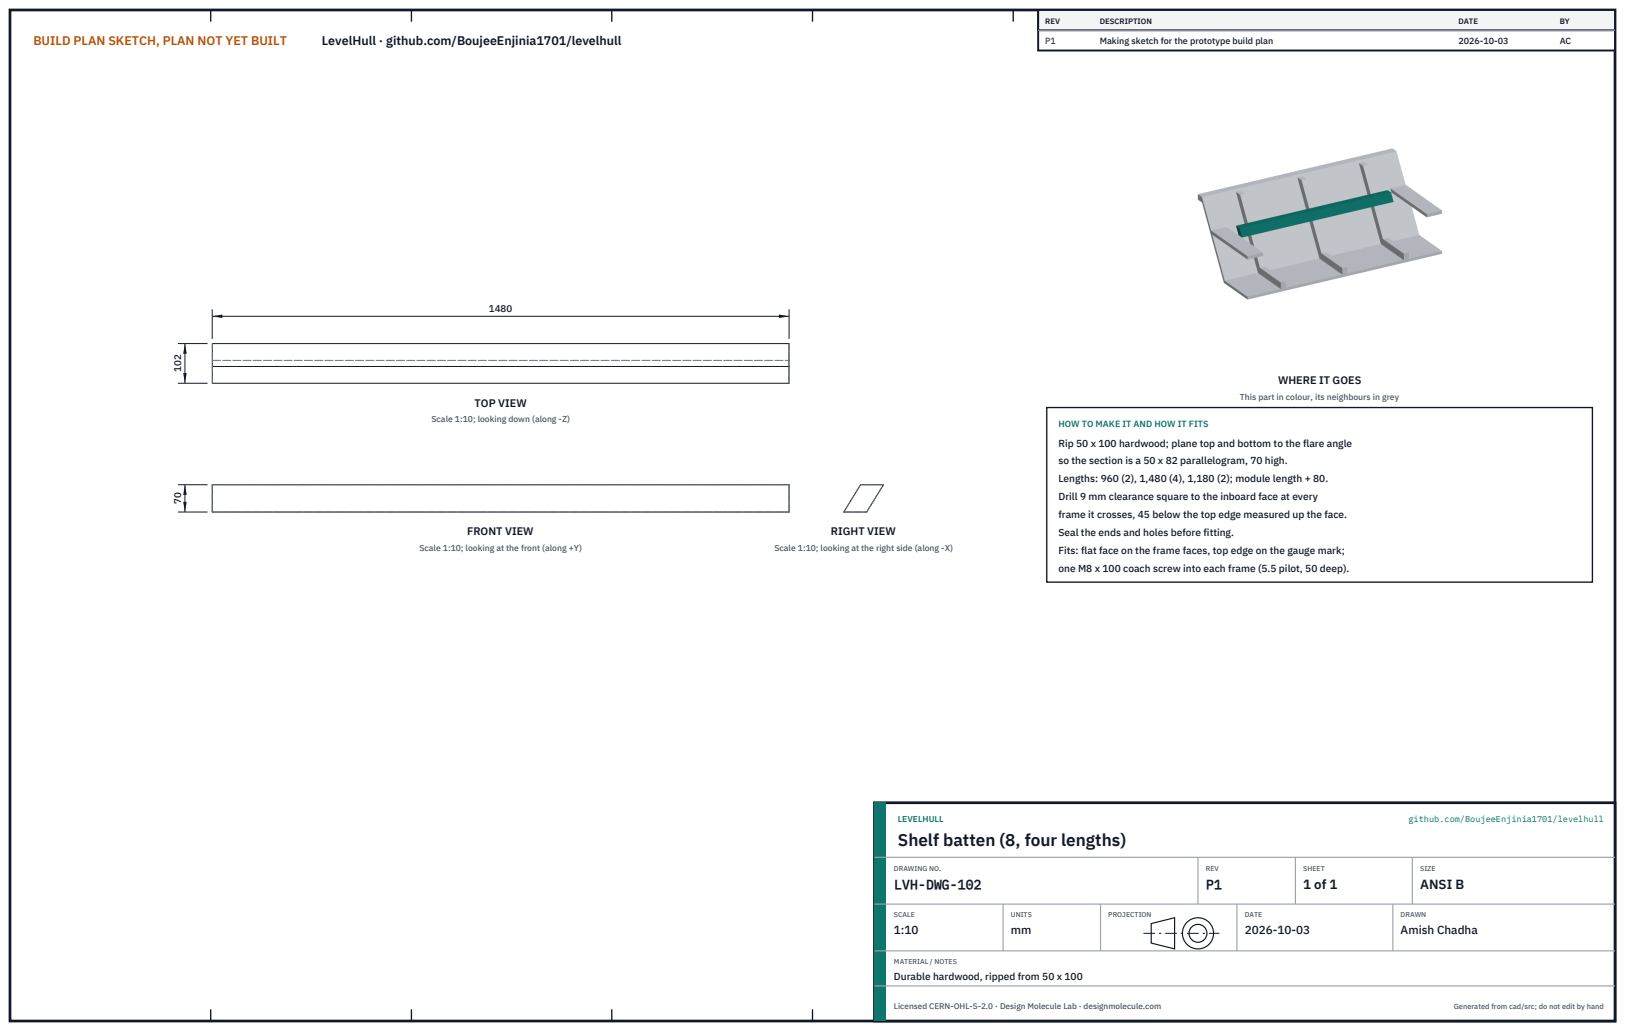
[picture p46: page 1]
BUILD PLAN SKETCH, PLAN NOT YET BUILT; LevelHull · github.com/BoujeeEnjinia1701/levelhull; FRONT VIEW; TOP VIEW; RIGHT VIEW; REV; DESCRIPTION; DATE; Making sketch for the prototype build plan; LEVELHULL; github.com/BoujeeEnjinia1701/levelhull; DRAWING NO. LVH-DWG-102; REV P1; SHEET 1 of 1; SIZE ANSI B; SCALE 1:10; UNITS mm; PROJECTION; DRAWN Amish Chadha; Licensed CERN-OHL-S-2.0 · Design Molecule Lab · designmolecule.com; Generated from cad/src; do not edit by hand

WHERE IT GOES

This part in colour, its neighbours in grey

Scale 1:10; looking down (along -Z)

HOW TO MAKE IT AND HOW IT FITS
Rip 50 x 100 hardwood; plane top and bottom to the flare angle
so the section is a 50 x 82 parallelogram, 70 high.
Lengths: 960 (2), 1,480 (4), 1,180 (2); module length + 80.
Drill 9 mm clearance square to the inboard face at every
frame it crosses, 45 below the top edge measured up the face.
Seal the ends and holes before fitting.
Fits: flat face on the frame faces, top edge on the gauge mark;
one M8 x 100 coach screw into each frame (5.5 pilot, 50 deep).

Scale 1:10; looking at the front (along +Y)

Scale 1:10; looking at the right side (along -X)

Shelf batten (8, four lengths)

MATERIAL / NOTES
Durable hardwood, ripped from 50 x 100

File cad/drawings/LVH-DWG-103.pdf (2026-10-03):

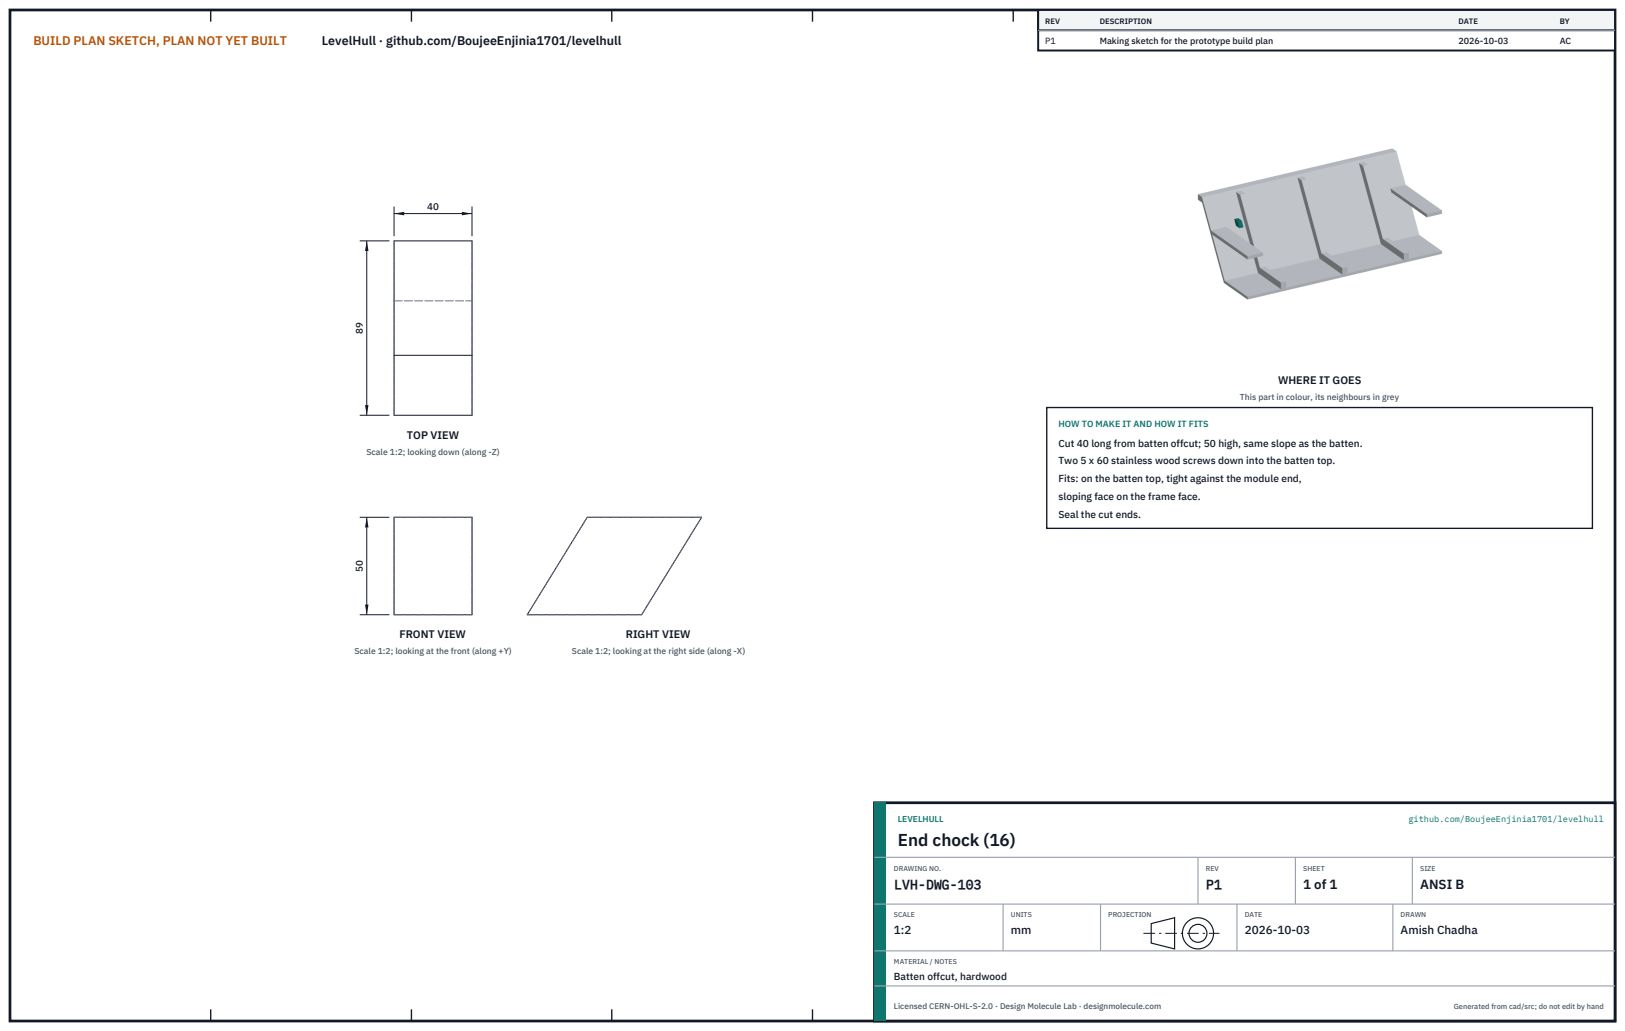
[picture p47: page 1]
BUILD PLAN SKETCH, PLAN NOT YET BUILT; LevelHull · github.com/BoujeeEnjinia1701/levelhull; FRONT VIEW; TOP VIEW; RIGHT VIEW; REV; DESCRIPTION; DATE; Making sketch for the prototype build plan; LEVELHULL; github.com/BoujeeEnjinia1701/levelhull; End chock (16); DRAWING NO. LVH-DWG-103; REV P1; SHEET 1 of 1; SIZE ANSI B; SCALE 1:2; UNITS mm; PROJECTION; DRAWN Amish Chadha; Licensed CERN-OHL-S-2.0 · Design Molecule Lab · designmolecule.com; Generated from cad/src; do not edit by hand

WHERE IT GOES

This part in colour, its neighbours in grey

HOW TO MAKE IT AND HOW IT FITS
Cut 40 long from batten offcut; 50 high, same slope as the batten.
Two 5 x 60 stainless wood screws down into the batten top.
Fits: on the batten top, tight against the module end,
sloping face on the frame face.
Seal the cut ends.

Scale 1:2; looking down (along -Z)

Scale 1:2; looking at the front (along +Y)

Scale 1:2; looking at the right side (along -X)

MATERIAL / NOTES
Batten offcut, hardwood

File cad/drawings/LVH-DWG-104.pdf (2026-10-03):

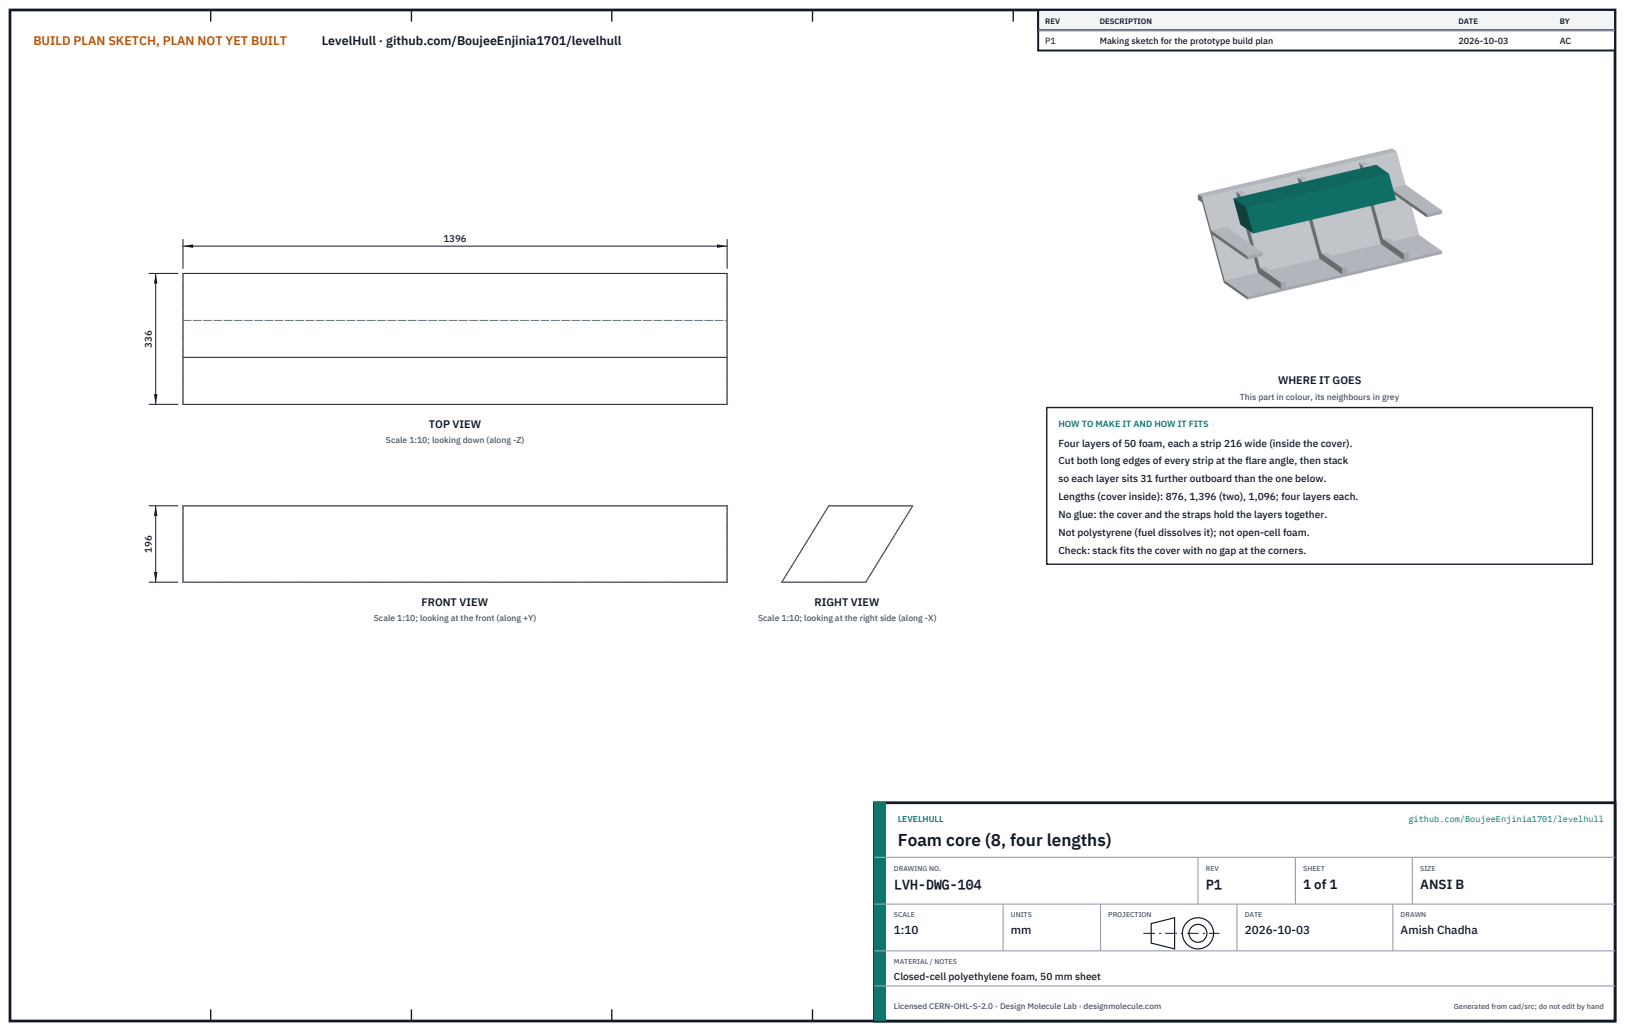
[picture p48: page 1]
BUILD PLAN SKETCH, PLAN NOT YET BUILT; LevelHull · github.com/BoujeeEnjinia1701/levelhull; FRONT VIEW; TOP VIEW; RIGHT VIEW; REV; DESCRIPTION; DATE; Making sketch for the prototype build plan; LEVELHULL; github.com/BoujeeEnjinia1701/levelhull; DRAWING NO. LVH-DWG-104; REV P1; SHEET 1 of 1; SIZE ANSI B; SCALE 1:10; UNITS mm; PROJECTION; DRAWN Amish Chadha; Licensed CERN-OHL-S-2.0 · Design Molecule Lab · designmolecule.com; Generated from cad/src; do not edit by hand

WHERE IT GOES

This part in colour, its neighbours in grey

HOW TO MAKE IT AND HOW IT FITS
Four layers of 50 foam, each a strip 216 wide (inside the cover).
Cut both long edges of every strip at the flare angle, then stack
so each layer sits 31 further outboard than the one below.
Lengths (cover inside): 876, 1,396 (two), 1,096; four layers each.
No glue: the cover and the straps hold the layers together.
Not polystyrene (fuel dissolves it); not open-cell foam.
Check: stack fits the cover with no gap at the corners.

Scale 1:10; looking down (along -Z)

Scale 1:10; looking at the front (along +Y)

Scale 1:10; looking at the right side (along -X)

Foam core (8, four lengths)

MATERIAL / NOTES
Closed-cell polyethylene foam, 50 mm sheet

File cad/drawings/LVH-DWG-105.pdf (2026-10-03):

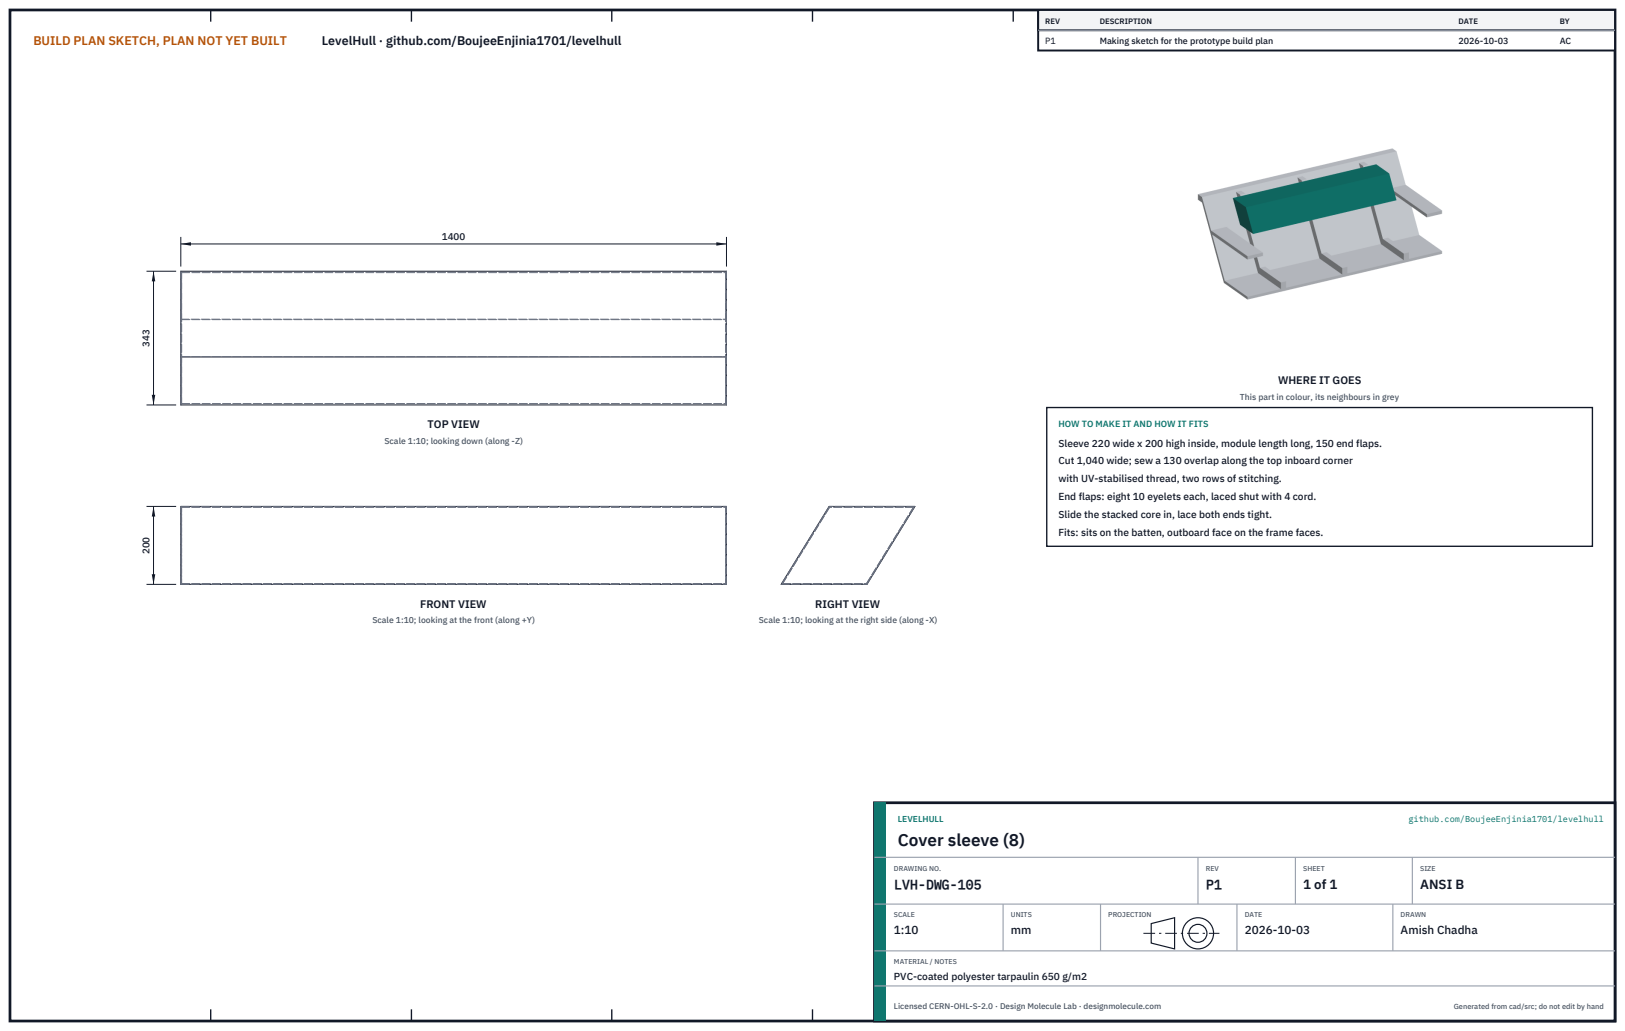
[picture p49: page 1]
BUILD PLAN SKETCH, PLAN NOT YET BUILT; LevelHull · github.com/BoujeeEnjinia1701/levelhull; FRONT VIEW; TOP VIEW; RIGHT VIEW; REV; DESCRIPTION; DATE; Making sketch for the prototype build plan; LEVELHULL; github.com/BoujeeEnjinia1701/levelhull; Cover sleeve (8); DRAWING NO. LVH-DWG-105; REV P1; SHEET 1 of 1; SIZE ANSI B; SCALE 1:10; UNITS mm; PROJECTION; DRAWN Amish Chadha; Licensed CERN-OHL-S-2.0 · Design Molecule Lab · designmolecule.com; Generated from cad/src; do not edit by hand

WHERE IT GOES

This part in colour, its neighbours in grey

HOW TO MAKE IT AND HOW IT FITS
Sleeve 220 wide x 200 high inside, module length long, 150 end flaps.
Cut 1,040 wide; sew a 130 overlap along the top inboard corner
with UV-stabilised thread, two rows of stitching.
End flaps: eight 10 eyelets each, laced shut with 4 cord.
Slide the stacked core in, lace both ends tight.
Fits: sits on the batten, outboard face on the frame faces.

Scale 1:10; looking down (along -Z)

Scale 1:10; looking at the front (along +Y)

Scale 1:10; looking at the right side (along -X)

MATERIAL / NOTES
PVC-coated polyester tarpaulin 650 g/m2

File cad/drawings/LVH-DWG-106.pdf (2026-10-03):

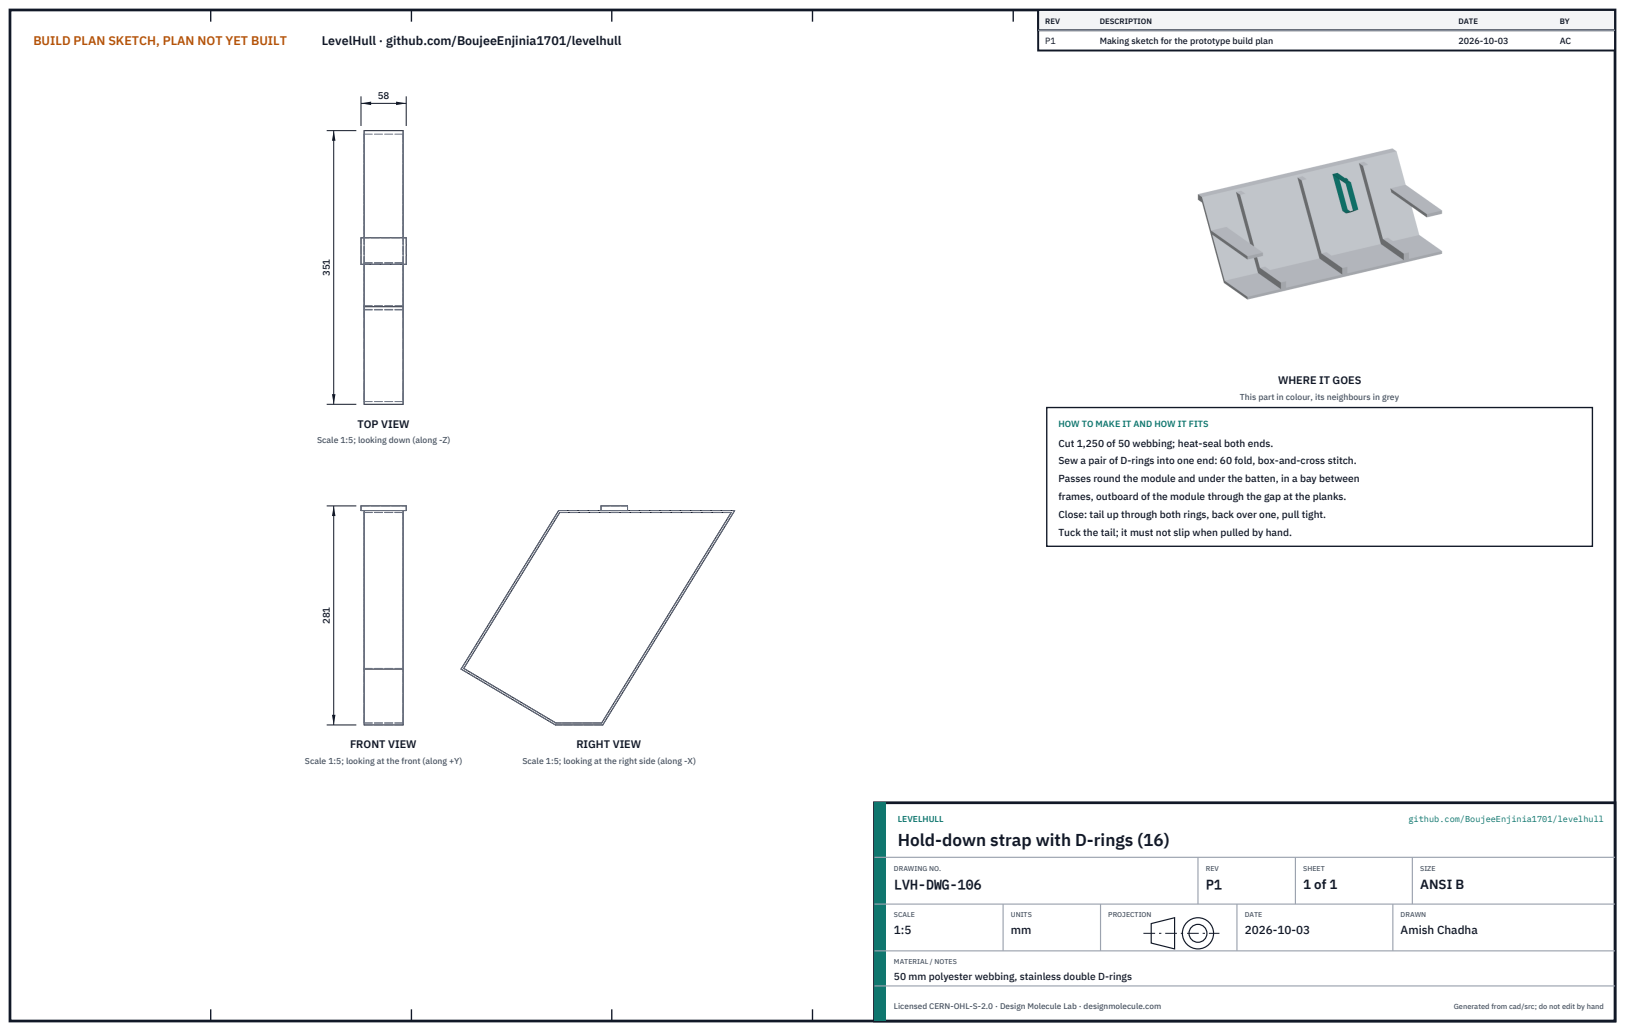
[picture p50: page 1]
BUILD PLAN SKETCH, PLAN NOT YET BUILT; LevelHull · github.com/BoujeeEnjinia1701/levelhull; FRONT VIEW; TOP VIEW; RIGHT VIEW; REV; DESCRIPTION; DATE; Making sketch for the prototype build plan; LEVELHULL; github.com/BoujeeEnjinia1701/levelhull; DRAWING NO. LVH-DWG-106; REV P1; SHEET 1 of 1; SIZE ANSI B; SCALE 1:5; UNITS mm; PROJECTION; DRAWN Amish Chadha; Licensed CERN-OHL-S-2.0 · Design Molecule Lab · designmolecule.com; Generated from cad/src; do not edit by hand

WHERE IT GOES

This part in colour, its neighbours in grey

HOW TO MAKE IT AND HOW IT FITS
Cut 1,250 of 50 webbing; heat-seal both ends.
Sew a pair of D-rings into one end: 60 fold, box-and-cross stitch.
Passes round the module and under the batten, in a bay between
frames, outboard of the module through the gap at the planks.
Close: tail up through both rings, back over one, pull tight.
Tuck the tail; it must not slip when pulled by hand.

Scale 1:5; looking down (along -Z)

Scale 1:5; looking at the front (along +Y)

Scale 1:5; looking at the right side (along -X)

Hold-down strap with D-rings (16)

MATERIAL / NOTES
50 mm polyester webbing, stainless double D-rings

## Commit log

2026-10-03 LevelHull at TRL 3: constructable design (kit 1.7.0)
    Problem, concept and requirements; sizing calculations; CAD model, STEP and STL; general arrangement drawing; bill of materials; build plan with making sketches, joint close-ups and step pictures; design decisions register (all decided under Amish's 2026-10-03 pre-approval); TRL 2 and TRL 3 review; photoreal renders and storefront card. Private until Amish opens it.
    [bom.csv, end-chock.step, end-chock.stl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]
2026-10-03 Carry Amish's 2026-10-03 requirement decisions into the design
    Amish chose option A on each requirement decision ("1A 2A 3A 4A 5A 6A 7A 8A 9A 10A 11A"). CampBreak: primed foot valve, pre-coupled suction hose and a drilled 30 s gather (R9 now 3.2 min at 100 m, me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
    [bom.csv, end-chock.step, foam-core-1-880mm.step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]
2026-10-28 Kit 1.9.1 upgrade: pipeline documents and detailed CAD for every option
    Kit 1.9.1 installed (.kit, CLAUDE.md, .claude/commands). Kit 1.8 pipeline: STEM check with fixes under the 2026-10-23 standing instruction, concept options with the current design as option A, URS, PRS, generated RTM, REG, FEA, RSK with design FMEA, MKT, PLN and DDR; kit 1.9 D3 model of every option passing cad/fidelity.json; independent review recorded in the STEM check. Amish's 2026-10-25 decisions recorded where he approved a recommendation; all others proposed, awaiting Amish. Product renders and the options picture follow in a later commit where not yet included.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
2026-10-29 Add Cycles product renders and the concept options picture
    Blender Cycles renders of the kit 1.9.1 model, rendered on Amish's Mac and captioned; media/options.png from the D3 option models (this also clears the failing docs check, which needs the picture); cards and PDFs rebuilt. The options picture labels option A as the current design unless project.yaml records Amish's choice.
2026-10-29 Add the concept options picture rendered from the D3 option models
    media/options.png from Blender Cycles panels of every option, rendered on Amish's Mac; the label reads CURRENT DESIGN unless project.yaml records Amish's choice. Clears the docs check, which needs th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

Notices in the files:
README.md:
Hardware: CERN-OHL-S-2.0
